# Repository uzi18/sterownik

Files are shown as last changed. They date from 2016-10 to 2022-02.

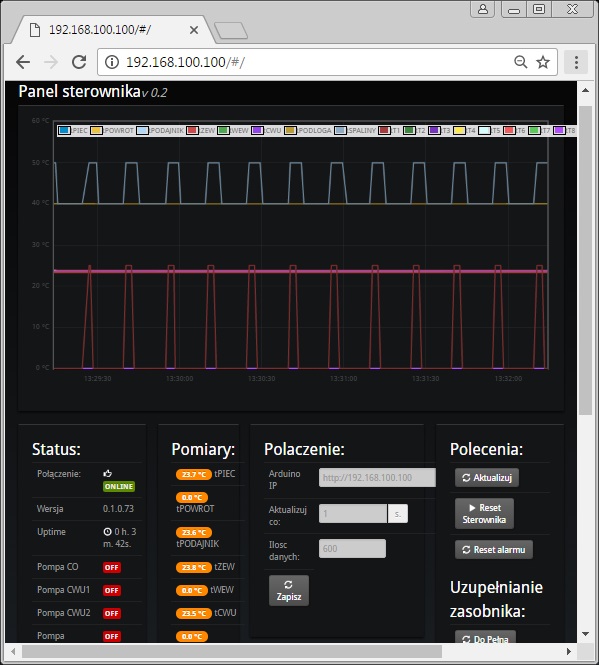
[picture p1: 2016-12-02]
arduino/img/pierwsze_uruchomienie/strona.jpg

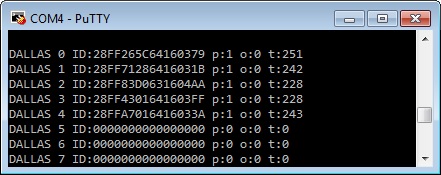
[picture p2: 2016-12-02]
arduino/img/pierwsze_uruchomienie/putty1.jpg

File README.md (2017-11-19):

## repozytorium zawiera: 

* Lucjan (katalog arduino) - sterownik pieca CO na bazie Arduino Mega w tym schematy, wsad i wiele innych
* skrypty w python dla eCoal.pl/bruli.pl dla nie wspierancyh juz sterowników

## Wszelkie błędy, propozycje zmian i dodatkowe funkcje zgłaszamy w [Issues](https://github.com/uzi18/sterownik/issues)
  * [Issues](https://github.com/uzi18/sterownik/issues) zgłaszane przez osoby wspierające Lucjana będą rozpatrywane z pierwszeństwem.  
  * Na [stronie wsparcia](https://www.paypal.me/wsparcieDlaLucjana) w uwagach prosze podawać nr. [issue](https://github.com/uzi18/sterownik/issues), którego sie tyczy.  
  
## Zapraszamy do dyskusji ONLINE - kliknij na link: 

## Podoba Ci się projekt, kliknij i wesprzyj Lucjana:

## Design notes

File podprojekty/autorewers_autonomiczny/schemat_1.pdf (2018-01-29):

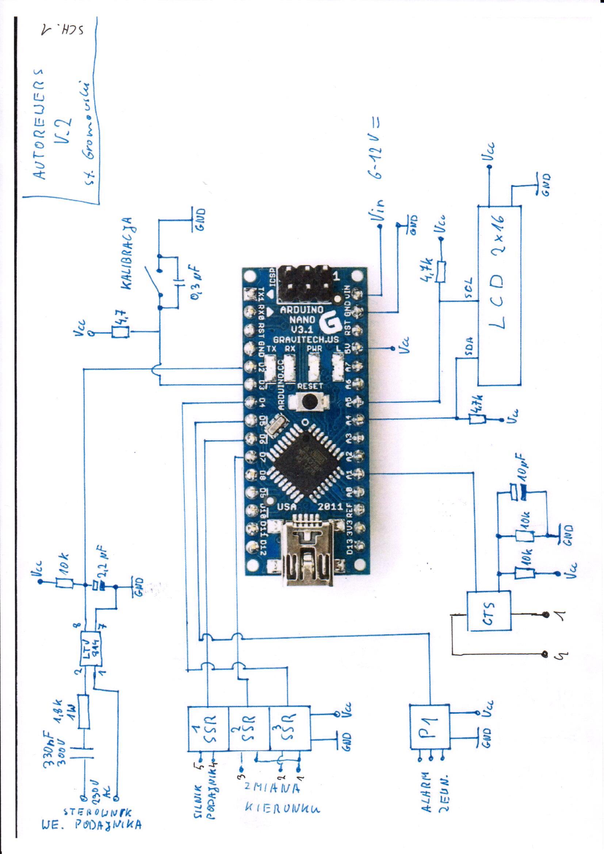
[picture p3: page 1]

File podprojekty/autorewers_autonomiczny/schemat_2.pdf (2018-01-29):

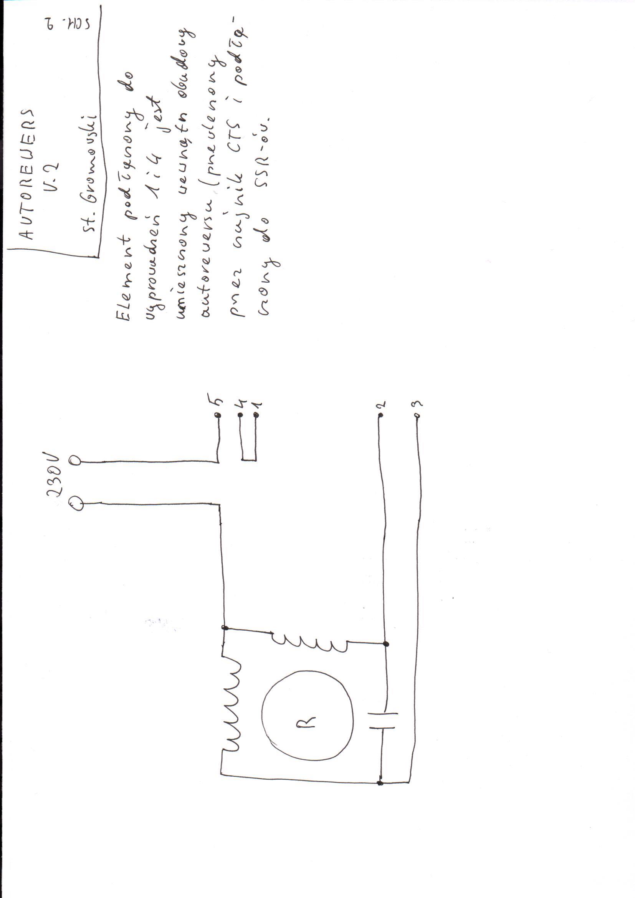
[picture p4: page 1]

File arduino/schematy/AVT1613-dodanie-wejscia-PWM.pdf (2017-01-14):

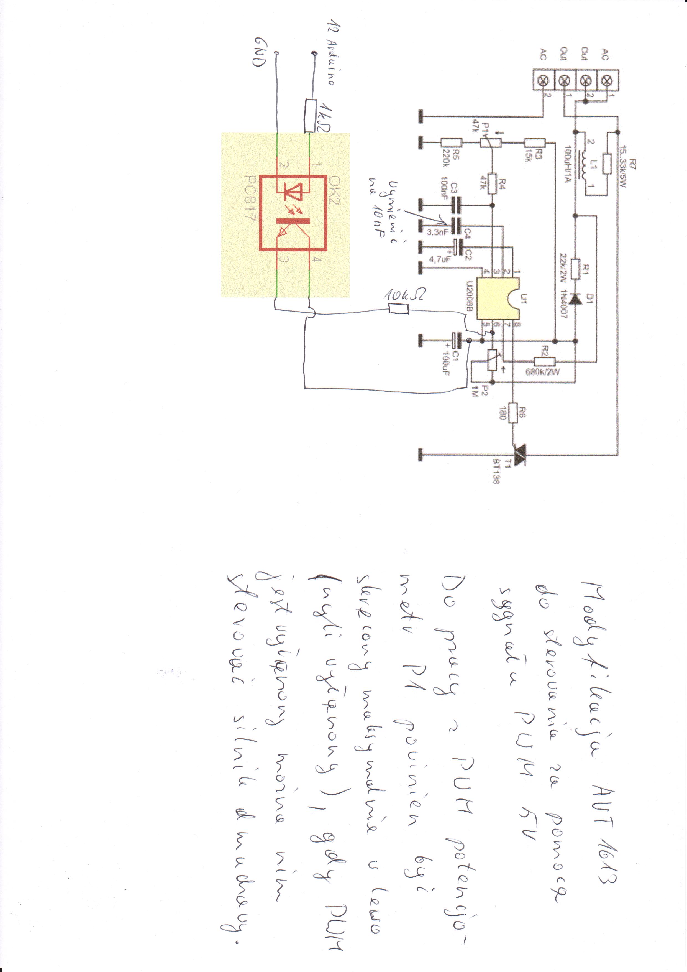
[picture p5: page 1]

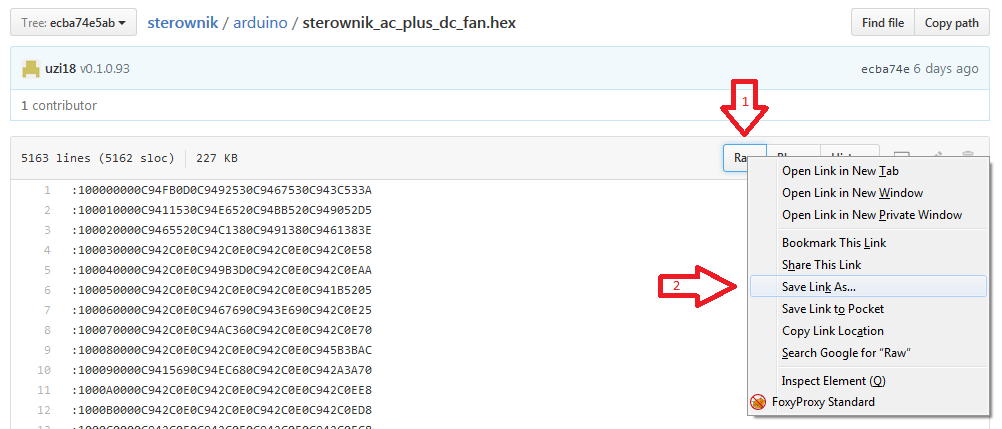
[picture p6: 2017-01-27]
arduino/img/pierwsze_uruchomienie/download_lucjan2.png

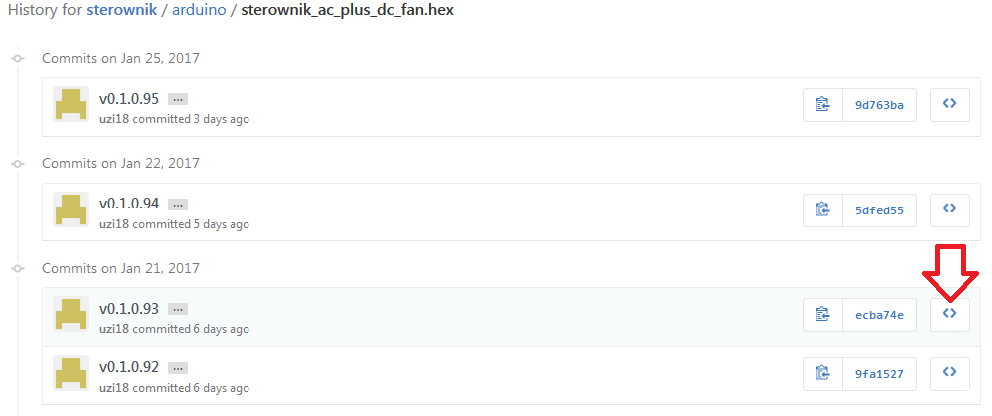
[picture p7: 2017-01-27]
arduino/img/pierwsze_uruchomienie/download_lucjan1.png

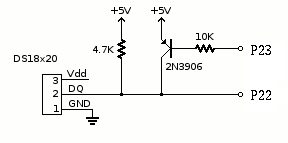
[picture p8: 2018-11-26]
arduino/dokumentacja/pics/1wire-aktywne_podciagniecie.png

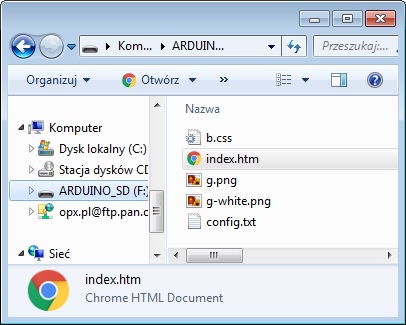
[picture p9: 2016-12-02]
arduino/img/pierwsze_uruchomienie/katalog.jpg

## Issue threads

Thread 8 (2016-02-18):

dmuchawa AC - moduły

uzi18, 2016-02-18:
dmuchawa AC sterowana moze byc poprzez optotriak i triak - wymagany jest tez detektor zera sieci
lub
zmodyfikowany modul avt-1613 (dostepny w sprzedazy) z wyjscia PWM
lub
modul avt-3113 (niedostepny w sprzedazy) z wyjscia PWM

bzykbzyk, 2016-02-20:
uzi18, jesteś pewny że avt-3113 nadaje się do sterowania silników asynchronicznych? Producent twierdzi, że przeznaczony jest do komutatorowych.

uzi18, 2016-02-25:
jestem pewny, w tym tygodniu przyjda płytki to zloze i sprawdze ale to jest praktycznie to samo co Stan zmontowal z 1613 i fragmentu z 3113 wiec nie ma innej mozliwosci

uzi18, 2016-09-12:
Podsumowując moje testy:
avt3113 - działa poprawnie : sygnał 0V-0% 5V-100%, mozliwosc regulacji minimalnych i maksymalnych obrotów oraz biegu jałowego, przy 100% obroty troszke pływają wiec warto zjechac troszke z obrotów maksymalnych potencjometrem na module

avt1613-zmodyfikowany wg Stan - działa poprawnie poza tym ze wymaga odwroconego sygnału (5V-0% 0V-100%) i u mnie na 0% dmuchawa sie nie potrafi zatrzymać.

triak-optotriak+detekcja zera - w trakcie testów

bzykbzyk, 2016-09-16:
avt3113 niestety niedostępny

uzi18, 2016-09-16:
Aktualizacja:

avt1613-zmodyfikowany wg Stan - działa poprawnie,
wg. mnie kiepskie mozliwosci regulacji wzgledem 3113, prawdopodobnie mozna to jeszcze dopracowac
wczesniej zle dzialala bo u2008b mialem w podstawce,  najlepiej przylutowac go bezposrednio do plytki

avt3113- jest niedostepna i producent nie ma zamiaru jej wznowic do sprzedazy

mark3k3, 2016-09-18:
Ogólnie, moduł AVT1613 działa dość poprawnie, jednak PWM nie może wysterować wentylatorem na MAX. MAX obroty nie są nam potrzebne, dlatego takie wykonanie modułu wykonawczego sterowania dmuchawą jest jak najbardziej akceptowalne i przydatne.

bzykbzyk, 2016-10-01:
Dla dmuchawy nie jest potrzebne 100%, ale już np dla pompy tak.
Chciałbym w przyszłości wykorzystać Lucjana również do sterowania panelami słonecznymi i obrotami pompy: w zależności od różnicy temperatur przed i za panelami. Muszę zbudować układ na wzór avt3113, skoro lepiej steruje.

uzi18, 2016-10-01:
Moze dla pompy zakres regulacji na avt1613 tez wystarcza.

W dniu 1 października 2016 19:43 użytkownik bzykbzyk <
notifications@github.com> napisał:

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

bzykbzyk, 2016-10-01:
Muszę zatem zbudować jakieś stanowisko do pomiaru obrotów pompy i sprawdzić jak się zachowuje. Nawet jak by nie było max 100%, można w ostateczności zewrzeć regulator stykiem przekaźnika.

uzi18, 2016-10-01:
Mozna ustawic/wyregulowac plytke 1613 aby byl zakres od 40%-100%.

uzi18, 2016-10-06:
Moge potwierdzic ze swojej strony ze dmuchawka AC sterowana
bezposrednio z Lucjana w  konfiguracji - detektor zera, optotriak, triak - smiga az milo ...

bzykbzyk, 2016-10-07:
Mój piec na razie w gotowości do palenia. Przestawiam trochę szpeje w kotłowni więc brak czasu. Czekam na moduł triaków.
Skoro 1679 działa zadowalająco (w całym zakresie obrotów?) to rezygnujemy z 1613?
Dlaczego sterujesz triakami z wyjść analogowych a nie cyfrowych (dmuchawa - wiadomo)?
Uaktualniłem schemat (bez przekaźników na razie, info w wątku o przekaźnikach).

uzi18, 2016-10-08:
Jezcze troche i zrobimy porzadki z wyjsciami.
Wyjscie na opto to jakiekolwiek zwykle wyjscie cyfrowe.

Czekam na wasze testy z moc3020, na razie nikt nie potwierdzil poprawnej
pracy, a 1613/3113 jest dobra alternatywa.

bzykbzyk, 2016-10-08:
Przy porządkowaniu wyjść, rozpatrz przeniesienie gdzieś sygnałów DO i CLK termopary, dla triaków "cyfrowych" można by przeznaczyć wyjścia 46 -55 - zrobić kabelek 10 żyłowy (wtyk - gniazdo) kanda -  pewnie i prosto podpiąć moduł triaków (nie przerabiany) do mega jedną taśmą. W tej chwili wykorzystujemy już 8 wyjść do sterowań, lada chwila trzeba dołożyć kolejny moduł triaków. Jakaś pompa np do solarów też ładnie by hulała ze zmienną prędkością zależną od temp.

ravikjab, 2016-10-11:
uruchomiłem dmuchawę na MOC3020 i po wstępnych testach praca dmuchawy WPA01 jest wielce obiecująca. Jest większa moc względem AV1613. Dmuchawa w trybie modulacji bez problemów zmienia predkość.
Więcej informacji przekaże po dłuższych testach.

uzi18, 2016-10-18:
ktoś jeszcze testował?

uzi18, 2016-11-05:
v0.1.0.66
        - sterowanie triakiem dmuchawy (A13) zdublowane na pin 32

Docelowo będziemy musieli przenieść się z pinów Ax (zwłaszcza dmuchawa)z prostej przyczyny - procesor ma jakiś bug powodujący zakłócenia na wyjściach przełączanych z "wysoką" częstotliwością.

Tym samym czekam na potwierdzenie ze dmuchawa sterowana optotriak/triak działa już
poprawnie po podłączeniu pod pin 32.
A13 z czasem ... będzie to testów czujników np. KTY81-210.

mark-markowski, 2016-11-06:
Potwierdzam prawidłowe działanie dmuchawy na pinie nr. 32. Modulacja działa płynnie i precyzyjnie.

uzi18, 2016-11-27:
Rozumiem,że działa więc zamykam.

Closed 2016-11-27.

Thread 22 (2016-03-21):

detekcja przeciążenia silnika podajnika

bzykbzyk, 2016-03-21:
Pomiar prądu silnika podajnika - przeciążenie - włączenie pracy nawrotnej

uzi18, 2016-03-21:
zrobimy testy na ACS712 w wersji 5A, moze uda sie wylapac tez zerwanie zawleczki

Stan17, 2016-04-15:
Testy zrobione, ACS712 i AC-MAX-30A, zerwanie zawleczki jest raczej nie do wykrycia ale przeciążenie na pewno tak.

bzykbzyk, 2016-04-17:
AC-MAX-30A ma jakąś elektronikę? Czy to tylko transformator i na wyjściu prąd zmienny do wykorzystania? Jakieś schematy do wrzucenia?

uzi18, 2016-04-17:
Ma rezystor i diody zabezpieczajace na wyjsciu trafa, wykonania sa rozne.

bzykbzyk, 2016-04-17:
uzi18
Ha, czujny jesteś. Napisałeś odpowiedź na moje pytanie o konstrukcji AC-MAX-30A, które po kilku minutach usunąłem bo znalazłem ją w sieci. Skoro twierdzisz że są różne wykonania, to nie jest dobrze. To utrudnia unifikację. Może sam coś zbuduję. Te 30A wydaje mi się za dużo do  naszego zastosowania, skoro mamy mierzyć prądy w okolicach 1A. 30 amperowe mają przekładnię 1800:1 muszę zrobić przekładnik o mniejszym przełożeniu. Widzę też w sieci 5, 10, 15A
Stan17,
dlaczego twierdzisz, że zerwanie zawleczki nie do wykrycia? Przecież to musi być większy prąd niż przeciążenie.
W jakim układzie to testujesz? Daj go, zbuduję to samo i sprawdzę

uzi18, 2016-04-17:
Efekt na kazdym czujniku jest ten sam, one sie glownie rezystorem roznia, w zaleznosci od pradu, kalibracje najpewniej i tak kazdy bedzie musial zrobic

Stan17, 2016-04-18:
Dlaczego tak myślę ? Ponieważ kiedyś to zmierzyłem i różnica między prądem normalnej pracy a prądem pracy z odłączonym ślimakiem wynosiła około 0,1 A.

Tu masz przykład którym się posłużyłem.
http://akademia.nettigo.pl/power_meter/

micro-jr, 2016-04-18:
nie prościej w okolicach zawleczki zamontować jakiś czujnik obrotu ślimaka?
silnik chodzi, czujnik kręci - OK
silnik chodzi - czujnik nie kręci - zerwana zawleczka
silnik nie chodzi, czujnik nie kręci - OK
silnik nie chodzi, czujnik kręci - ??

Stan17, 2016-04-18:
Ale głównym celem nie jest wykrycie zerwania zawleczki, to tylko dodatek.
Podstawową sprawą tutaj jest wykrycie przeciążenia zanim zostanie zerwana zawleczka, wykonanie ćwierć/pół obrotu ślimaka wstecz i powrót do normalnych obrotów.

micro-jr, 2016-04-18:
no to pytanie jaki jest pobór podczas przeciążenia, a nie pracy bez zawleczki.
bo jeśli do ścięcia zawleczki potrzeba 0,1A więcej, to słabo to widzę... chociaż z drugiej strony, pewnie, przed zerwaniem zawleczki, obroty silnika mocno spadają - a zatem po ilości obrotów (silnika, a nie ślimaka) można by reagować  - jeśli podajemy prąd, a ilość obrotów gwałtownie spadła to mamy awarię.

uzi18, 2016-04-18:
Nie o to chodzi, ten czujnik daje nam wiecej informacji, ktore odpowiednio
analizujac mozemy dobrze wykorzystac

Stan17, 2016-04-18:
Ale ja nie to napisałem.
To oczywiste że do ścięcia potrzeba o wiele większego prądu.
Chcemy wykryć przeciążenie i zareagować zanim nastąpi ścięcie zawleczki.

Chodzi mi o to że tak mała różnica między prądami pracy z zawleczką i bez, nie pozwoli nam w sposób absolutnie pewny stwierdzić czy po wzroście prądu w przeciążeniu i jego nagłym spadku podajnik pracuje z zawleczką czy bez.

bzykbzyk, 2016-04-20:
Mierzenie obrotów silnika (w celu detekcji ścięcia zawleczki) jest moim zdaniem bezcelowe, bo z uwagi na duże przełożenie przekładni spadek obrotów będzie (raczej) minimalny. Wszystkie występujące na rynku podobne układy bazują na pomiarze prądu silnika. Widziałem układ z pomiarem różnicy obrotów pomiędzy ślimakiem a reduktorem (czujnik Halla plus magnesy). Jeśli różna od 1 = ścięta zawleczka.  Był to układ tylko do detekcji ścięcia. Tylko po co taka wiedza (za parę stów - bo tyle tamten kosztował)? Skoro sterownik podaje sterowanie na silnik a temperatura nie rośnie to znaczy, że brak paliwa lub zerwana zawleczka. Jedno i drugie wiąże się z wizytą w kotłowni.
Cała zabawa w tym wątku ma zakończyć się budową układu detekcji przeciążenia (zablokowania) podajnika grożącego uszkodzeniem szpejów wartości co najmniej tysiaka a nie zawleczki wartej ćwierć złocisza.
Jeśli uda się zbudować skuteczny układ, to z czystym sumieniem wymienimy zawleczki na utwardzone śruby ponieważ rola zawleczki zostanie przejęta przez ten układ. Takie rozwiązanie jest stosowanie przez kilku producentów "elektronicznych zawleczek".

**uzi18,**
Dopiszże w wolnej chwili kawałek kodu do pomiaru prądu układem ACS712 5A z wizualizacją na wykresie (łatwiej będzie analizować pracę podajnika).

uzi18, 2016-04-20:
Stan tez o to prosil, aby dopisac jakis kod do tego czujnika, zobacze co da sie zrobic.

micro-jr, 2016-04-21:
Jeżeli silnik jest w trybie pracuj, ale się nie obraca - znaczy ze doszło do zacięcia.
czy silnik ma pracować wiemy - bo to My decydujemy.
pozostaje wykryć, czy silnik/Przekładania się obraca.

zakładając, ze silnik obraca się szybciej niż podajnijk i jesteśmy w stanie określić z jakimiś interwałem o ile się obraca, jeśli w zadanym czasie obrót nie nastąpił, a silnik pracował - mamy zacięcie silnika.

nie wiem jaka jest czułość czujników obrotu "za 30 pln" i czy da się taki założyć przed przekładnią, bo tam są większe obroty - szybciej powinna nastąpić zmiana - mamy mniejsze opóźnienie.

Stan17, 2016-04-21:
Na połaczeniu  silnika z motoreduktorem nie ma gdzie go zamontować, jedyne miejsce to wykrycie obrotu wentylatora silnika.
Jeśli chcesz to próbuj takiego rozwiązania, ja jednak pozostanę przy wykryciu przeciążenia :-)

uzi18, 2016-04-21:
Panowie przetestujmy wpierw jedno rozwiazanie z czujnikiem pradu, pozniej sie zastanowimy czy jest wystarczajace.

Moim zdaniem czujnik śruby na ślimaku daje za rzadko informacje o obrocie, zakładając ze kilka sekund na cykl podawania to tez mało na 1/2 lub cały obrót ślimaka.

My chcięlibyśmy mieć informacje z wyprzedzeniem zanim zetniemy zawleczkę, a pozniej zareagować kilkusekundowa zmiana obrotów silnika.

bzykbzyk, 2016-04-28:
Mój ślimak wykonuje 10 obrotów w czasie 8min. Silnik (wg tabliczki zn) - 1430 obr/min. Daje to przełożenie ok 1150:1.
Moim zdaniem nawet po zablokowaniu ślimaka spadek obrotów silnika będzie minimalny, raczej nie mierzalny domowymi sposobami.

Ostatnio chciałem zmierzyć przyrost prądu silnika po obciążeniu (zablokowaniu) ślimaka.
Mam sprawny układ testowy: silnik z przekładnią zdemontowany z pieca przeznaczonego na złom. Ślimak ucięty szlifierką, ponieważ została ścięta zawleczka i przekładnia "zblokowała się" ze ślimakiem. Przygotowałem szlifierką "kikut" ślimaka, by pasował do klucza płaskiego 22. Założyłem klucz tak, aby po kilku sekundach obrotu zablokował się opierając o korpus, podłączyłem arduino z ACS712 5A. Z uwagi na brak zawleczki sądziłem, że klucz na kikucie ślimaka będzie wystarczający do przezwyciężenia blokady z przekładnią.
Wyniki:
Prąd max > ok 10% od znamionowego.
Na szczęście stałem poza trajektorią przelotu części klucza.
Szkoda tylko zniszczonego klucza vanad (miałem jeszcze zwykły, stalowy, mogłem użyć jego...).

Wnioski:
Układ przeciążenia trzeba testować podczas normalnej pracy napędu, z zawleczką fabryczną.
Rejestrować przeciążenia, czekać na zerwanie zawleczki. Odczytać wartości zarejestrowane w czasie zerwania, ustawić kilka % niższą, jako wyzwalającą układ do pracy nawrotnej.

ACS712 5A nie jest zbyt precyzyjny. Z uwagi na charakter pomiaru (cz Halla) nie jest odporny na zakłócające pole magnetyczne.
Program w arduino z którego korzystam podczas obciążenia wskazuje podobny prąd do zmierzonego przyrządem, a bez obciążenia to 0,25-0,3A. Bez sensu.
Proszę o kod z którego Wy korzystacie, może tu jest przyczyna?

uzi18, 2016-09-08:
Jestem na etapie składania modułu pomiarowego, niebawem dam znac jakie efekty :)

uzi18, 2016-09-18:
Mysle ze bedzie wybor miedzy termometrem silnika a modulem pomiaru obciazenia.
bzyk: jak mozesz to wrysuj detektor zera sieci za bezpiecznikiem od peryferiow ...
bedzie dzieki temu zarazem detektorem przepalenia bezpiecznika :)

bzykbzyk, 2016-09-19:
Za bezpiecznikiem AVT1679? Mogę wrysować, ale czy da się to fizycznie wykonać?

uzi18, 2016-09-19:
U siebie przylutowalem przewod za bepiecznikiem

bzykbzyk, 2016-09-19:
Ok, wrysuję mostki zamiast bezpieczników i jeden wspólny do wszystkiego prócz zasilacza.

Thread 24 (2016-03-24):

Wyjścia sterujące przekażnikami

bzykbzyk, 2016-03-24:
Przydała by się wersja programu sterująca modułem przekaźników zamiast triaków ew
mogą to być dodatkowe wyjścia z odwróconą polaryzacją bo popularne moduły wymagają sterowania wysokim poziomem.
Albo zmienna w programie zmieniająca poziom na poszczególnych wyjściach.

uzi18, 2016-03-24:
pokaz co to za moduly - link?

bzykbzyk, 2016-03-25:
Etam będę Ci linkował, obrazki pokażę. Występują pod nazwą "moduł przekaźnikowy arduino" od jednego do ośmiu, z optoizolacją.
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

Stan17, 2016-03-25:
Nie wiem czy przekaźniki to dobry pomysł, to jest dość zawodny element.

uzi18, 2016-03-25:
Ale te przekazniki maja styk NO i NC wystarczy ze obciazenie podlaczysz do drugiego i bedziesz mial odwrocony sygnal na wyjsciu

micro-jr, 2016-03-25:
Nie odwrócony. Tylko normalnie zwarty lub normalnie otwarty. Jeśli potrzebujesz żeby coś chodziło przez 90% czasu to lepiej sterować wtedy czasem wyłączenia. W piaszczysta wtedy t a ka rzecz w normalnie zwarty. A w sterowniku ustawiasz jako aktywny port 0 wówczas jest to zwarte kiedy przekaźnik nie pracuje.podanie jedynki na sterowniku zmieni stan przekaźnika na prace i rozewrze obwód. Oszczędza to przekaźnik.

Pokazane na zdjęciu układy to opto przekaźniki.  Ich zaletą jest izolacja galwaniczna obwodów. Jeśli nie ma błędu ma płytce zwiększa odporność systemu na przecięcia.

bzykbzyk, 2016-03-25:
Przekaźniki może i zawodne, ale kilka razy zdarzyło mi się, że po zwarciu nawet styki się nie zgrzały a triak to kosz.
Nie można korzystać z NC styku, bo po wyłączeniu sterownika z jakiegokolwiek powodu (choćby reset) wszystkie obwody zostaną zasilone, co np dla zaworu 4d może być zabójcze.

uzi18, 2016-03-25:
Dlatego przed triakami daje sie bezpiecznik :)

bzykbzyk, 2016-03-27:
Bezpiecznik nawet szybki nie zabezpiecza w 100% triaka. Nieraz zadziałał bezp i triak kosz.

uzi18, 2016-03-27:
Przed wszystkim sie nie zabezpieczysz niestety.

Stan17, 2016-03-27:
Nie wiem jak wy, ale ja wolę w razie awarii wymienić triaka niż przekaźnik wlutowany.
Ale co kto woli :-)

uzi18, 2016-03-27:
Bzyk pozwol ze na razie zajme sie rozwinieciem tego co juz mamy, temat dopisze do ulepszen, na ten czas mozna zastosowac sprzetowa inwersje, moze znajdziesz gotowy modul?

Dodanie inwersji w tym momencie komplikuje troszke sprawe, bo mamy kilka innych problemow do rozwiazania.

Dodaje temat do ulepszen, zgloszenie zostawiam otwarte

uzi18, 2016-03-27:
Mozna tez sprobowac w prosty sposob przerobic modul przekaznikow aby sygnal nie musial byc odwracany ...

uzi18, 2016-03-27:
#232d8548631ae3c2d7efac8581f78b6af6d77a82

uzi18, 2016-03-27:
dodane w 0.1.0.39 - prosze o testy

bzykbzyk, 2016-03-29:
Dziękuję za wersję dla przekaźników. Pewnie, że można by te moduły przerobić, ale kłóciło by się to z zasadą, aby korzystać jak najbardziej z gotowych rozwiązań.
 Z uwagi na połączenia, dobrzy by było zaprogramować parzyste wyjścia sterujące 24, 26, itd.

uzi18, 2016-03-29:
parzyste naprawde cos dadza, bo nie wiem jak to rozumiec?

Mozesz dorysowac na schemacie modul rtc "ds1307+24c32", podlaczone vcc,gnd,scl,sda

bzykbzyk, 2016-03-29:
Chodzi o podłączenie do pinów arduino elementów wykonawczych i czujników. Można użyć "Złącze ARK do płytki stykowej", ma wyprowadzenia gold pinów w jednym rzędzie. A to właśnie parzyste piny 22 - do DS oraz 24, 26 itd do przekaźników. Docelowo (jeśli to nie byłby problem) lepiej by było wykorzystać jednak już te od triaków, (coby nie dublować wyjść) zmieniając im tylko polaryzację (może jakieś zmienne do ustawienia w config).
Jeśli chodzi o moduły przekaźnikowe, to gapa ze mnie, występują też sterowane wysokim potencjałem.
Schemat uaktualnię.

uzi18, 2016-03-29:
To fajny pomysl z tymi zlaczami jednak jest to dosc ograniczone jesli chodzi o mozliwosci podlaczenia, za to wydaje mi sie ze widzialem gdzies gotowce na cala plytke ...

bzykbzyk, 2016-03-29:
Są na całą Mega, ale nie miałem tego w łapkach, więc trudno określić czy się nada.
Niestety Lucjan w tej chwili na biurku, jestem na etapie szycia mu nowego garnituru, czyli obudowy.
Czekam na gniazda C13, moduł pomiaru prądu nie może dotrzeć (przesilenie na poczcie), regulator ac dmuchawy czeka na złożenie, i ... trochę mało czasu, więc wszystko opornie idzie. Każdy nowy wsad testuję na biurku, symulacja pieca to lampa biurkowa i zapalniczka. Od kilkunastu dni w ruchu, pracuje stabilnie. Nie grzeję cwu węglem (na razie - w planie zasobnik samoróbka, szukam zbiornika hydroforowego z demobilu) więc z uwagi na temperatury zewnętrzne piec wygaszony.

uzi18, 2016-03-29:
dopisalem troche rzeczy do wiki ...

bzykbzyk, 2016-03-30:
Ta płytka to do testów jedynie. Niestety nie ma wyprowadzonych zacisków śrubowych na D22 do D53

uzi18, 2016-03-30:
Ma za to pola gdzie mozna takie lub inne zlacze przylutowac

bzykbzyk, 2016-03-30:
No niestety, nie jest to takie proste, bo złącze śrubowe typu ARK ma raster 5mm a w Arduino jest 2,5mm, stad moja propozycja  "Złącze ARK do płytki stykowej"

uzi18, 2016-03-31:
Ok, uwolnie teraz zlacza analogowych wejsc i zrobimy na parzystych od 24 stan niski aktywny a na nieparzystych wysoki aktywny, chociaz to marnotrastwo ale na razie musi tak byc.
Miałem plan aby 24-55 uzyc do innych celów.

bzykbzyk, 2016-04-01:
Nie można by nie dublować, ale z użyciem parametrów w config załatwić sprawę? Wiadomo, że kawałek kodu musiałbyś skrobnąć i nie musi być to od razu.
Na schemacie jeszcze nie wszystko ok, wejścia sterujące przekaźników trzeba spolaryzować do plusa.
Jakiś duży mi ten plik teraz wyszedł...
Znalazłem schield do Mega z rozszyciem D24-50 na śrubowe,
[https://www.tindie.com/products/duanebenson/universal-screw-block-proto-shield-system-for-arduino/](url)
lub
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

ale cena zabójcza. Muszę coś innego wymyślić np w oparciu o płytkę uniwersalną.

ravikjab, 2016-09-22:
Zauważyłem chyba błąd w sterowaniu gdyż przy ustawieniu TPIECA na 50 st i histereza na 2 st. to przy spadaniu temp podajnik właczył się przy 47,9 st (czyli prawidłowo), natomiast gdy temp rosła to już po przekroczeniu 48 st podajnik przestał się właczać a powinien pracować do uzyskania nastawionej temperatury 50 st.
W tym momencie korzystam z przekaźników.

uzi18, 2016-09-22:
Dodalem to jako błąd, do weryfikacji.

uzi18, 2016-09-25:
Dodalem nastepne wyjscia dla przekaznikow w wersji v.0.1.0.47

bzykbzyk, 2016-10-07:
Uwolnij wyjścia cyfrowe 24 - 30. Nie ma sensu sterować przekaźnikami stanem niskim, skoro są dostępne moduły sterowane wysokim a nawet mające możliwość konfiguracji stanu przełączania (załączenie przekaźnika wysokim lub niskim).
Jak ktoś będzie chciał jednak przekaźniki, może je włączyć zamiast triaków.
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.

uzi18, 2016-10-08:
Ok przemyslimy sprawe, kto uzywa jeszcze zwyklego modulu przekaznikow?

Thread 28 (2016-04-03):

Uwagi do www

bzykbzyk, 2016-04-03:
Błędnie opisany poziom zasobnika. Jest "Poziom podajnika".
Po dodaniu paliwa, ilość w "Poziom podajnika" się nie zwiększa, tzn wygląda jakbyśmy zasypywali pusty zasobnik.
Ile to jest "Do pełna"?. Są różne zasobniki.

Można ustawić "Aktualizuj co:" jako liczbę ujemną.

Stan17, 2016-04-03:
U mnie poziom się zwiększa lub zmniejsza zależy ile "wsypię", zasyp działa inaczej niż w sterach ES, tzn gdy wpisujesz ile kilogramów to nie oznacza ile wsypałeś tylko ile masz w zasobniku czyli łączna ilość to co wsypałeś plus to co tam ewentualnie zostało.

Do pełna określasz w configu
> #czas w sekundach potrzebny do oproznienia pełnego zasobnika
> PODAJNIK_CZAS_DO_OPROZNIENIA = 69000

Ale w konfigu jest niekonsekwencja, w opisie mamy to usunąć
> #aktualny czas pozostaly do oproznienia zasobnika w sekundach
> #po uruchomieniu zliczamy od tej wartosci (domyslnie 50% zasobnika)
> PODAJNIK_CZAS_PODAJNIKA = 34500
A w aktualnym konfigu ciągle to jest.

uzi18, 2016-04-03:
Podajnik_czas_podajnika sluzy teraz tylko do ustawienia wartosci poczatkowej, generalnie nie ma potrzeby tego uzywac i niebawem chyba to wyrzuce.
Pozostawienie tej linijki spowoduje ze po resecie czas znow bedzie wpisany taki jak w parametrze a raczej tego noe chcemy ;)
Dosypywanie zrobie, moze nawet dzis.

bzykbzyk, 2016-04-03:
A o co tu chodzi:
> Jeśli ustawię czas podawania na 10, to po "Zasypano" 100kg
mam "Poziom podajnika" 869,6%,
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
a po ustawieniu czasu na 200 - to samo 100kg daje "Poziom podajnika" 54,3%
(teraz 43%!)
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

>Można ustawić "Aktualizuj co:" jako liczbę ujemną.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

uzi18, 2016-04-03:
Pokaz zawartosc pliku config.txt

bzykbzyk, 2016-04-03:
#czas w sekundach potrzebny do oproznienia pe�nego zasobnika
PODAJNIK_CZAS_DO_OPROZNIENIA = 69000
#aktualny czas pozostaly do oproznienia zasobnika w sekundach
#sta�a zalezna od opa�u w g./min.
PODAJNIK_PREDKOSC_PODAWANIA =200
zabezpieczenie przed zbyt wysoka temperatura pieca
KOCIOL_T_MAX = 90

temperatura zalaczenia pomp
PIEC_T_MIN = 0

tryb pracy pieca (palnika) - zgodny z ECOAL,RR,RRM,...
PIEC_ALGORYTM = RR
PIEC_ZADANA = 70
PIEC_HISTEREZA = 2

parametry algorytmu RR, czas podtrzymania w minutach, reszta w sekundach:
RR_PODTRZYMANIE_CZAS = 10
RR_PODTRZYMANIE_PODANIE = 10
RR_PODTRZYMANIE_POSTOJ = 30
RR_PODTRZYMANIE_MOC = 40

RR_PRACA_PODANIE = 2
RR_PRACA_POSTOJ = 5
RR_PRACA_MOC = 23

tryb pracy pompy co (ECOAL,BRULI,ZIMA,LATO)
CO_TRYB = ZIMA
algorytm pracy pomy CO (CIAGLY,CYKLICZNY)
CO_ALGORYTM = CIAGLY

tryb pracy pompy cwu (ECOAL,BRULI,WLACZ,WYLACZ)
CWU_TRYB = WYLACZ
algorytm pracy pomy cwu (CIAGLY,CYKLICZNY)
CWU_ALGORYTM = CIAGLY
CWU_ZADANA = 40
CWU_HISTEREZA = 0

bzykbzyk, 2016-04-04:
Już zaskoczyłem, gdzie popełniam błąd.
W obydwu przypadkach zmiany parametru PODAJNIK_PREDKOSC_PODAWANIA miałem tą samą wartość PODAJNIK_CZAS_DO_OPROZNIENIA. Nie zrozumiałem co to za parametr PODAJNIK_CZAS_DO_OPROZNIENIA, a to przecież pojemność zasobnika przeliczona na sekundy pracy podajnika.
Moim zdaniem, ten parametr powinien być wyliczany przez program a nie wprowadzany ręcznie.
Powinno się podać pojemność zasobnika w kg z instrukcji pieca (albo z doświadczenia - wsypując węgiel do zasobnika) i zmierzoną wartość parametru PODAJNIK_PREDKOSC_PODAWANIA.
Chociaż może niepotrzebnie kombinuję, niech Programista zdecyduje.

Brakuje mi za to na stronie czasu pracy do końca paliwa w zasobniku.

Stan17, 2016-04-04:
Ja podorabiamy różne statystyki to pewnie tak, na razie nie mamy praktycznie żadnych.
Wczoraj właśnie rozmawialiśmy na temat zrobienia pierwszej prostej statystyki zużycia dobowego węgla w okresie 7 dni.
Z tą sprawą nie ma to żadnego związku ale stanowiłoby pierwszy krok do utworzenia statystyk.

uzi18, 2016-04-06:
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

bzykbzyk, 2016-04-07:
Tak, teraz to już ładnie i czytelnie. Jakoś nie mogę uwierzyć w te 8,7kg na dobę Stan'a....

Stan17, 2016-04-07:
To jest wartość chwilowa, zaraz po uruchomieniu,  najpierw jest bardzo wysoka a po chwili spada mocno i dopiero po kilku godzinach pracy się stabilizuje, teraz mam około 11-12 kg

ravikjab, 2016-09-21:
Do interface www:
- przydałoby się żeby wyświetlane były ustawione wartości parametrów np. TPIEC, TCWU, TPODAJNIKDo
- możliwość określenia na wykresie czasu prezentacji wyników (ostatnie 10 min daje słaby obraz tego co działo się np z CWU a dzięki temu można poszukać oszczędności np przez określenie czasu pracy pompy cyrkulacyjnej włączając ją wtedy gdy faktycznie jest potrzebna)

uzi18, 2016-09-21:
Probowales zmienic czestotliwosc odswiezania "aktualizuj co" na 60?

ravikjab, 2016-09-21:
Ok jest lepiej ale i tak fajnie było by gdyby można określić zakres który nas interesuje bez utraty dokładności

Stan17, 2018-02-08:
Myślę że na www kontrolki wentylator i wentylator_mod bardziej pasują do bloku status niż pomiary ?

uzi18, 2018-02-08:
racja, mozna je przeniesc :)

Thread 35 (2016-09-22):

RR: problem z histereza przy paleniu

uzi18, 2016-09-22:
Zauważyłem chyba błąd w sterowaniu gdyż przy ustawieniu TPIECA na 50 st i histereza na 2 st. to przy spadaniu temp podajnik właczył się przy 47,9 st (czyli prawidłowo), natomiast gdy temp rosła to już po przekroczeniu 48 st podajnik przestał się właczać a powinien pracować do uzyskania nastawionej temperatury 50 st.

uzi18, 2016-09-23:
faktycznie to jest do poprawki

uzi18, 2016-09-23:
poprawione w #d73161670b15a94e1a202113f096e97f53496d42

ravikjab, 2016-09-24:
nie wyłącza się podajnik i dmuchawa pomimo przekroczenia ustawionej tPIEC.

uzi18, 2016-09-25:
wklej tutaj swoj config.txt

uzi18, 2016-09-25:
naprawione w v.0.1.0.47

Closed 2016-09-25.

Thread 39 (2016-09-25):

Buzer awarii

ravikjab, 2016-09-25:
Należy dodać zewnętrzny buzer do alarmów przekroczonej tPODAJNK, pustego zbiornika, uszkodzonego któregoś czujnika oraz awarii napędu podajnika. Różne częstotliwości dla różnych awarii by bez logowania szybko móc zlokalizować awarie

ravikjab, 2016-11-02:
Dodać wyjście na buzer podczas awarii.

uzi18, 2016-11-03:
dodane w wersji v0.1.0.65
podpinamy pod pin 31 - Low Level Trigger Buzzer Module

Closed 2016-11-03.

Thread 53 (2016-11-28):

Monit o nowej wersji

uzi18, 2016-11-28:
Kto chce informacje o aktualizacji prosze dodawac sie to tego issue
@Stan17 @mark3k3 @bzykbzyk @ravikjab

uzi18, 2016-11-28:
v0.1.0.80
        - LCD: zmiana opisu strony PODAJNIK->ZASOBNIK
        - LCD: wsparcie dla innego typu konwertera I2C->LCD

uzi18, 2016-11-29:
Test

wwpiotr, 2016-11-29:
@wwpiotr

Stan17, 2016-11-29:
dopisuję się.

wwpiotr, 2016-11-29:
dopisane ?

uzi18, 2016-11-29:
Test

uzi18, 2016-11-29:
Test 3

uzi18, 2016-11-29:
Test 123

uzi18, 2016-11-29:
Test 5

uzi18, 2016-11-29:
v0.1.0.81
    - LCD: menu alarmow - klikniecie kasuje alarm
    - dodanie do zapytania /dallas informacji czy zmapowany (m:1 - TAK)
    - zmiana sposobu obslugi alarmow

uzi18, 2016-11-29:
v0.1.0.82
    - dodanie komendy ! w terminalu - resetowanie alarmow
    - przeniesienie sterowania pompa CWU2 w jedno miejsce
    - przeniesienie sterowania pompa CWU w jedno miejsce
    - dodanie komendy a w terminalu - drukuje liste alarmow
    - dodanie komendy d do terminala - drukuje liste dallasow

uzi18, 2016-11-29:
v0.1.0.83
    - poprawki dla buzzera

uzi18, 2016-11-30:
v0.1.0.84
        - dodanie trybu recznego
        - LCD: dodanie obslugi trybu recznego
        - podajnik przeniesienie sterowania w jedno miejsce

    v0.1.0.85
        - ENKODER: dlugie wcisniecie powoduje przejscie do ekranu trybu recznego
        - LCD: zmiana opisu akcji trybu recznego
        - LCD: dodanie informacji o trybie pracy A(uto)/R(eczny) na glownym ekranie
        - poprawki dla trybu recznego podajnika

    v0.1.0.86
        - przed wyjsciem do trybu auto wylaczamy pompy poza CO
        - dodanie mozliwosci ustawiania parametrow poprzez serial: sDM_ROZRUCH_CZAS=15

uzi18, 2016-12-01:
v0.1.0.87
        - dodanie mozliwosci symulacji czujnikow zmapowanych jako SOFT[]
        - poprawienie informacji o statusie sterowania triakiem
        - dodanie informacji o braku alarmu dla komendy a

uzi18, 2016-12-13:
v0.1.0.88
        - DALLAS: dodanie informacji o ilosci bledow komunikacji
        - dodanie typu czujnika BRAK[]
        - poprawki przy monitorowaniu detektora - 4 w konsoli
        - dodanie zapytania t.json
        - Z4D: poprawka pracy przy braku czujnika t_zew dla trybu zadanej
        - pin 35 zwarty do masy zmienia rodzaj encoder-a

uzi18, 2017-01-16:
v0.1.0.89
        - RS232: wysylamy komunikat START po przygotowaniu systemu do pracy
        - RTC: zmiana sposobu wydruku informacji o czasie
        - TRIAK: zmiana sposobu pomiaru ilosci polokresow
        - dodanie wstepnej analizy pradu podajnika
        - dodanie odczytu wejsc analogowych
        - DMUCHAWA: ustawienia poczatkowe w jednym miejscu
        - DALLAS: zwiekszenie ilosci czujnikow do 16
        - DALLAS: dodano komunikat o nieudanym dodaniu czujnika

uzi18, 2017-01-20:
v0.1.0.90
      przeniesienie termostatu z pinu A6->36

    v0.1.0.91:
        - dodanie mozliwosci mapowania MAX6675K przyklad:
        TSPALIN = MAX6675[0]
        - dodanie obslugi MAX6675K pin CS - 49
        - zmiana podlaczenia pin CS z MAX31855 A7->48
        - uzywamy wlasnej biblioteki do termopar oparych na kostkach MAX

    - aktualizacja pliku polaczen

uzi18, 2017-01-21:
v0.1.0.92
    - LCD: poprawki w wyswietlaniu wartosci ujemnych dla TZEW oraz pelniejsze nazwy czujnikow
    - LCD: dodanie strony z temperatura podajnika
    - komenda t w terminalu drukuje aktualne temperatury czujnikow

uzi18, 2017-01-24:
v0.1.0.94
    - LCD: poprawka dla strony z TZEW - nie wyczyszczony znak
    - dodanie filtrowania pomiaru dla MAX6675 - mapowac z opcja [1] tj. TSPALIN=MAX6675[1]    v0.1.0.95
        - LCD: poprawne usuniecie problemow z TZEWN na wyswietlaczu
        - dodanie opcji DETEKTOR_TESTUJE_BEZPIECZNIK=1
          dla osob ktorym nie dziala detektor lub nie testuja nim bezpiecznika
          0 - wylacza bledy bezpiecznika

uzi18, 2017-01-29:
v0.1.0.96
        - dodanie mozliwosci przypisania offsetu do czujnika przykład offset -10.0 deg.:
          OFFSET_T1=-100

    v0.1.0.97
        - pompa CO - dodanie trybu cyklicznego
        - NTP odpytujemy co 24h
        - wstepna wersja testowa pracy RRM z tlem - domyslnie wylaczona

uzi18, 2017-01-30:
v0.1.0.98
    - czesciowe dodanie nowej wersji dopalania
    - podajnik: dodanie informacji w terminalu o czasie wystapienia
      wysokiej temperatury wraz z danymi o jej wartosci
    - podajnik: dodanie wczesnego zabezpieczenia przez wysoka temperatura podajnika
    - w pierwszej fazie tła używamy poprawnej mocy nadmuchu

uzi18, 2017-01-31:
v0.1.0.103
        - dallas: tablice drukujemy przy uruchomieniu tylko jesli znaleziono czujniki
        - dallas: nie drukujemy czasu pobierania danych z czujnikow
        - NTP: komenda N w terminalu pobiera czas z NTP

    v0.1.0.102
        - poprawki poczatkowego odczytu z dallas

    v0.1.0.101
        - opóźnienie uśredniania odczytu

    v0.1.0.100
        - mapowanie: poprawienie wstępnego odczytu

    v0.1.0.99
        - dallas: odrzucamy zbyt duze zmiany pomiaru z czujnika
        - dodanie przeladowania pliku config.txt z www jak i terminala

uzi18, 2017-02-01:
v0.1.0.104
        - dodanie testu wygaszenia kotla - stosowne informacje pojawiaja sie w terminalu
        - MAX31855/6675: usuniecie z wykresu "piły" po restarcie sterownika
        - detektor: poprawienie monitorowania polokresow
        - drobne poprawki bledow kompilatora

uzi18, 2017-02-06:
v0.1.0.105
        - dodanie algorytmu wielomocowego (6szt.) do testów

    v0.1.0.106
        - przechodzimy z tła w podtrzymanie po przebiciu ponad zadana+przebicie

uzi18, 2017-02-06:
v0.1.0.107
    - dokończenie nowego dopalania - gotowe do testów
    - w trakcie pracy tła przekroczenie zadana+max_przebicie wyłącza tło całkowicie
    - tło i dopalanie nie mogą być włączone jednocześnie

uzi18, 2017-02-06:
v0.1.0.108
    - poprawka wczytywania parametrów nadmuchu wielomocowego i kontrola jego wartości

uzi18, 2017-02-07:
v0.1.0.109
        - dodanie statystyk do algorytmu wielu mocy

    v0.1.0.110
        - dodanie debugu do max31855k
        - poprawki w statystykach

    - dodanie opisu do nowosci - tlo/dopalanie/wielemocy

uzi18, 2017-02-07:
v0.1.0.111
    - poprawka: wyłączamy tło po zbyt dużym przebiciu
    - poprawka: przełączenie dmuchawy na moc tła jeśli przebiliśmy mocami
    - optymalizacja wyboru mocy w trybie wielomocowym

uzi18, 2017-06-27:
v0.1.0.112
        - dodanie do HTTP API /set do zmian parametrow online

    - esp-link firmware
    - dodanie skryptow uzywajacych esp-link

    v0.1.0.113
        - zmiana zachowania pieca po uruchomieniu - startuje w trybie recznym aby pracowal w auto dodac linijke PIEC_TRYB = AUTO
        - w trybie recznym: dodanie mozliwosci sterowania wyjsciami z www/terminala

    - Domoticz: dodanie polaczenia poprzez esp-link
    - Domoticz: drobna poprawka pobierania informacji z esp-link
    - Nettemp beta support
    - Nettemp,Domoticz: prosty test poprawnosci danych przed wyslaniem

    v0.1.0.114
        - dodanie mozliwosci wlaczenia pomiaru wejsc analogowych przez ANALOG=1
          domyslnie wylaczone, dodanie debugu do analogow.

    - esp-link aktualizacja firmware
    - schemat detektora 0 by Marek Gajos

    v0.1.0.115 - poprawienie zasypu zbiornika, dodano mozliwosc dosypywania.
        - aktualizacja strony www w zakresie zasypu

    v0.1.0.116 - dodanie priorytetu dla CWU - CWU_PRIORYTET = WLACZ

    v0.1.0.117 - uaktywnienie mozliwosci sterowania zaworem 4D z panela LCD
    update www

    v0.1.0.118 - zwiekszenie ilosci mocy RRW do 10szt.
        - dodanie mozliwosci wyboru czujnika oraz histerezy dla CWU2

    v0.1.0.119 - dodanie algorytmu zasypowego: ZASYP_MOC=30 ustawia moc nadmuchu dla trybu zasypowego
    - dodanie do listy algorytmow: ZASYPOWY i WYLACZONY

    v0.1.0.120 - poprawka dla histerezy CWU2 w trybie mieszania

    v0.1.0.121 - RTC_ZIMA=1 wymusza czas zimowy dla NTP

    - dodanie projektu czujnika pokojowego sterowanego z Domoticz, przy okazji regulujacego obnizona temperature w Lucjanie

    Domoticz i Nettemp - mozna wysylac do obu na raz z roznym interwalem

    v0.1.0.122 - dodanie trybu AUTOLATO z kilkoma parametrami i trybami pracy
        - pompy poprawka pracy w momencie gdy t_pieca spadnie ponizej minimalnej
        - drukujemy info o nieudanym pobraniu czasu z NTP
        - drukujemy info o znalezionym EEPROM na terminal

    # temperatura zewnetrzna auto przejscia CO w tryb lato
    AUTOLATO_TEMP = 0
    # histereza powrotu CO do trybu zima
    AUTOLATO_HISTEREZA = 0
    # temperatura dla twew auto przejsca CO w tryb lato
    AUTOLATO_TWEW = 0
    # dodatkowe tryb pracy autolato
    AUTOLATO_TRYB = 0
    # poza przejsciem w tryb lato wylaczamy calkowicie piec
    #AUTOLATO_TRYB = WYL_ALGO

    v0.1.0.123
        - w trybie lato dodanie mozliwosci ustawienia odrebnego czasu miedzy podtrzymaniami: RR_PODTRZYMANIE_CZAS_LATO
        - dodanie ograniczenia krotnosci podnoszenia zaru domyslnie wylaczone - PODAJNIK_T_WYSOKA_POWTORKI
        - domyslna histereza dla autolato to 1,5deg

uzi18, 2022-02-25:
```
- v0.1.0.130.35
- dodanie nowych harmonogramow:
  PROG_CO - harmonogram pompy CO
  PROG_CYRK - harmonogram pompy cyrkulacji
  PROG_OB - harmonogram obnizonej temperatury
- poprawki dla Uniwersalnych Termostatów - blad w odczycie parametrow
- Zawór 4D - ZAWOR4D-PRESET=50 - (50%) - pozycja od ktorej po uruchomieniu zaczynamy krecic
- Zawór 4D - ZAWOR4D-CZAS_ZMIANY_KIERUNKU=x - przy zmianie kierunku dodaje czas x
- Zawór 4D - ZAWOR4D-TRYB=POZYCJA - otwiera zawor na pozycje PRESET i nim nie porusza
- Ethernet - poprawki
- detektor - poprawki plus zwiekszenie tolerancji synchronizacji
- analogi - poprawki
- TWS - dodanie maszyny stanow
- LCD_WYGAS=x opcja do wlaczenia wygaszacza po okreslonym czasie
```

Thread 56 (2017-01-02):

zabezpieczenie ślimaka podajnika palnika retortowego przed niskim poziomem paliwa w palniku

bzykbzyk, 2017-01-02:
Pomiar temperatury "fajki" palnika (termopara). Przekroczenie nastawionej temp - zatrzymanie wentylatora i uruchomienie ciągłego podawania paliwa przez nastawiony czas w celu podniesienia żaru do rusztu.
W pracy automatycznej sterownik powinien docelowo obniżyć obroty wentylatora.
Zabezpieczenie ślimaka przed uszkodzeniem spowodowanym długotrwałym, zbyt niskim poziomem żaru w palniku retortowym - szybkie zużycie, utlenianie, ukręcenie końcówki lub zniszczenie zwojów.

uzi18, 2017-01-04:
Jak mamy zamocowac ten czujnik do fajki?
U mnie w palniku fajka jest zeliwna.

Stan17, 2017-01-04:
No właśnie, problem jest ten sam , jak zamontować ten czujnik.
A sam pomiar mógłby być bardzo przydatny.

uzi18, 2017-01-04:
U mnie moglbym sie zastanowic nad montazem gniazda na czujnik w stalej
retorcie. Aby wiedziec czy jest wystarczajaca ilosc zaru na retorcie.
Dalej pozostaje kwestia jak wyprowadzic przewod na zewnatrz... i pozostawic
palnik nadal szczelnym.

04.01.2017 10:05 PM "Stan17" <notifications@github.com> napisał(a):

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

bzykbzyk, 2017-01-05:
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

Ja przed samymi Świętami miałem awarię ślimaka właśnie przez długotrwałe (kilka dni) palenie bardzo nisko w fajce. Całkowicie wyparowały dwa zwoje, na samym końcu ślimaka. Paliłem przez kilka dni na ruszcie awaryjnym, tragedia, tony wody z komina. Żar nie cofnął się tak daleko, aby zadziałał czujnik temperatury podajnika (ustawiony na 50st). Czujnik zbyt niskiego żaru można zamocować opaską do fajki na zewnątrz. U mnie jest wyczystka, nie powinno być z tym problemu. Zrobiłbym zdjęcie jak zatrzymam piec, ale przez kilka dni mają być teraz wyjątkowe mrozy więc chyba nie bardzo będzie kiedy, smarnąłem coś takiego (zielone-opaska stalowa, czerwone-termopara):

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
Ten czujnik pełniłby funkcję jedynie tą co w temacie, oprócz tego powinien być czujnik żaru w koronie palnika, np tak:
http://www.ekspertbudowlany.pl/artykul/id3426,spalanie-pod-czujna-kontrolakotly-sas-z-czujnikiem-zaru

uzi18, 2017-01-06:
Ok a jak wyprowadzic przewod czujnika na zewnatrz aby wpiac go w sterownik?

05.01.2017 3:51 AM "bzykbzyk" <notifications@github.com> napisał(a):

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

bzykbzyk, 2017-01-06:
Przejście przez palnik w okolicach jak na rysunku (analogicznie przez drugą ściankę - blachę mocującą palnik do kotła)
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
wywiercić otwory i przeprowadzić kabel za pomocą przepustów/dławików/dławic kablowych metalowych
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
Usunąć z dławików wszystkie gumowe elementy, uszczelnić przez wypełnienie żaroodpornym silikonem/uszczelniaczem. Kabel do termopary oczywiście ognioodporny silikonowy albo mikowy . Podobnie można przeprowadzić przewody od czujnika żaru.

Stan17, 2017-01-23:
W sumie poważna przeróbka.
W lato tego roku chyba wyjmę cały palnik do przeglądu to się przyjrzę pod kontem takiej przeróbki.

uzi18, 2017-01-24:
Aktualnie jest dodana obsluga konwertera MAX6675K, za jakis czas dodam mozliwosc podlaczenia kilku takich czujnikow.
Więc możesz juz u siebie zamocować i przepuscic termoparę oraz organizować konwertery.

uzi18, 2017-08-31:
@bzykbzyk no i co gotowy na testy?

bzykbzyk, 2017-08-31:
@uzi18, na razie kocioł wygaszony. Powiercone dziury, szpeje prawie kompletne (uwaliłem 6675 - czekam na dostawę) jak będzie komplet zabieram się za uruchomienie.

uzi18, 2017-08-31:
No to fajnie,  sporo sie w sofcie pojawilo i masz co testowac.
Daj cynk to dopisze wsparcie dla kilku czujnikow.
Wtedy jak bedzie Ci dzialac to dodamy obsluge czujnika w zakresie fajki.

31.08.2017 11:06 PM "bzykbzyk" <notifications@github.com> napisał(a):

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

uzi18, 2017-09-01:
0.1.0.129.3 - dodanie mozliwosci podlaczenia wielu MAX6675K
    np. T3=MAX6675[48.1] zmapowanie z pinem CS nr 48 i filtrowaniem
    - poprawienie informacji o socketach

bzykbzyk, 2017-11-16:
Zamiast termopary na fajce zamontowałem czujnik żaru w palniku. Co prawda nie do końca w takim miejscu jak chciałem, ale może to wystarczy. Od góry w koronie (jak tu http://www.ekspertbudowlany.pl/artykul/id3426,spalanie-pod-czujna-kontrolakotly-sas-z-czujnikiem-zaru)- niewykonalne bo mam ruszt obrotowy.
Do konstrukcji wykorzystałem odcinek złomowej rurki stalowej fi10, fi5,5 wewnątrz. Jeden koniec zaspawałem, drugi nagwintowałem wewnątrz M6 i wkręciłem na silikonie 230st deczko zmodyfikowaną sondę termopary. Modyfikacja polegała na lekkim potraktowaniu rurki sondy kombinerkami tak, aby luźno przesuwała się wewnątrz śruby montażowej (rura fi10 ma około 8cm, sonda powinna być wepchnięta głęboko, aż do miejsca spawu). Wprowadziłem to od dołu palnika do kanału nawiewu w palniku, górny otwór, przez komorę wyczystki. Wywierciłem otwór w bocznej ścianie palnika i przykręciłem sondę wkrętem samowiercącym. Chciałem wprowadzić do bocznego  otworu nawiewu, ale czujnik musiałby być wygięty. W tej chwili nie palę, nie mam jak przetestować.
Załączam zdjęcia czujnika i jego montaż. Nie mam zdjęcia przejścia przewodu poprzez dławik poza palnik, jak bedzie trzeba to machnę.
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

uzi18, 2017-11-16:
Najwazniejsze aby oplot i termopara wytrzymywala wysoka temperature

Zerknij na czat:
https://gitter.im/sterownik/Lobby

16.11.2017 9:06 PM "bzykbzyk" <notifications@github.com> napisał(a):

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

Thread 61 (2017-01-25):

dodać wsparcie dla modulu wifi ESP8266

uzi18, 2017-01-25:
Na poczatek na bazie projektu esp-link https://github.com/jeelabs/esp-link/releases

Uwaga mała że do podłączenia do esp z płytka Mega nalezy uzyc konwertera
lub przynajmniej dzielnikow napiecia na rezystorach.
Jednak jeszcze nikt z nas nie testował tego rozwiązania.

czekamy na osoby, ktore przetestuja to rozwiazanie

uzi18, 2017-02-02:
esp-link-v3.0.14-g963ffbb uruchomiony na ESP-12E
polaczenia:
Mega - ESP
GND-G
3V3-3V
TX(pin1)-RX
RX(pin0)-TX
RESET-D6

Konfiguracja domyslna

Konsola i resetowanie dziala
Programowanie dziala po dodaniu resetu przed uruchomieniem avrdude

curl --data '' http://192.168.2.6/console/reset && avrdude -patmega2560 -cstk500v2 -Pnet:192.168.2.6:23 -b115200 -D -Uflash:w:Lucian.ino.mega.hex:i

oczywiscie 192.168.2.6 nalezy zmienic na IP wlasnego esp

uzi18, 2017-02-19:
zapraszam na wiki https://github.com/uzi18/sterownik/wiki/ESP8266

Closed 2017-02-19.

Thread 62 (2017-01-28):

Zegarek temperatura powrotu + Termostat ON

ebyna, 2017-01-28:
można dodać:
1. 4D ochrona Temperatura powrotu?
http://www.jpeg.cz/images/2017/01/28/1HUFm.png
pin 36 a GND zmiany statusu WWW - Termostat 1  -  ON ?
http://www.jpeg.cz/images/2017/01/28/PBf4.png

uzi18, 2017-10-30:
@ebyna nadal tych funkcji potrzebujesz?
udało Ci się uruchomić Lucjana?

ebyna, 2017-10-30:
Dziękuję za zainteresowanie.
Nadal się martwię o połączenie ESP z Lucjanem.
LCD - OK
DS18B20 - OK
ESP - OK konsola, NE IP Lucjan
---------- Původní e-mail ----------
Od: Bartłomiej Zimoń <notifications@github.com>
Komu: uzi18/sterownik <sterownik@noreply.github.com>
Datum: 30. 10. 2017 16:28:34
Předmět: Re: [uzi18/sterownik] Zegarek temperatura powrotu + Termostat ON (#
62)
"
@ebyna(https://github.com/ebyna) nadal tych funkcji potrzebujesz?
udało Ci się uruchomić Lucjana?

—
You are receiving this because you were mentioned.
Reply to this email directly, view it on GitHub
(https://github.com/uzi18/sterownik/issues/62#issuecomment-340480543), or
mute the thread
(https://github.com/notifications/unsubscribe-auth/AYOhRhp7wa9i67lsNf_x8FE4VJSyzTRIks5sxesYgaJpZM4Lwhw3)
.

"

ebyna, 2017-10-30:
Znowu:
Lan --- tak --- WWW lucjan
ESP8266 (Wifi) --- nie --- WWW lucjan?
---------- Původní e-mail ----------
Od: Bartłomiej Zimoń <notifications@github.com>
Komu: uzi18/sterownik <sterownik@noreply.github.com>
Datum: 30. 10. 2017 16:28:34
Předmět: Re: [uzi18/sterownik] Zegarek temperatura powrotu + Termostat ON (#
62)
"
@ebyna(https://github.com/ebyna) nadal tych funkcji potrzebujesz?
udało Ci się uruchomić Lucjana?

—
You are receiving this because you were mentioned.
Reply to this email directly, view it on GitHub
(https://github.com/uzi18/sterownik/issues/62#issuecomment-340480543), or
mute the thread
(https://github.com/notifications/unsubscribe-auth/AYOhRhp7wa9i67lsNf_x8FE4VJSyzTRIks5sxesYgaJpZM4Lwhw3)
.

"

uzi18, 2017-10-30:
Na esp nie działa strona www lucjan.
Esp jest do połączenia z portem szeregowym (komendy i debug) i zdalnej
aktualizacji lucjana.

30.10.2017 11:13 PM "ebyna" <notifications@github.com> napisał(a):

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

ebyna, 2017-10-30:
Dziękuję bardzo, zrozumiałem to źle i martwiłem się tym przez miesiąc i trzy
części ESPa.
Dziękuję za odpowiedź.
Czy kiedykolwiek myślisz o Wifi ESP - WWW Lucjan?
---------- Původní e-mail ----------
Od: Bartłomiej Zimoń <notifications@github.com>
Komu: uzi18/sterownik <sterownik@noreply.github.com>
Datum: 30. 10. 2017 23:16:24
Předmět: Re: [uzi18/sterownik] Zegarek temperatura powrotu + Termostat ON (#
62)
"Na esp nie działa strona www lucjan.
Esp jest do połączenia z portem szeregowym (komendy i debug) i zdalnej
aktualizacji lucjana.

30.10.2017 11:13 PM "ebyna" <notifications@github.com> napisał(a):

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
mute
> the thread
> <https://github.com/notifications/unsubscribe-auth/AAHOU654Ww2bNq8KIRlaI7
CongQpUqXAks5sxkntgaJpZM4Lwhw3>
> .
>

—
You are receiving this because you were mentioned.
Reply to this email directly, view it on GitHub
(https://github.com/uzi18/sterownik/issues/62#issuecomment-340601410), or
mute the thread
(https://github.com/notifications/unsubscribe-auth/AYOhRuXKy-Elpw6yxvRYO326BGwk-63wks5sxkq0gaJpZM4Lwhw3)
.

"

ebyna, 2017-10-30:
I nie rozumiem, jak mogę aktualizować przez ESP

aktualizacja esp-link: wiflash -v 192.168.2.6 user1.bin user2.bin gdzie
192.168.2.6 to adres ip esp-link

aktualizacja Lucjana do najnowszej wersji: aktualizujpiec_esp wczesniej w
pliku nalezy ustawic ip esp-link

jeśli będzie kiedykolwiek miał trochę czasu, tak może być za pośrednictwem
TeamViewer?

882 832 816

279htz

---------- Původní e-mail ----------
Od: Bartłomiej Zimoń <notifications@github.com>
Komu: uzi18/sterownik <sterownik@noreply.github.com>
Datum: 30. 10. 2017 23:16:24
Předmět: Re: [uzi18/sterownik] Zegarek temperatura powrotu + Termostat ON (#
62)
"Na esp nie działa strona www lucjan.
Esp jest do połączenia z portem szeregowym (komendy i debug) i zdalnej
aktualizacji lucjana.

30.10.2017 11:13 PM "ebyna" <notifications@github.com> napisał(a):

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
mute
> the thread
> <https://github.com/notifications/unsubscribe-auth/AAHOU654Ww2bNq8KIRlaI7
CongQpUqXAks5sxkntgaJpZM4Lwhw3>
> .
>

—
You are receiving this because you were mentioned.
Reply to this email directly, view it on GitHub
(https://github.com/uzi18/sterownik/issues/62#issuecomment-340601410), or
mute the thread
(https://github.com/notifications/unsubscribe-auth/AYOhRuXKy-Elpw6yxvRYO326BGwk-63wks5sxkq0gaJpZM4Lwhw3)
.

"

uzi18, 2017-10-30:
To da się zrobić,  w każdej chwili.
Ale nie mam na to czasu, nie znam znam dobrze www.

A co potrzebujesz na www?

30.10.2017 11:28 PM "ebyna" <notifications@github.com> napisał(a):

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

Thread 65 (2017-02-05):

dodać algorytm wielomocowy

uzi18, 2017-02-05:
dodano na testy w wersji v0.1.0.105

uzi18, 2017-02-06:
v0.1.0.108
    - poprawka wczytywania parametrów nadmuchu wielomocowego i kontrola jego wartości

mecenas8, 2017-02-18:
Przetestowałem trochę algorytm wielomocowy, mam jedną uwagę.

Wg mnie przydałoby się coś w formie PID, ponieważ teraz, podam parametry jakie są ustawione w tej chwili (zadana temperatura 63 stopnie):

# moc 0 domyslna
RRW_PODANIE0=6
RRW_POSTOJ0= 120
RRW_NADMUCH0=30
# moc 1
RRW_PODANIE1=6
RRW_POSTOJ1= 80
RRW_NADMUCH1=38
RRW_HISTEREZA1=12
# moc 2
RRW_PODANIE2=6
RRW_POSTOJ2= 60
RRW_NADMUCH2=46
RRW_HISTEREZA2=24
# moc 3
RRW_PODANIE3=6
RRW_POSTOJ3= 45
RRW_NADMUCH3=55
RRW_HISTEREZA3=36
# moc 4
RRW_PODANIE4=6
RRW_POSTOJ4= 33
RRW_NADMUCH4=63
RRW_HISTEREZA4=48

Załóżmy teraz, że mamy stosunkowo duży odbiór mocy i algorytm pracuje na mocy nr 3, która mniej więcej wystarcza do podtrzymania temperatury na poziomie 63 stopnie minus histereza ponad 3,6 czyli ok 59 stopni.
Nigdy więc nie osiągniemy w tym stanie temperatury zadanej 63 stopnie, ponieważ algorytm będzie pracował na mocy nr 3, a stosując PID po pewnym czasie uchyb scałkowałby się (część "I") i przeskoczyłoby na moc nr 4 w celu podbicia temperatury w pobliże zadanej.

Podobnie mając mały odbiór ciepła algorytm pracuje powiedzmy na mocy nr 3, temperatura zaczyna narastać bardzo szybko, ale algorytm przeskakuje kolejno w moc nr 2, nr 1, nr 0 (po przekroczeniu kolejnych pułapów histerezy), co powoduje przebicie temperatury i wejście w podtrzymanie. Gdyby zastosować PID to część "D" "zauważy" że temperatura szybko narasta i przeskoczy z mocy nr 3 od razu w moc nr 1 bądź nr 0 powodując zmniejszenie narastania temperatury.

uzi18, 2017-02-18:
Takie sa zalozenia algorytmu z histereza i tu sie juz pewnie niewiele
zmieni.
To jest baza.
Nastepny etap to rozne algorytmy wyboru mocy z tych zdefiniowanych, moze
nawet jakis PID albo predzej PD.

18.02.2017 5:15 PM "mecenas8" <notifications@github.com> napisał(a):

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

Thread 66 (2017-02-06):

Termopara MAX31855K - błędne działanie

mecenas8, 2017-02-06:
Problem z działaniem termopary na MAX31855K.

Termopara podaje zaniżone odczyty, zmierzone temperatury wahają się od ok. 5-10 stopni C w stanie nadzoru (czasami spada poniżej zero - wtedy pojawiają się skokowe odczyty od bardzo dużych wartości dodatnich do bardzo dużych ujemnych). Maksymalna zmierzona temperatura podczas pracy kotła to ok 80-90 stopni, gdzie mierząc w tym czasie inną termoparą podłączoną do multimetru rzeczywiste temperatury wynoszą powyżej 150 stopni.

Załączam plik z odczytami z terminala, może w czymś pomoże.

[Sterownik- terminal.txt](https://github.com/uzi18/sterownik/files/756132/Sterownik-.terminal.txt)

Dodatkowo zauważyłem w odczytach z terminala komunikaty: TRIAC: zaklucenia z detektora...
Dmuchawa nie jest "czysto" sterowana, przy mniejszych mocach słychać nierównomierną pracę.
Sprawdziłem przebieg na pinie 2 Arduino, wygląda jak poniżej, wydaje się być w porządku. Jedyne co zauważyłem to to, że lekko pływa szerokość impulsu, ale to w granicach 1-3%.

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

uzi18, 2017-02-07:
zauwaz ze masz sporo takich komunikatow: TRIAC: zaklucenia z detektora
poniewaz sygnal z detektora pływa (ok.1ms) to i sterowanie triakiem tez pływa

Przelacz sie z triakiem pod pin 32, na A2 bywały zakłucenia - potrafily przechodzic pelne polokresy.
Sprawdz czemu plywa sygnal z detektora.

Co do termopary - dodaj linijke:
T3 = MAX31855[1]
pod T3 pojdzie bezposredni odczyt z chip-a i wrzuc tutaj wykres

mecenas8, 2017-02-07:
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

T3 - odczyt bezpośredni z termopary
tSpaliny - odczyt uśredniony (z dołożonym offsetem +25 st.C

MAX31855K mam z sampli od maxim-ic, powinien być raczej pewny. W razie czego mam zapasowe, mogę przelutować.

Konwerter sam robiłem, są to dzielniki rezystorowe na szynach SCK i CS, SDO póki co idzie bezpośrednio na Arduino, które powinno poprawnie widzieć poziom 3v3 jako High.

Z detektorem to sprawdzę później to przełączenie na 32.

uzi18, 2017-02-07:
Zasilasz maxa z 3v3 jak rozumiem.
Czyli zostaje jeszcze sprawdzic go na jakiejs bibliotece pod arduino ide,
 dasz rade?

07.02.2017 9:46 AM "mecenas8" <notifications@github.com> napisał(a):

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

mecenas8, 2017-02-07:
Dałbym radę, zajmuję się programowaniem uC prawie na co dzień, z tym że głównie Microchipa. Kwestia znalezienia trochę na to trochę czasu.

Mogę też wpiąć się analizatorem na SPI, wtedy byłoby widać co leci z MAX-a do Arduino.

uzi18, 2017-02-07:
dobra inaczej zaktualizuj do wersji 110:

    v0.1.0.110
        - dodanie debugu do max31855k
        - poprawki w statystykach

    - dodanie opisu do nowosci - tlo/dopalanie/wielemocy

jak wcisniesz V, w terminalu co 2s. pojawia sie linijki
MAX .... z danymi odczytanymi z SPI, danymi przesunietymi w prawo o 18bit (tu ujemnych nie zobaczysz poprawnie) oraz temperatura po konwersji
Mozesz sprobowac sprawdzic analizatorem czy dane zgadzaja sie z wyslanymi na magistrale.
Wklej mi tez log z terminala.

mecenas8, 2017-02-07:
[Sterownik- terminal2.txt](https://github.com/uzi18/sterownik/files/759165/Sterownik-.terminal2.txt)

Na razie nic więcej nie robiłem tylko zaktualizowałem soft i odczytałem z terminala.

mecenas8, 2017-02-07:
Nie rozumiem tego zapisu z terminala.

Przykładowo:
MAX data: 0x1a20, t:184, t:11

Dane z SPI: 0x1A20 - to jest 16 bitów, natomiast MAX wysyła 32 bity.

uzi18, 2017-02-07:
Mniejsza o to ze drukuje tylko 16bit - to poprawie - ale pokazuje ... blad SCV - zwarcie termopary do VCC
mozesz to sprawdzic?

mecenas8, 2017-02-15:
Nie było zwarcia termopary do VCC ani GND.

Ze względu na brak czasu na dalsze dochodzenia z MAX31855 zakończyłem akcję z termoparą w ten sposób, że przelutowałem scalak na MAX6675 i teraz termopara działa bez zarzutu, podaje poprawne temperatury.

uzi18, 2017-02-19:
Z naszych doswiadczen wynika ze 6675 lepiej toleruje rozne termopary i generalnie lepiej sobie radzi z pomiarem, mimo ze producent sugeruje uzycie 31855

uzi18, 2017-03-20:
Generalnie chcialem podsumowac, jest to raczej problem z samym MAX31855 lub termopara - bo uklad nie wspolpracuje ze wszystkimi rodzajami termopar K.

uzi18, 2017-08-31:
Czyli lepiej jednak bawic sie z MAX6675K, zamykam

Closed 2017-08-31.

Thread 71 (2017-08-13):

Sterowanie dmuchawą AC - sygnał odwrócony

mipurel, 2017-08-13:
Wprowadzenie sterowania dmuchawą AC dla modułów z triakami wyzwalanymi niskim poziomem (SSR low level trigger). Sygnały na 32 i A13 są identyczne, można np. jeden z nich odwrócić lub wykorzystać dodatkowy pin albo zrobić to programowo w pliku config.

uzi18, 2017-08-13:
Prawie wszystkie dostepne ssr-y maja detekcje przejscia przez zero co
 powoduje,  ze nie da sie fazowo sterowac moca dmuchawy.
Nie spotkalem sie jak dotad z modulem,  ktory nadawałby się do tej funkcji.

Sam sie przekonaj,  dodaj inwerter sygnalu i wpusc na modul ssr, nastepnie
zmieniaj nadmuch w trybie recznym.

Sprawdz dokumentacje samego przekaznika,  jaki masz na nim nadruk?

mipurel, 2017-08-14:
Ok, ale ja mam przelutowanego omrona G3MB-202PL w jednym kanale z przelaczaniem w dowolnej fazie. Dodatkowy inwerter nieco komplikuje układ a miało być jak najprościej, a najlatwiej jest zmodyfikowac program. Może moje uwagi  w temacie są błache, ale spodobał mi się twój projekt i chciałbym włączyć aktywnie w rozwój. Troszkę (może trochę więcej) znam się na elektronice chociaż miałem dłuższą przerwę w tej dziedzinie i ogólnie interesuję się zagadnieniami automatyki inteligentnych domów. Jak chcesz mogę ci podesłać do testów.

uzi18, 2017-08-14:
To zmienia postac rzeczy i w sumie od tego mogles zaczac :)
Pamietaj ze staramy się  używać  modułów  ogolnie dostepnych, stad taka a
nie inna odpowiedz.

Musisz miec na uwadze aby wyjscie pinu podciagnac do +5v, a dmuchawe
dodatkowo odcinac przekaznikiem.
Musi byc pewnosc ze dmuchawa nie uruchamia się gdy procesor jest w trybie
reset/bootloadera i programowania.
Tak samo w razie przegrzania kotla/podajnika termik powinien rozlaczyc
przekaznik.

Czemu nie zalatwiles sobie modulu high trigger?

14.08.2017 7:36 AM "mipurel" <notifications@github.com> napisał(a):

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

uzi18, 2017-08-14:
v0.1.0.128 - dodanie sygnalu odwroconego dla dmuchawy AC na pin 33

prosze o info z testow, w pdf od przekaznika jest info ze max czas zalaczania to
1ms ... ciekawe ile jest typowo, moze sie okazac ze rozwiazanie sie nie nadaje.

mipurel, 2017-08-14:
Z modułem wyszlo w trakcie, trochę też nie zauważyłem, że przerzuciłeś z A13 na 32 bez odwrócenia sygnału tak jak pozostałe. Poza tym te low level 4ch były na Ali cost effective. Sprawdzę ale w środku tego SSR jest tylko optotriak i triak ze snubberem, robiłem symulacje dla takiego modułu sterowanego cyfrowo w proteusie. Przetestujemy zobaczymy. [https://www.google.pl/imgres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](url)

uzi18, 2017-08-14:
aktualne podlaczenia zawsze sa w pliku polaczenia.txt

Skopiowalem wyjscie na 32 z tego powodu ze wyjscie na porcie z analogowymi
wejsciami przepuszcza czasem caly polokres.
Na pinie 32 tego efektu nie bylo.

14.08.2017 12:39 PM "mipurel" <notifications@github.com> napisał(a):

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

mipurel, 2017-08-14:
Wejścia modułu SSR low level trigger są podciągnięte do plusa  co powoduje, że bez wymuszonego stanu niskiego są wyłączone. Na chwile obecną tylko sprawdziłem oscyloskopem i widzę, że zmieniłeś wyzwalanie na impulsowe dzięki czemu wyzwolenie triaka powinno być pewniejsze. Wcześniej po jasności diody można było ocenić moc dmuchawy ale to szczegół :). Mam ten sterownik w stanie stołowo-testowym więc trochę muszę pokombinować z obciążeniem. Jak tylko będę po testach dam znać.

uzi18, 2017-08-14:
Masz 2 typy sterowania DM_TYP=0 lub 1
Domyslnie typ jest stary czyli 0.
Na nowym typie sterowanie bramka jest impulsem.
Na starym wylaczalem w zerze.

Wyglada ze oba testowales na oscyloskopie?

14.08.2017 6:04 PM "mipurel" <notifications@github.com> napisał(a):

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

mipurel, 2017-08-15:
Testowałem v.0.1.0.126 i 128. Wychodzi na to, że w 126 zmiana parametru DM_TYP=1 nic nie daje przebieg jest jak dla starego sterowania na wyjściu 32. W 128 nie wiem czy efekt był zamierzony jest impuls ok. 300us, i seria podwójnych szpilek do końca półokresu zaczynają się z rożnym opóźnieniem w stosunku do głównego impulsu odstęp między nimi ok 500us. Zasadniczo stosuje się dodatkowe impulsy i pierwotnie sądziłem, że taki był zamiar ale po twojej odpowiedzi nie jestem już pewien. Jeżeli triak jest włączony i tak nie będą generowały dodatkowych zakłóceń.

uzi18, 2017-08-15:
Wiem ze dodatkowe impulsy sie stosuje ale to co piszesz to nie jest
działanie zamierzone.
Mozesz wrzucic tu oscylogramy?

15.08.2017 12:40 PM "mipurel" <notifications@github.com> napisał(a):

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

uzi18, 2017-08-15:
Wklej mi co Ci sie pojawia w terminalu po wyslaniu cyfry 3

mipurel, 2017-08-15:
TRIAC: T-9948 Z-0 T-Z-604 F-0 50% DET-221/200
TRIAC: 0-93 1-6 S-99 ok-200
TRIAC: T-9948 Z-0 T-Z-604 F-0 50% DET-221/200
TRIAC: 0-93 1-6 S-99 ok-200
TRIAC: T-10048 Z-0 T-Z-504 F-0 50% DET-221/200
TRIAC: 0-93 1-7 S-98 ok-200
TRIAC: T-9948 Z-0 T-Z-604 F-0 50% DET-221/200
TRIAC: 0-92 1-7 S-98 ok-200
TRIAC: T-9868 Z-0 T-Z-604 F-0 50% DET-221/200
TRIAC: 0-92 1-7 S-98 ok-200
TRIAC: T-9852 Z-0 T-Z-704 F-0 50% DET-222/200
TRIAC: 0-92 1-7 S-98 ok-200
TRIAC: T-9952 Z-0 T-Z-600 F-0 50% DET-221/200
TRIAC: 0-93 1-6 S-99 ok-200
TRIAC: T-9948 Z-0 T-Z-604 F-0 50% DET-221/200
TRIAC: 0-93 1-6 S-99 ok-200
TRIAC: T-9952 Z-0 T-Z-600 F-0 50% DET-221/200
TRIAC: 0-93 1-6 S-99 ok-200
TRIAC: T-9848 Z-0 T-Z-704 F-0 50% DET-221/200
TRIAC: 0-92 1-7 S-98 ok-200
TRIAC: T-9948 Z-0 T-Z-604 F-0 50% DET-221/200
TRIAC: 0-93 1-6 S-99 ok-200
TRIAC: T-9948 Z-0 T-Z-704 F-0 50% DET-221/200
TRIAC: 0-92 1-7 S-99 ok-200
TRIAC: T-9948 Z-0 T-Z-604 F-0 50% DET-221/200
TRIAC: 0-93 1-6 S-99 ok-200
TRIAC: T-9948 Z-0 T-Z-604 F-0 50% DET-221/200
TRIAC: 0-93 1-6 S-99 ok-200
TRIAC: T-9952 Z-0 T-Z-704 F-0 50% DET-221/200
TRIAC: 0-92 1-7 S-99 ok-200
TRIAC: T-9952 Z-0 T-Z-700 F-0 50% DET-221/200
TRIAC: 0-92 1-7 S-99 ok-200
TRIAC: T-10052 Z-0 T-Z-500 F-0 50% DET-221/200
TRIAC: 0-93 1-7 S-98 ok-200
TRIAC: T-9952 Z-0 T-Z-600 F-0 50% DET-221/200
TRIAC: 0-94 1-5 S-100 ok-200
TRIAC: T-9948 Z-0 T-Z-604 F-0 50% DET-221/200
TRIAC: 0-93 1-6 S-99 ok-200
TRIAC: T-9948 Z-0 T-Z-604 F-0 50% DET-221/200
TRIAC: 0-93 1-7 S-99 ok-200
TRIAC: T-9948 Z-0 T-Z-604 F-0 50% DET-221/200
TRIAC: 0-93 1-7 S-99 ok-200
TRIAC: T-9948 Z-0 T-Z-604 F-0 50% DET-221/200
TRIAC: 0-93 1-6 S-99 ok-200
TRIAC: T-9948 Z-0 T-Z-604 F-0 50% DET-221/200
TRIAC: 0-93 1-6 S-99 ok-200
TRIAC: T-9948 Z-0 T-Z-704 F-0 50% DET-222/200
TRIAC: 0-92 1-7 S-99 ok-200
TRIAC: T-9948 Z-0 T-Z-604 F-0 50% DET-221/200
TRIAC: 0-93 1-6 S-99 ok-200

uzi18, 2017-08-15:
Pieknie detektor dziala :) napisalem Ci email na google

15.08.2017 7:14 PM "mipurel" <notifications@github.com> napisał(a):

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

uzi18, 2017-08-15:
Jaki detektor zmontowales, masz bardzo stabiliny sygnal :)

mipurel, 2017-08-25:
Detektor jest podobny do tego przesłanego przez Marka Gajosa, 22k/2W x3 + PC817 + LED + Mostek + zener do zabezpieczenia.

Closed 2017-08-25.

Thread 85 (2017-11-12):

pomiar paliwa w zasobniku.

sargus123, 2017-11-12:
zauważyłem na jednej stronie odczyt ilości paliwa za pomocą sensora odległości.

może coś takiego zrobić. wtedy będzie zawsze pewne jaki jest faktyczny poziom paliwa w zasobniku.

http://projektpimalina.blogspot.com/2016/05/czujnik-poziomu-wegla-na-nadajniku.html

w pliku config można wstawić  pozycję gdzie się podaje wysokość zasobnika od czujnika aby poprawnie odczytywał poziom w każdym zasobniku.

uzi18, 2017-11-13:
Byl juz taki pomysl na poczatku. Nikt nie sprawdzil jednak dotad czy zapylenie/zadymienie i ogolne warunki w zasobniku nie powoduja niszczenia tego czujnika.

sargus123, 2017-11-13:
sprawdzę czujnik ultradźwiękowy w obudowie szczelnej. samochodowy one są po 8 zł.  sprawdzę ich zakresy działania. one się nie kurzą itp.

uzi18, 2017-11-13:
Nie wiem jak z podlaczeniem tego samochodowego do mikrokontrolera

13.11.2017 2:01 PM "sargus123" <notifications@github.com> napisał(a):

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

sargus123, 2017-11-15:
To co miałem w planie nie wyszło . za niski sygnał daje nadajnik i głupoty wychodzą w odczycie.
ale znalazłem hermetyczny już gotowy moduł.  ok. 55zł. - JSN-SR04T
Czujnik jest na kablu. pomiar od 20 cm. w dal. ale patrząc na głębokość zasobnika to jest do przyjęcia.

uzi18, 2017-11-15:
To mi sie podoba,  konkretny modul i sonda ktora na pierwszy rzut oka moze wytrzymac warunki.
Jest jeszcze tylko jedna rzecz w zasobniku panuje nadcisnienie,  ciekawe czy to nie uszkodzi czujnika albo nie bedzie wplywac na pomiary.
Tak czy inaczej wymagane sa testy =)

uzi18, 2017-11-15:
@bzykbzyk, @ravikjab,  @Stan17,  @mark3k3 przyda się?

sargus123, 2017-11-15:
czujnik ten nie jest wrażliwy na ciśnienie tym bardziej kiedy będzie zamontowany wewnątrz.  te czujniki są montowane w uniwersalnych czujnikach samochodowych.

Stan17, 2017-11-16:
To ja kiedyś poruszałem ten temat i dokładnie na podstawie tego samego znaleziska na projektpimalinie.
Ale mieliśmy wtedy inne problemy na głowie, i projekt został odłożony na przyszłość.
Myślę że warto do niego wrócić, bo nie wiem jak Wy ale ja nie raz zapomniałem zresetować licznika :)

uzi18, 2017-11-16:
W sumie moze ten pomiar pozwolilby na automatyczne "uzupelnienie" paliwa

16.11.2017 1:02 PM "Stan17" <notifications@github.com> napisał(a):

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

sargus123, 2017-11-16:
Jeszcze jedno co może układ spełniać.
Po założeniu w klapie to można w ustawieniach dołożyć kod że jeśli odległość jest powyżej głębokości zbiornika to ma wyłączyć wentylator i podajnik a włączyć po  np. 30 sekundach kiedy odczyt będzie prawidłowy. (ponieważ w czasie ładowania do zbiornika będzie "widział nas" jako odległość bliższa niż głębokość zbiornika.) takie rozwiązanie zautomatyzowało proces ładowania  / czyszczenia pieca.

uzi18, 2017-11-16:
@Stan17  czyli co zamawiamy u Ali-ego?

uzi18, 2017-11-16:
@bzykbzyk zglaszal jeszcze cos takiego kiedys:
#45

uzi18, 2017-11-16:
klawisz wywołujący zwloke w dalszej pracy na czas wyczyszczenia pieca #80

uzi18, 2017-11-16:
Duplicate of #45

bzykbzyk, 2017-11-16:
JSN-SR04T na Ali za 8 baksów. Zamawiam. Jak nie zadziała w sterowniku zabuduję w samochodzie...

uzi18, 2017-11-16:
Tez zamowilem na ali.

Tak swoja droga tutaj mamy nasz online chat: https://gitter.im/sterownik/Lobby
@Stan17 @mark3k3 @ravikjab @bzykbzyk @micro-jr @ebyna @Kosiarz78

Stan17, 2017-11-17:
No to zamawiamy , ten JSN-SR04T ?

uzi18, 2017-11-17:
Tak one są zgodne z tymi użytymi w linku z 1 postu

uzi18, 2017-12-29:
Doszly czujniki do mnie, najpierw dodam pomiar kazdy sobie przetestuje czy dziala mapujac czujnik na wykres

uzi18, 2018-01-03:
OK Panowie ciekawostka modul JSN-SR04T-2.0 sam potrafi mierzyc odleglos i wysylac ja po RS232/TTL

uzi18, 2018-01-03:
@sargus123 @Stan17 @bzykbzyk teraz pytanie czy zaprogramowac stary tryb z pomiarem echa czy nowy - odczyt pomiaru z czujnika (wymaga przylutowania rezystora) czy oba ?

uzi18, 2018-01-03:
@sargus123 @Stan17 @bzykbzyk teraz pytanie czy zaprogramowac stary tryb z pomiarem echa czy nowy - odczyt pomiaru z czujnika (wymaga przylutowania rezystora) czy oba ?

sargus123, 2018-01-04:
tak myślę że dobrze by było aby układ sam podawał dane a z configu będzie łatwiej podać poziomy:
- pełny,
- pusty ,
-klapa otwarta.
po co miałby nasz lucjan jeszcze obliczać. (może to zmniejszy objętość kodu.) :)
ale to nie ja będę pisał kod :) ważne by przyszły nowy użytkownik nie miał problemu ze złożeniem.
problemy gdzieniegdzie widziałem z wersją 2.0
Przykładowy kod działa tutaj zarówno dla wersji V1.0, jak i wersji 2.0
https://www.dfrobot.com/wiki/index.php/Weather-proof_Ultrasonic_Sensor_SKU_:_SEN0207

uzi18, 2018-01-04:
@bzykbzyk Ty tez masz ten w wersji 2.0 ?

Stan17, 2018-01-04:
Ja mam wersję 2.0
Ale to nam zablokuje RSa, ja mam tam podłączonego ecoala i chciałbym tak zostawić puki co.
Tak więc ja głosuję implementacją obu metod.

uzi18, 2018-01-04:
mamy jeszcze 1 wolny RS

uzi18, 2018-01-04:
uzywasz esp-link?

bzykbzyk, 2018-01-04:
@uzi18 jeszcze nie mam czujnika, zamówiłem https://www.aliexpress.com/item/K02-JSN-SR04T-integrated-ultrasonic-ranging-module-reversing-radar-40KHZ-waterproof-ultrasonic-sensor-module/32732427963.html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, na foci płytki jest 2.0. Kitajce coś się ociągają z moimi dostawami, na razie mam komunikat, że przygotowane do wysyłki... Chyba tam pojadę i im nawrzucam....

sargus123, 2018-01-04:
ja nie używam. esp link na lucjanie.

Stan17, 2018-01-05:
Ja też jeszcze nie.

uzi18, 2018-01-06:
@Stan17 czyli mozemy uzyc TXD2/RXD2 ??

uzi18, 2018-01-06:
```
SR04T: 127 FF 2 16 17,STX,CRC,216 534mm.
SR04T: 123 FF 2 16 17,STX,CRC,216 534mm.
SR04T: 119 FF 2 16 17,STX,CRC,216 534mm.
SR04T: 115 FF 2 16 17,STX,CRC,216 534mm.
SR04T: 111 FF 2 27 28,STX,CRC,227 551mm.
SR04T: 107 FF 2 16 17,STX,CRC,216 534mm.
SR04T: 103 FF 2 16 17,STX,CRC,216 534mm.
SR04T: 99 FF 2 16 17,STX,CRC,216 534mm.
SR04T: 95 FF 2 16 17,STX,CRC,216 534mm.
SR04T: 95 FF 2 16 17,STX,CRC,216 534mm.
SR04T: 91 FF 2 16 17,STX,CRC,216 534mm.
SR04T: 87 FF 2 16 17,STX,CRC,216 534mm.
SR04T: 83 FF 2 16 17,STX,CRC,216 534mm.
SR04T: 79 FF 2 16 17,STX,CRC,216 534mm.
SR04T: 75 FF 2 16 17,STX,CRC,216 534mm.
SR04T: 71 FF 2 16 17,STX,CRC,216 534mm.
SR04T: 67 FF 2 16 17,STX,CRC,216 534mm.
SR04T: 63 FF 2 16 17,STX,CRC,216 534mm.
SR04T: 63 FF 2 16 17,STX,CRC,216 534mm.
SR04T: 59 FF 2 16 17,STX,CRC,216 534mm.
SR04T: 55 FF 2 16 17,STX,CRC,216 534mm.
SR04T: 51 FF 2 16 17,STX,CRC,216 534mm.
SR04T: 47 FF 2 16 17,STX,CRC,216 534mm.
SR04T: 43 FF 2 16 17,STX,CRC,216 534mm.
SR04T: 39 FF 2 16 17,STX,CRC,216 534mm.
SR04T: 35 FF 2 16 17,STX,CRC,216 534mm.
SR04T: 31 FF 2 16 17,STX,CRC,216 534mm.
SR04T: 27 FF 2 16 17,STX,CRC,216 534mm.
SR04T: 23 FF 2 16 17,STX,CRC,216 534mm.
SR04T: 19 FF 2 16 17,STX,CRC,216 534mm.
SR04T: 15 FF 2 16 17,STX,CRC,216 534mm.
SR04T: 11 FF 2 16 FF,STX,CRC zly
SR04T: 8  S, S, S,FF 2 16 17,STX,CRC,216 534mm.
SR04T: 8 FF 2 16 17,STX,CRC,216 534mm.
SR04T: 8 FF 2 16 17,STX,CRC,216 534mm.
SR04T: 8 FF 2 16 17,STX,CRC,216 534mm.

SR04T: 127 FF 2 16 17,STX,CRC,216 534mm.
SR04T: 123 FF 2 16 17,STX,CRC,216 534mm.
SR04T: 119 FF 2 16 17,STX,CRC,216 534mm.
SR04T: 115 FF 2 16 17,STX,CRC,216 534mm.
SR04T: 111 FF 2 16 17,STX,CRC,216 534mm.
SR04T: 111 FF 2 16 17,STX,CRC,216 534mm.
SR04T: 107 FF 2 27 28,STX,CRC,227 551mm.
SR04T: 103 FF 2 27 28,STX,CRC,227 551mm.
SR04T: 99 FF 2 16 17,STX,CRC,216 534mm.
SR04T: 95 FF 2 16 17,STX,CRC,216 534mm.
SR04T: 91 FF 2 16 17,STX,CRC,216 534mm.
SR04T: 87 FF 2 16 17,STX,CRC,216 534mm.
SR04T: 83 FF 2 16 17,STX,CRC,216 534mm.
SR04T: 79 FF 2 16 17,STX,CRC,216 534mm.
SR04T: 75 FF 2 16 17,STX,CRC,216 534mm.
SR04T: 75 FF 2 16 17,STX,CRC,216 534mm.
SR04T: 71 FF 2 16 17,STX,CRC,216 534mm.
SR04T: 67 FF 2 16 17,STX,CRC,216 534mm.
SR04T: 63 FF 2 16 17,STX,CRC,216 534mm.
SR04T: 59 FF 2 16 17,STX,CRC,216 534mm.
SR04T: 55 FF 2 16 17,STX,CRC,216 534mm.
SR04T: 51 FF 2 16 17,STX,CRC,216 534mm.
SR04T: 47 FF 2 16 17,STX,CRC,216 534mm.
SR04T: 43 FF 2 16 17,STX,CRC,216 534mm.
SR04T: 43 FF 2 16 17,STX,CRC,216 534mm.
SR04T: 39 FF 2 16 17,STX,CRC,216 534mm.
SR04T: 35 FF 2 16 17,STX,CRC,216 534mm.
SR04T: 31 FF 2 16 17,STX,CRC,216 534mm.

Cos juz dziala :)
```

uzi18, 2018-01-06:
v0.1.0.130.11
        - dodanie obslugi pomiaru z czujnika SR04T-2.0
          podlaczamy TX czujnika pod RX2 na plytce Mega
          w pole R27 modulu wstawiamy rezystor 47k
        - dodanie mozliwosci zmapowania poziomu zasobnika na wykresie
          np. T4=SR04T[]
        - LCD: dodanie pomiaru odleglosci na ekranie poziomu zasobnika

uzi18, 2018-01-06:
testujcie sobie i opiszcie wnioski tutaj :)

sargus123, 2018-01-08:
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
u mnie bez zarzutu działa.

sargus123, 2018-01-08:
z tego co zauważyłem tonie pokaże poziomu poniżej 18.5 centymetra.gdy jest więcej załadowane. ale tak naprawdę to w niczym nie przeszkadza.  2/3 zbiornika mi opróżniło i wyświetliło poprawnie.

sargus123, 2018-01-09:
u mnie 60 to pusty a 65 ślimak goły.

uzi18, 2018-01-09:
Super czekamy teraz na informacje od  reszty testerów :)

09.01.2018 8:24 AM "sargus123" <notifications@github.com> napisał(a):

u mnie 60 to pusty a 65 ślimak goły.

—
You are receiving this because you were mentioned.

Reply to this email directly, view it on GitHub
<https://github.com/uzi18/sterownik/issues/85#issuecomment-356201125>, or mute
the thread
<https://github.com/notifications/unsubscribe-auth/AAHOU2h3mmBSh8fndRdXa3iug3N0U1l-ks5tIxQegaJpZM4QbDaa>
.

sargus123, 2018-01-10:
montaż czujnika
puszka uniwersalna.
W pokrywie wywiercone 3 otwory 2 na śrubki 3mm i 1 ma kabel 8mm . nie uszczelniałem ponieważ od spodu puszka równo przylega do blachy i czujnik w obudowie.
jeśli będzie trzeba to się uszczelni od góry pod pokrywką.

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

Warto zwrócić uwagę na to  że czujnik nie patrzy w pełni na wprost. Sonda jest lekko pod skosem.
Trzeba tak umieścić aby poprawnie patrzył w dno zbiornika .

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
 zostało jeszcze poprowadzenie kabla w osłonie.

uzi18, 2018-01-10:
Zabezpiecz przewod aby sie nie łamał prxy otwieraniu klapy

10.01.2018 10:48 AM "sargus123" <notifications@github.com> napisał(a):

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

Stan17, 2018-01-10:
Czym z wierzchu przykryłeś ten kabel ?

sargus123, 2018-01-10:
Uniwersalna puszka ze sklepu elektronicznego ma pokrywkę. Nią przykryłem
usuwając tylko w miejscu kabla krawędź aby kabla nie przygniotlo.

10.01.2018 12:53 PM "Stan17" <notifications@github.com> napisał(a):

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

sargus123, 2018-01-10:
Potem kabel jeszcze zabezpieczenie w sporo aby luzem nie latał tam gdzie
nie powinien.

10.01.2018 1:00 PM "Artur Kuchnowski" <sargusix@gmail.com> napisał(a):

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

sargus123, 2018-01-17:
Drobna uwaga warto pod szpilki układu dołożyć kondensator układ jest wrażliwy na zasilanie.
Miałem z tym układem problem że układ nie chciał wskazywać większej  odległości niż 33 centymetry.
Po podłączeniu pod zasilanie problemy ustąpiły.

Stan17, 2018-01-19:
Masz na myśli jakiś elektrolit na +- zasilania ?

uzi18, 2018-01-19:
Tak

19.01.2018 1:11 PM "Stan17" <notifications@github.com> napisał(a):

Masz na myśli jakiś elektrolit na +- zasilania ?

—
You are receiving this because you were mentioned.

Reply to this email directly, view it on GitHub
<https://github.com/uzi18/sterownik/issues/85#issuecomment-358948870>, or mute
the thread
<https://github.com/notifications/unsubscribe-auth/AAHOUyiN51O0Pjoamq508Qt10l749FN0ks5tMIZtgaJpZM4QbDaa>
.

uzi18, 2018-01-19:
Tak bezposrednio na module,  miedzy gnd i vcc.
@sargus123 a jaki kondzior dales 1000uF?

sargus123, 2018-01-19:
ja wrzuciłem 829 uf pod + i -

sargus123, 2018-01-19:
820

uzi18, 2018-02-02:
W aktualnej podwersji... 21  dodalem kontrole stanu minimalnego

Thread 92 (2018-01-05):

Powiadomienie dźwiękowe o wystąpieniu Alarmu na stronie www

Mirek3012, 2018-01-05:
nie trzeba by było z kotłowni przeciągać przewodu do buzzera

sargus123, 2018-01-05:
a ja jeszcze bym dopisał aby wysyłał powiadomienie.
tak naprawdę byłoby dobrze gdyby lucjan wysyłał dane stan wysoki i niski jak przełączniki ( np. esp-easy)to w Domoticzu można coś takiego zrobić. i powiadomienia by szły na komórkę.

Na dzień dzisiejszy to można zrobić powiadomienie przy zbyt wysokiej temperaturze lub za niskiej w Domoticzu. tam te żsą wszystkie wykresy.

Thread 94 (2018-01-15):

problemy z dzialaniem tlok-a - ALARM

Gosir1, 2018-01-15:
```
#Konfiguracja sieci:
#Adres IP (dla automatycznej konfiguracji sieci piszemy: #NET_IP=auto):
NET_IP=192.168.2.4
#Adres MAC (w hex):
NET_MAC=000475B3323F
#Adresy pozostale
NET_BRAMA=192.168.2.1
NET_MASKA=255.255.255.0
NET_DNS=192.168.2.1

Parametry dmuchawy:
DM_OFFSET = 23
DM_INWERSJA_PWM = 1
DM_MODULACJA = 1
#jesli 0 - brak detektora lub detektor przed bezpiecznikiem od peryferiow
DETEKTOR_TESTUJE_BEZPIECZNIK=1

#algorytm regulacji mocy dmuchawy
# 0 stary, 1 nowy
DM_TYP=1

# zmiana czasu na zimowy
#RTC_ZIMA=1

#ustawianie daty/czasu w RTC - uruchamiac jednorazowo
#RTC=2017-04-07 12:13:14
#RTC_DATA=2017-04-07
#RTC_CZAS=12:13:14

# temperatura zewnetrzna auto przejscia CO w tryb lato
AUTOLATO_TEMP = 0
# histereza powrotu CO do trybu zima 1,5deg
AUTOLATO_HISTEREZA = 15
# temperatura dla twew auto przejsca CO w tryb lato
AUTOLATO_TWEW = 0
# dodatkowe tryb pracy autolato
AUTOLATO_TRYB = 0
# poza przejsciem w tryb lato wylaczamy calkowicie piec
#AUTOLATO_TRYB = WYL_ALGO

Parametry modulacji (gdy DM_MODULACJA = 1):
DM_ROZRUCH_CZAS =90
DM_ROZRUCH_MOC =40
DM_PLUS_CZAS =10
DM_PLUS_MOC =10
DM_DOPALANIE_CZAS =40
DM_DOPALANIE_MOC =30
DM_TLO_MOC =25

Parametry trybu zasypowego:
ZASYPOWY_MOC=30

Przypisanie wszystkich czujnikow z ecoal do sterownika
#T_MAPUJ_Z_ECOAL=1
lub
#T_MAPUJ_Z_BRULI=1

#przyklad mapowania czujnika dallas
# identyfikatory czujnikow dostepne pod adresem
# http://adres_ip_lucjana/dallas
# mapowanie czujnika poziomu zasobnika np.:
TPIEC=DALLAS[28FF3D79B5160336]
T2=DALLAS[28FF80D5B516032E]
TCWU=DALLAS[28FF280AC21604AE]
TPODLOGA=DALLAS[28FFEB51C216048E]
TZEW=DALLAS[28FF7A25C0160543]
TWEW=DALLAS[28FF3784B4160511]
TPODAJNIK=DALLAS[28FF6B05C2160493]
TPOWROT=DALLAS[28FFFCEAC1160442]
# mapowanie modulu termopary
TSPALINY = MAX31855[1]
#TSPALINY = MAX6675[0]
# zmapowanie na pinie CS=48 i z wlaczonym filtrowaniem
#TSPALINY = MAX6675[48.1]

#T4=SR04T[]

#przyklad dodania offsetu -10.0 deg do T1
#OFFSET_T1=-100

zabezpieczenie przed cofaniem sie zaru
jesli TPODAJNIK wzrosnie powyzej T_MAX, uruchamia sie podajnik
na czas wyrzutu paliwa z podajnika 5min. i uruchamia sie alarm
PODAJNIK_CZAS_WYRZUTU = 5
PODAJNIK_T_MAX = 75
jesli TPODAJNIK wzrosnie powyzej T_WYSOKA,
uruchamia sie cykle 30s (* max ilosc powtorek jesli ustawiono) podnoszenia zaru
PODAJNIK_CZAS_PODNOSZENIA = 30
PODAJNIK_T_WYSOKA_POWTORKI = 0
PODAJNIK_T_WYSOKA = 70

#parametry podajnika tlokowego
#czasy podawania w ilosci cykli
PODAJNIK_TLOKOWY=10
#czas pelnego ruchu tloka w sekundach
TLOK_CZAS_CYKLU=60

#czas w sekundach potrzebny do oproznienia peĹ‚nego zasobnika
PODAJNIK_CZAS_DO_OPROZNIENIA = 69000
#aktualny czas pozostaly do oproznienia zasobnika w sekundach
#UWAGA! po uruchomieniu zliczamy od tej wartosci
# (domyslnie 50% zasobnika) i tracimy poziom zasobnika!!
# poziom zasobnika ustawiac najlepiej przez WWW
#PODAJNIK_CZAS_PODAJNIKA = 34500
#procent ponizej ktorego ma wystapic alarm pustego zasobnika
#PODAJNIK_ALARM_MIN=15
#staĹ‚a zalezna od opaĹ‚u w g./min.
PODAJNIK_PREDKOSC_PODAWANIA = 200

zabezpieczenie przed zbyt wysoka temperatura pieca
PIEC_T_MAX = 90

temperatura zalaczenia pomp
PIEC_T_MIN = 40
po spadku temperatury ponizej 45 generowany jest alarm
#PIEC_ALARM_T_MIN = 45

tryb pracy pieca RECZNY,AUTO
PIEC_TRYB = AUTO
jesli piec ma automatycznie startowac po uruchomieniu - ustawiamy AUTO
w trybie recznym mozna wlaczac (1) lub wylaczac urzadzenia (0)
#OUT_PODAJNIK=1
#OUT_POMPACO=0
#OUT_POMPACWU=0
#OUT_POMPACWU2=0
#OUT_POMPACYRK=0
#moc wentylatora 50%:
#OUT_WENTYLATOR=50

algorytm pracy palnika - ECOAL,RR,RRM,RRM2,ZASYPOWY,WYLACZONY,...
PIEC_ALGORYTM = RRM
PIEC_ZADANA = 56
uwaga histereza pieca * 0.1deg
PIEC_HISTEREZA = 10

#zadana dla regulatora pokojowego
TWEW_ZADANA=25
#o ile ma zostac obnizona zadana na piecu
#gdy osiagniemy TWEW_ZADANA - ponizej o 5.0 deg.
#TWEW_CO_OBNIZONA=50

parametry algorytmu RR, czas podtrzymania w minutach, reszta w sekundach:
RR_PODTRZYMANIE_CZAS = 10
RR_PODTRZYMANIE_PODANIE = 10
RR_PODTRZYMANIE_POSTOJ = 30
RR_PODTRZYMANIE_MOC = 40
# gdy > 0 i sterownik jest w trybie lato korzystamy z czasu lato:
RR_PODTRZYMANIE_CZAS_LATO = 0

RR_PRACA_PODANIE = 10
RR_PRACA_POSTOJ = 30
RR_PRACA_MOC = 40

# 1 - wlaczone tlo, 2 - dopalanie
RRM_TLO_WLACZONE=2
RRM_TLO_MOC=20
RRM_TLO_CZAS_PODANIE=10
# w min.
RRM_TLO_CZAS=15
#jesli tlo podbije TPIEC 5deg ponad zadana przechodzimy w podtrzymanie
RRM_MAX_PRZEBICIE_TLO=5
# dopalanie 150s 30%
RRM_DOPALANIE_MOC=30
RRM_DOPALANIE_CZAS=150

# opcje naweglania - po 5 cyklach podtrzymania wejscie w grzanie
# powoduje podanie paliwa przez 60s. (max 240s)
#RRM_NAWEGLANIE_CYKL = 5
#RRM_NAWEGLANIE = 60
# opcja opoznienia podania paliwa po przejsciu w grzanie
# podajemy 30s pozniej
RRM_OPOZNIENIE_PODANIA = 30

# 1 - tryb wielomocowy dla RRM2
RRM_WIELE_MOCY=0
# moce od 0 (najmniejsza) do 5 (najwieksza)
# moc 0 domyslna
RRW_PODANIE0=10
RRW_POSTOJ0=100
RRW_NADMUCH0=30
# moc 1
RRW_PODANIE1=10
RRW_POSTOJ1= 50
RRW_NADMUCH1=40
RRW_HISTEREZA1=20

tryb pracy pompy co (ECOAL,BRULI,ZIMA,LATO)
CO_TRYB = ZIMA
algorytm pracy pomy CO (CIAGLY,CYKLICZNY)
CO_ALGORYTM = CIAGLY
# dla trybu cyklicznego
CO_CZAS_WLACZ=30
CO_CZAS_WYLACZ=30

#przyklad termostatu dla czujnika TWEW
# zadana 20.0 histereza 1.0, dla pompy CO
TERMOSTAT1_ZADANA = 20
TERMOSTAT1_HISTEREZA = 10
TERMOSTAT1_CZUJNIK = TWEW
TERMOSTAT1_WYJSCIE = CO

tryb pracy pompy cwu (ECOAL,BRULI,WLACZ,WYLACZ,MIESZANIE)
CWU_TRYB = WYLACZ
algorytm pracy pomy cwu (CIAGLY,CYKLICZNY)
CWU_ALGORYTM = CIAGLY
# uzyj priorytetu CWU wzgledem CO - WLACZ,WYLACZ
CWU_PRIORYTET = WYLACZ
CWU_ZADANA = 40
CWU_HISTEREZA = 0
zabezpieczenie przed zbyt wysoka t.cwu gdy CWU_T_MAX > 0
CWU_T_MAX = 0

CWU2_TRYB = WYLACZ
CWU2_ALGORYTM = CIAGLY
CWU2_ZADANA = 0
CWU2_HISTEREZA = 0
CWU2_CZUJNIK = TCWU

# praca pompki cyrkulacyjnej cwu: algorytm CIAGLY,CYKLICZNY,WYLACZONY
CYRKULACJA_ALGORYTM = WYLACZONY
# minimalna temperatura CWU przy ktorej bedzie dzialac cyrkulacja
CYRKULACJA_TMIN = 40
# parametry dla trybu cyklicznego w minutach:
CYRKULACJA_CZAS_WLACZ = 1
CYRKULACJA_CZAS_WYLACZ = 10

#harmonogram cyrkulacji
#*,PO,WT,SR,CZ,PT,SO,ND
#w poniedzialek 6-8 i 10-12
PROG_CYRK_PO=6:0-8:0
PROG_CYRK_PO=10:00-12:00
#we wszystkie dni tygodnia od 18:00-24:00
PROG_CYRK_*=18:00-

#krzywa grzania dla 4D (uwaga min.30 max 60):
KRZYWA_GRZANIA-30=55
KRZYWA_GRZANIA-20=55
KRZYWA_GRZANIA-10=48
KRZYWA_GRZANIA-0 =45
KRZYWA_GRZANIA+5 =45
KRZYWA_GRZANIA+15=30

# tryb pracy: WYLACZONY,ZADANA,KRZYWA (nastawa z krzywej grzania)
ZAWOR4D-TRYB=KRZYWA
#jesli TRYB ZADANA - to ponizej ustawiamy wartosc
ZAWOR4D-ZADANA=0
#ZAWOR4D parametry 120s pelne otwarcie, krok 2s,pomiar co 50s:
ZAWOR4D-CZAS_OTWARCIA = 120
ZAWOR4D-CZAS_KROK = 2
ZAWOR4D-CZAS_POMIARU = 50
# ktory czujnik polozony jest za zaworem i nalezy uzyc go do pomiaru
ZAWOR4D-CZUJNIK=T2
# histereza na + i na - od zadanej przy ktorej ma dzialac korekcja zaworu (w 0,1deg)
ZAWOR4D-HISTEREZA=15
# o ile deg. ma byc obnizona tzadana za zaworem jesli A6 zwarte do GND
ZAWOR4D-OBNIZONA=3
#pozycja startowa dla zaworu w % po uruchomieniu
#ZAWOR4D-PRESET=0

#autoryzacja www
#0 - brak, 1 - autoryzacja strony, 2 - autoryzacja api, 3 - autoryzacja api i strony
#WWW_AUTH=0
#login i haslo zakodowane w base64 np.: user:admin
#WWW_HASLO=dXNlcjphZG1pbg==

koniec pliku
```

Gosir1, 2018-01-15:
[putty.log.txt](https://github.com/uzi18/sterownik/files/1632527/putty.log.txt)
[config_.txt](https://github.com/uzi18/sterownik/files/1632528/config_.txt)

Gosir1, 2018-01-15:
1-59-20=39
0-59-20+59-20+3=39+39+3=81

Gosir1, 2018-01-17:
#Konfiguracja sieci:
#Adres IP (dla automatycznej konfiguracji sieci piszemy: #NET_IP=auto):
NET_IP=192.168.2.4
#Adres MAC (w hex):
NET_MAC=000475B3323F
#Adresy pozostale
NET_BRAMA=192.168.2.1
NET_MASKA=255.255.255.0
NET_DNS=192.168.2.1

Parametry dmuchawy:
DM_OFFSET = 23
DM_INWERSJA_PWM = 1
DM_MODULACJA = 1):
#jesli 0 - brak detektora lub detektor przed bezpiecznikiem od peryferiow
DETEKTOR_TESTUJE_BEZPIECZNIK=1

#algorytm regulacji mocy dmuchawy
# 0 stary, 1 nowy
DM_TYP=1

# zmiana czasu na zimowy
#RTC_ZIMA=1

#ustawianie daty/czasu w RTC - uruchamiac jednorazowo
#RTC=2017-04-07 12:13:14
#RTC_DATA=2017-04-07
#RTC_CZAS=12:13:14

# temperatura zewnetrzna auto przejscia CO w tryb lato
AUTOLATO_TEMP = 0
# histereza powrotu CO do trybu zima 1,5deg
AUTOLATO_HISTEREZA = 15
# temperatura dla twew auto przejsca CO w tryb lato
AUTOLATO_TWEW = 26
# dodatkowe tryb pracy autolato
AUTOLATO_TRYB = 0
# poza przejsciem w tryb lato wylaczamy calkowicie piec
#AUTOLATO_TRYB = WYL_ALGO

Parametry modulacji (gdy DM_MODULACJA = 1):
DM_ROZRUCH_CZAS =90
DM_ROZRUCH_MOC =40
DM_PLUS_CZAS =10
DM_PLUS_MOC =10
DM_DOPALANIE_CZAS =40
DM_DOPALANIE_MOC =30
DM_TLO_MOC =25

Parametry trybu zasypowego:
ZASYPOWY_MOC=30

Przypisanie wszystkich czujnikow z ecoal do sterownika
#T_MAPUJ_Z_ECOAL=1
lub
#T_MAPUJ_Z_BRULI=1

#przyklad mapowania czujnika dallas
# identyfikatory czujnikow dostepne pod adresem
# http://adres_ip_lucjana/dallas
# mapowanie czujnika poziomu zasobnika np.:
TPIEC=DALLAS[28FF3D79B5160336]
T2=DALLAS[28FF80D5B516032E]
TCWU=DALLAS[28FF280AC21604AE]
TPODLOGA=DALLAS[28FFEB51C216048E]
TZEW=DALLAS[28FF7A25C0160543]
TWEW=DALLAS[28FF3784B4160511]
TPODAJNIK=DALLAS[28FF6B05C2160493]
TPOWROT=DALLAS[28FFFCEAC1160442]
# mapowanie modulu termopary
TSPALINY = MAX31855[1]
#TSPALINY = MAX6675[0]
# zmapowanie na pinie CS=48 i z wlaczonym filtrowaniem
#TSPALINY = MAX6675[48.1]

#T4=SR04T[]

#przyklad dodania offsetu -10.0 deg do T1
#OFFSET_T1=-100

zabezpieczenie przed cofaniem sie zaru
jesli TPODAJNIK wzrosnie powyzej T_MAX, uruchamia sie podajnik
na czas wyrzutu paliwa z podajnika 5min. i uruchamia sie alarm
PODAJNIK_CZAS_WYRZUTU = 5
PODAJNIK_T_MAX = 75
jesli TPODAJNIK wzrosnie powyzej T_WYSOKA,
uruchamia sie cykle 30s (* max ilosc powtorek jesli ustawiono) podnoszenia zaru
PODAJNIK_CZAS_PODNOSZENIA = 30
PODAJNIK_T_WYSOKA_POWTORKI = 0
PODAJNIK_T_WYSOKA = 70

#parametry podajnika tlokowego
#czasy podawania w ilosci cykli<byĹ‚o
#PODAJNIK_TLOKOWY=1
#czas pelnego ruchu tloka w sekundach
#TLOK_CZAS_CYKLU=150

#czas w sekundach potrzebny do oproznienia peĹ‚nego zasobnika
PODAJNIK_CZAS_DO_OPROZNIENIA = 69000
#aktualny czas pozostaly do oproznienia zasobnika w sekundach
#UWAGA! po uruchomieniu zliczamy od tej wartosci
# (domyslnie 50% zasobnika) i tracimy poziom zasobnika!!
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
uzi18, 2018-01-17:
Duplicate of #84

uzi18, 2018-01-19:
Sprobuj z DM_TYP=0

uzi18, 2018-01-19:
v0.1.0.130.16
        - DALLAS: mozna zmniejszyc ilosc informacji w terminalu
        - tlok: poprawka dzialania na koncu cyklu i wydluzenie czasu dla czujnika
        - tlok: drobne poprawki
    - Domoticz: dodanie mozliwosci logowania informacji z terminala do pliku

uzi18, 2018-01-23:
uruchom tlok podczas logowania terminala przez putty, powiedzmy ze 2x niech sie pojawi blad abym mial porownanie i wrzuc tu plik logu, to zerkne co jeszcze moze byc nie tak.

uzi18, 2018-10-17:
tlok dziala??

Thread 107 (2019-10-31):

Pellet na Lucjanie ?

kmarcin84, 2019-10-31:
Czesc.
Gratuluje projektu.
Mam nadzieje ze koledzy beda mi w stanie pomodz w rozwiazaniu "problemu".
Jestem w trakcie skladania "Lucjana", ale od poczatku.
Postanowilem przerobic swojego smieciucha na pellet , ew groszek.
W tym celu powstal juz odpowiedni podajnik z palnikiem, teraz kwestia sterownika.

Pytanie:

1. Czy jest mozliwosc konfiguracji w ktoryms z algorytmow spalania trybu : "rozpalanie" , gdzie zalaczy mi odpowiednie wyjscie przekaznikowe na okreslony czas? Chodzi tutaj o zalaczenie grzalki ceramicznej przy automatycznym rozpalaniu pelletu.

Np:
- Podajnik powiedzmy 3 sekundy
- zalacz grzalke ceramiczna na xx
- zalacz dmuchawe na powiedzmy 40%
- odczyt temperatury z termopary (zamontowana pod palnikiem na pellet)
- wylacz jezeli temp > xx st C

2. Czy mozna odpowiednie wyjscie przekaznikowe/tyrystorowe konfigurowac z pliku TXT z karty SD, lub czy istnieje jakis spis akceptowanych przez sterownik komend ?

3. Czy algorytmy dmuchawy AC wymagaja ukladu na 2008 czy wystarczy tyrystorowy regulator (taki posiadam i dziala swietnie od min - max na posiadanej dmuchawie) - postaralbym sie ewentualnie dolaczyc sterowanie PWM z arduino do tego.

Bede wdzieczny za pomoc w temacie.

Pozdrawiam.

uzi18, 2019-10-31:
musze to przemyslec ale rozpalanie moge sprobowac Ci dodac jak znajde chwile z czym ostatnio krucho, na kiedy to potrzebujesz?

kmarcin84, 2019-10-31:
Jestem na etapie zabudowy elektroniki w obudowe rozdzielnicy i od odpalenia palnika dzieli mnie juz tylko podlaczenie sterownika wlasciwie.
Nie ukrywam że zależałoby mi na tej opcji jeżeli miałbyś chwilę.. Było by super.

Dmuchawa to AC, jakis standard z kondensatorem w srodku.

Tymczasowo mogę "rozpalarkę" wyrzucic na panel jakimś switchem choć kiedyś chciałbym zrobić to w automacie, miec mozliwosc sterownia np przez www.
Jezeli uda mi sie to odpalic to wrzucę na elektrodę kilka fotek i sprawozdanie.

Działam na ATMega+Wifi (Z esp8266 na jednej plycie) + eth shield, RTC shield jakis mam, ale musze eeprom dolozyc (po co on wogole?), do tego kilka dallasow : piec+cwu+tpodajnik prawdopodobnie + twew - tutaj jakis termostat jeszcze doloze do pokoju kiedys) no i 2 termopary - jedna w palniku druga na czopuch.  Zadnych zaworow 4d, jeden obieg.

uzi18, 2019-10-31:
na razie daj przycisk, ogolnie ze strony www da sie uruchomic piec, wystarczy ja troszke zmodyfikować - dodac przyciski

WojtekGD, 2019-11-04:
Cyt: "Zamontowalem jeszcze fotorezystor w drzwiczkach opodal palnika, ma wykrywac obecnosc plomienia."
To może się nie sprawdzić w piecu na pellet czujnik może dosyć szybko się brudzić - lepiej zrobić algorytm oparty o temperaturę paleniska - termopara + temp. spalin druga termopara.

uzi18, 2019-11-04:
zgadzam sie palenisko to nie jest miejsce na czujniki foto

kmarcin84, 2019-11-04:
Spokojnie koledzy.
Czujnik zamontowany jest nie w palenisku tylko w drzwiczkach.
Od drzwiczek odchodzi 5 cm rurki.
W rurce silikon temp》300°C > fotorezystor.
Dodatkowo odmuchiwany jest powietrzem a w drzwiczkach szklane oczko :)
Nie spali się..

Mozna tutaj foto dodac? Czy moze na jakims forum? [#esterownik.pl/elektroda.pl].
Jutro wezmę się za zabudowanie w rozdzielnicy elektroniki / może triaki na uniw. pcb polultuję - jak czas pozwoli...

uzi18, 2019-11-04:
wrzuc tu i tam :)

WojtekGD, 2019-11-04:
Dyskutujemy raczej tutaj: https://gitter.im/sterownik/Lobby?utm_source=badge&utm_medium=badge&utm_campaign=pr-badge&utm_content=badge co do czujnika nie tyle chodzi o jego zniszczenie co o zabrudzenie. Czujniki optyczne są stosowane w palnikach olejowych i gazowych ale tam przy prawidłowym wyregulowaniu palnika zanieczyści się po bardzo długim używaniu i spaliny trudno nazwać dymem. Dodatkowo umieszczony z reguły jest za deflektorem a tam trudno go zabrudzić jeśli palnik pracuje prawidłowo.

uzi18, 2020-02-23:
ok racja poprawilem ;)

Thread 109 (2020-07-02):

Nie problem ale pomysl na ewolucje

suenio, 2020-07-02:
W zwiazku z rozwojem ESP32 pomyslalem sobie ze fajnie byloby wykorzystac np R1 32 zamiast Arduino Mega jako baze. Jest to plytka ala UNO na bazie ESP32 ktory daje polaczenie wifi/BT + wystarczajaca ilosc GPIO (Digital and Analog). Chetnie bym sie w to zaangazowal gdyz wlasnie planuje budowe sterownika w oparciu o arduino i "Lucjana" dodajac do tego integracje z BLYNKiem.

uzi18, 2021-01-03:
@suenio  Przeciez bramke do BLYNK mozesz na bazie esp32 stworzyc w kazdej chwili, komunikowac sie z Mega przez rs232 i przesylac do i z blynk

daj link do plytki

suenio, 2021-01-04:
Tak oczywiscie mozna dodawac plytek coraz wiecej tylko pomysl byl ze skoro jest juz esp32 zamiast esp8266 to ma na tyle wyjsc/wejsc ze mozna zrobic to wszystko na jednej plytce czyli same I/O + bezprzewodowe polaczenie z internetem chodzi np o plytke
https://pl.aliexpress.com/item/1005001621901111.html
Sa tez wersje mini czy inne wersje esp32 ale to jest gabarytowo standardowe "UNO" wiec ogolnie latwiej :)

uzi18, 2021-01-04:
Juz o tym kiedys byla dyskusja, musielibysmy zrobic przynajmniej jeden moduł do sterowania dmuchawa w formie minimodulu. Wyjscia cyfrowe musialyby isc przez jakies ekspandery bo ich jest tu zdecydowanie za malo i wtedy to zaczyna miec sens.
Musialbym popatrzec bo moze cos sie zmieniło... poza tym jesli brac cos pod uwage to tylko ta bagatsza wersja esp32 a ciekawe jaka jest tutaj.

uzi18, 2021-01-04:
Chodzi o to ze musialby byc esp32 w wersji 2 rdzeniowej, bo jest kupa zabawy z tym aby wifi nie robilo balaganu i sie nic nie wieszali, przerabialismy to wszystko w projekcie ESPEasy.

suenio, 2021-01-04:
Ta plytka do ktorej podalem link jest w wersji 2 rdzeniowej. Posiadam na stanie i uzywam w kosiarce autonomicznej bo racja ze wifi samo z siebie a Blynk szczegolnie trzebaby osadzic na osobnym rdzeniu w stosunku do funkcji sterujacej piecem. Co do sterowania dmuchawa to nie do konca rozumiem bo PWM powinien wystarczyc ale moze sie myle. A co do wyjsc cyfrowych to zakladajac 5 pomp obiegowych i 10 czujnikow temperaturowych to jest 15 a wlasnie ten modul ma ich ponad 20scia w odroznieniu do starych ESP8266 ktore mialy krucho z wyjsciam IO. Ame moze cos pomijam co lucjan potrzbuje jesli chodzi o I/O

uzi18, 2022-02-24:
@suenio fakt te esp32 sa dosc ciekawe i troche juz stabilniej dzialaja

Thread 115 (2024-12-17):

Wysyłanie temperatur po mqtt

swiezaks, 2024-12-17:
Cześć- @uzi18 jest szansa dodać do sterownika wysyłanie danych po mqtt do dowolnego brokera?

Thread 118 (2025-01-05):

zmiana pinu sterowania pompą CWU

swiezaks, 2025-01-05:
Cześć.
Czy jest możliwość zmiany piny do obsługi pompki CWU?
Nie wiem co się wydarzyło ale na pinach a14 i a15 mam 10V (sprawdzane 2 miernikami) i nie mogę wysterować działania pompki cwu. Nie wiem jakim cudem bo teoretycznie arduino już powinno być ugotowane a wszystko inne działa. na ten moment steruję ręcznie.
Jest to wogóle możliwe żeby na porcie arduino było 10V ?
Do tej pory wszystko działało od 4lat bez najmniejszego problemu.

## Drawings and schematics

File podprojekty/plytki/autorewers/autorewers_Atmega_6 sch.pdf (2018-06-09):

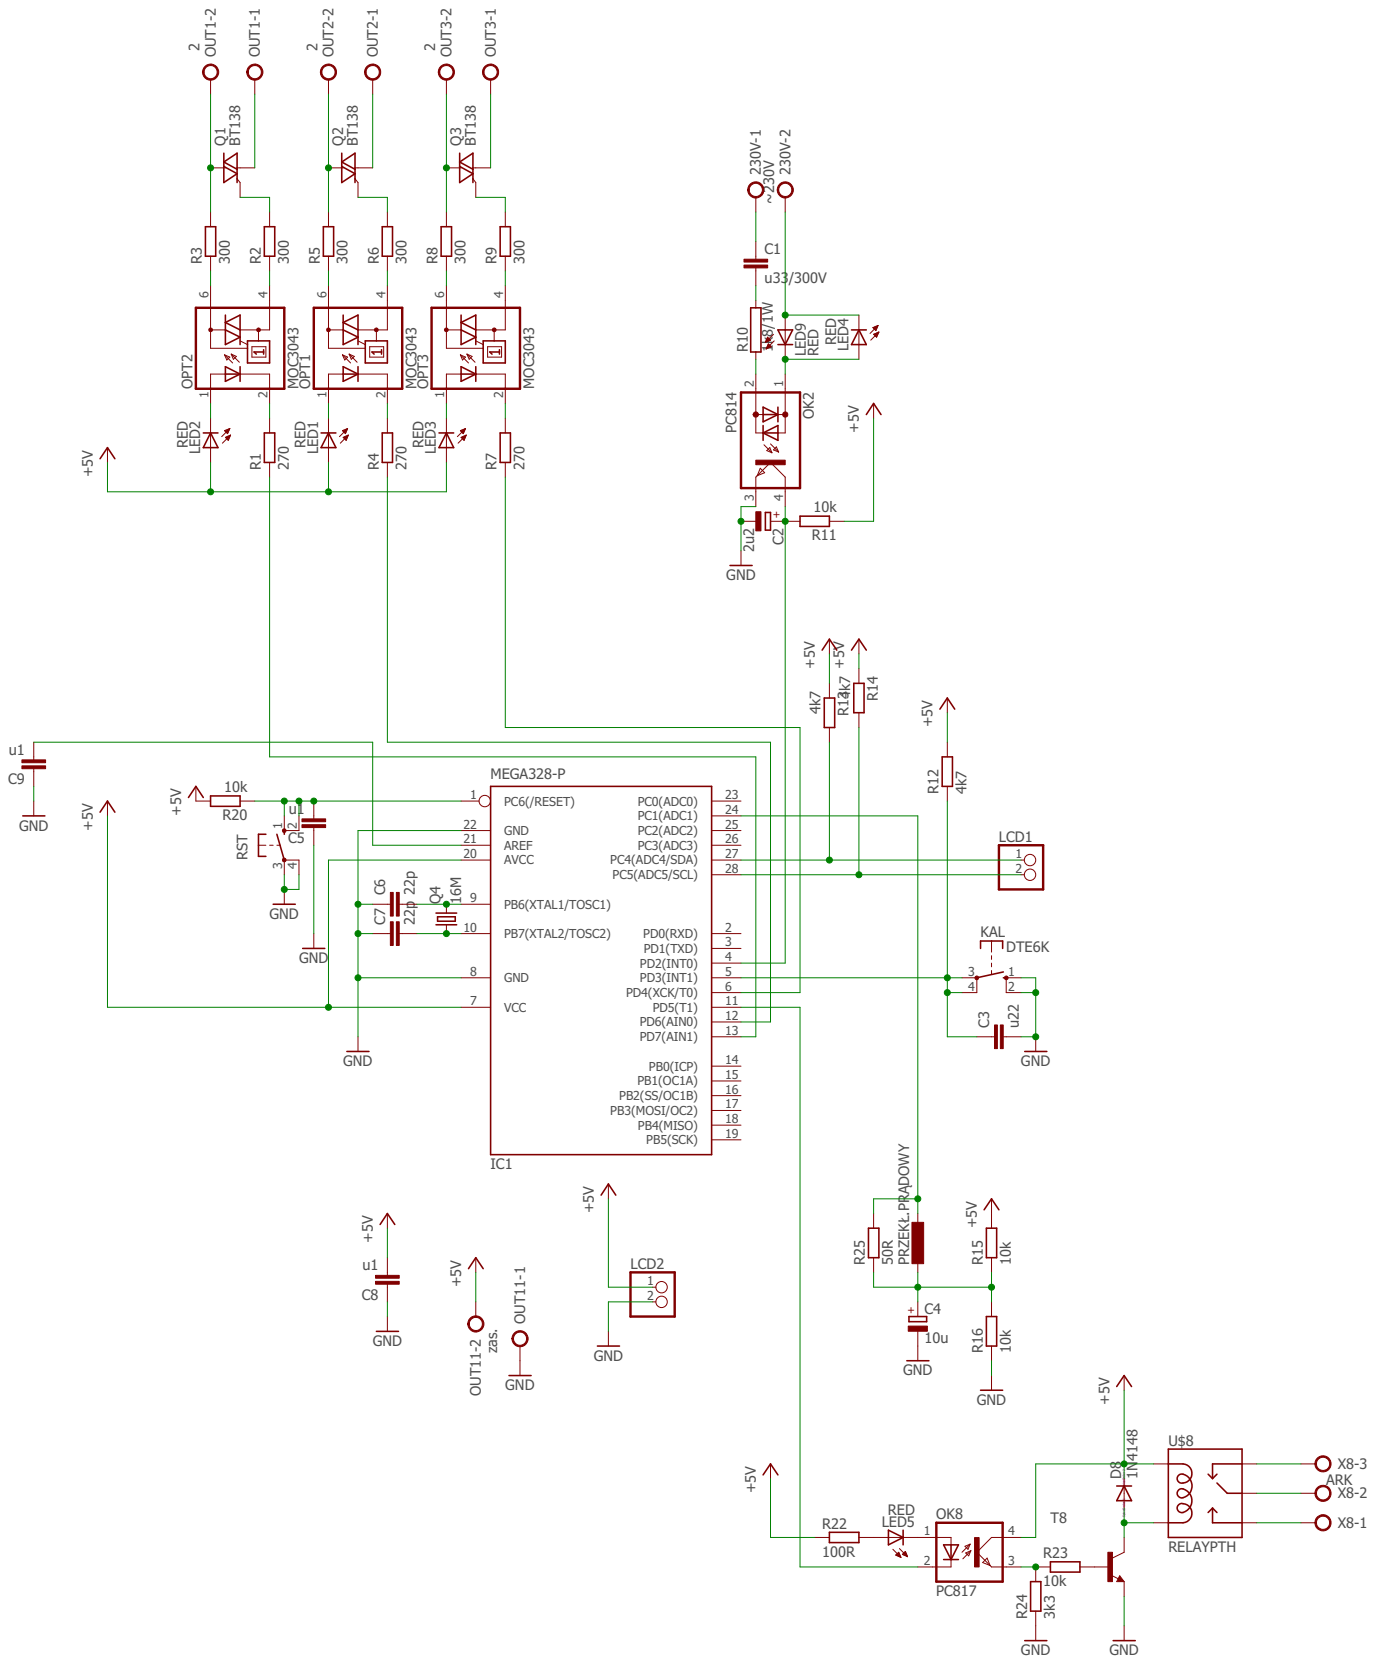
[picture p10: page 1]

SpiceOrder 1 SpiceOrder 2 GND MOC3043 270 300 300 BT138 2 RED GND ~230V 1k8/1W RED 10k +5V GND GND zas. +5V PC814 +5V MOC3043 270 300 300 BT138 2 RED MOC3043 270 300 300 BT138 2 RED u33/300V RED 2u2 4k7 +5V u22 DTE6K 4k74k7 +5V +5V GND 10k 10k +5V GND 10u GND MEGA328-P +5V10k GND ARK PC817 100R RELAYPTH 1N4148 3k3 GND GND 10k +5V +5V +5V u1GND 16M22p 22p u1+5V GND 50R RED +5V u1GND OPT2 12 64 R1 R3R2 Q1 OUT1-1 OUT1-2 LED2 230V-1 230V-2 R10 LED9 R11 OUT11-1 OUT11-2 OK2 21 34 OPT1 12 64 R4 R5R6 Q2 OUT2-1 OUT2-2 LED1 OPT3 12 64 R7 R8R9 Q3 OUT3-1 OUT3-2 LED3 C1 LED4 C2 R12 C3 KAL 3 1 4 2 R13R14 LCD112 LCD212 PRZEKŁ.PRĄDOWY R15 R16 C4 IC1 PB5(SCK) 19 PB7(XTAL2/TOSC2) 10 PB6(XTAL1/TOSC1) 9 GND 8 VCC 7 GND 22 AREF 21 AVCC 20 PB4(MISO) 18 PB3(MOSI/OC2) 17 PB2(SS/OC1B) 16 PB1(OC1A) 15 PB0(ICP) 14 PD7(AIN1) 13 PD6(AIN0) 12 PD5(T1) 11 PD4(XCK/T0) 6 PD3(INT1) 5 PD2(INT0) 4 PD1(TXD) 3 PD0(RXD) 2 PC5(ADC5/SCL) 28 PC4(ADC4/SDA) 27 PC3(ADC3) 26 PC2(ADC2) 25 PC1(ADC1) 24 PC0(ADC0) 23 PC6(/RESET) 1 R20RST 3 12 4 X8-1 X8-2 X8-3 OK8 12 34 U$8 T8 R22 D8 R24 R23 C5 QC46 C7 C8 R25 LED5 C9 + +

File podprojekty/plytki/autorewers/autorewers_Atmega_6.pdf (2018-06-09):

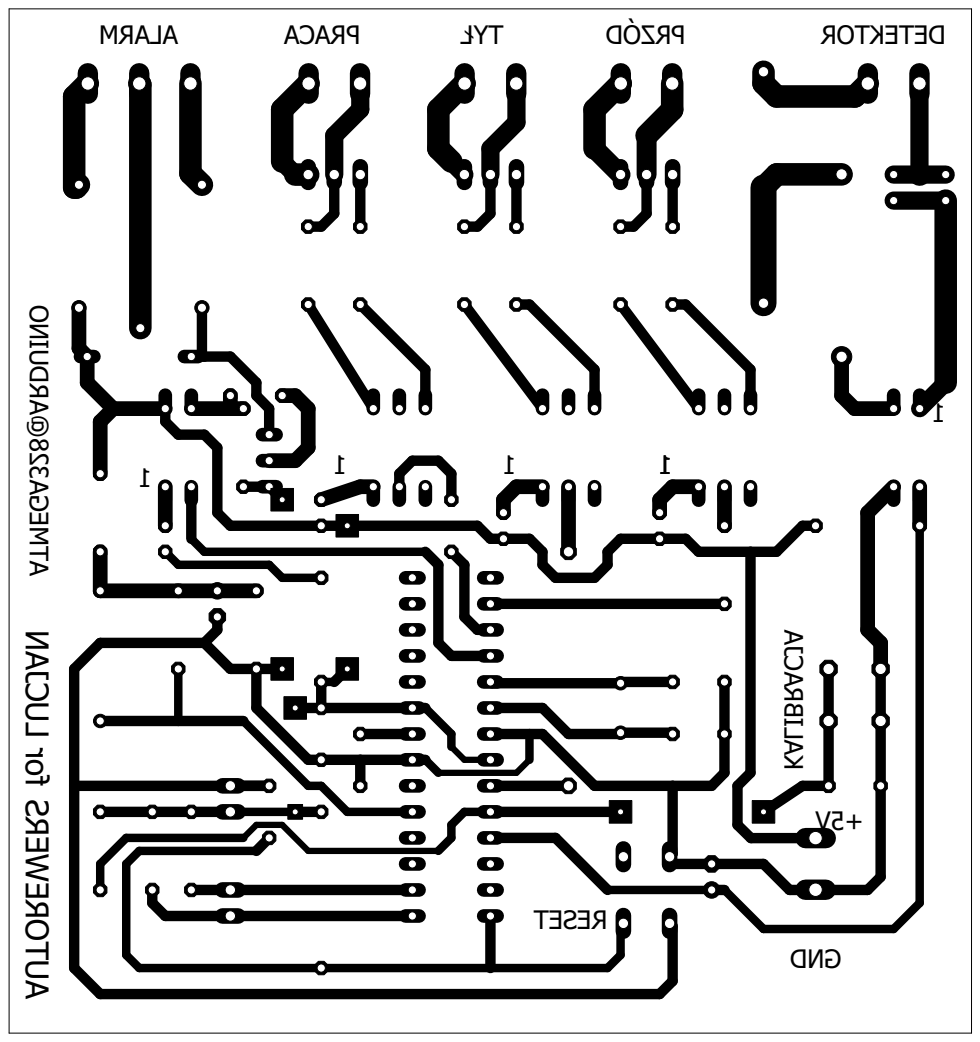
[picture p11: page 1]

AUTOREWERS MRALA ACARP ŁYT DÓZRP V5 + DNGROTKETED KALIBRACJA 1 1 1 TESER for LUCJAN ATMEGA328@ARDUINO 1 1

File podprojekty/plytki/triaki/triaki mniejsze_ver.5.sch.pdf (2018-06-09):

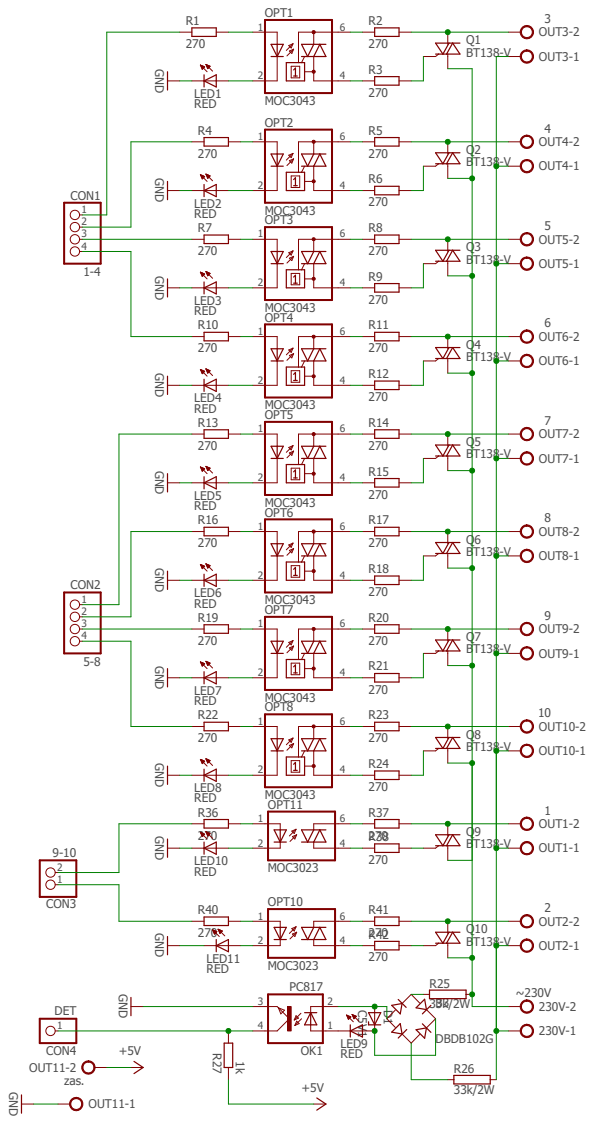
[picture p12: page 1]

GND GND GND GND GND

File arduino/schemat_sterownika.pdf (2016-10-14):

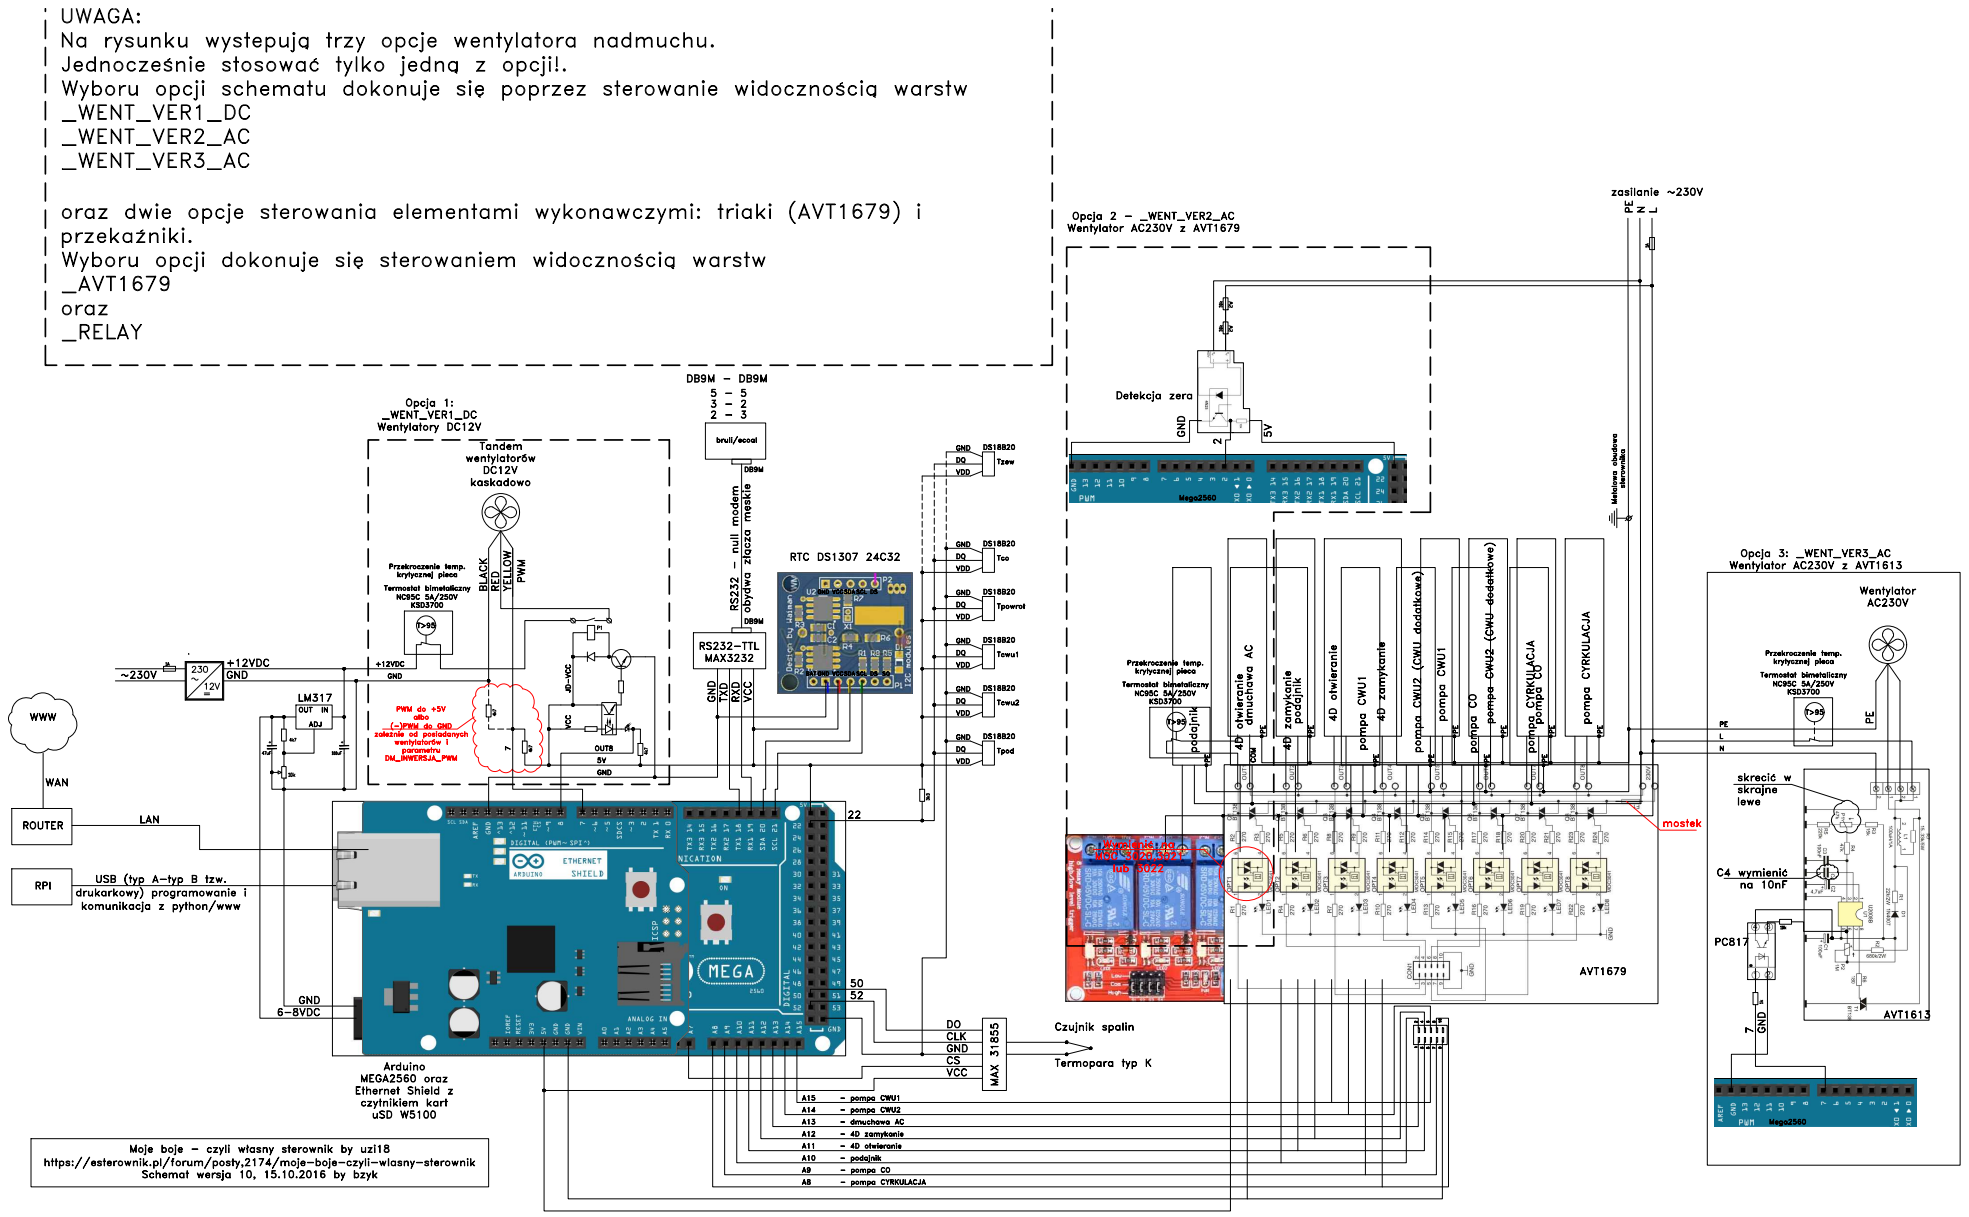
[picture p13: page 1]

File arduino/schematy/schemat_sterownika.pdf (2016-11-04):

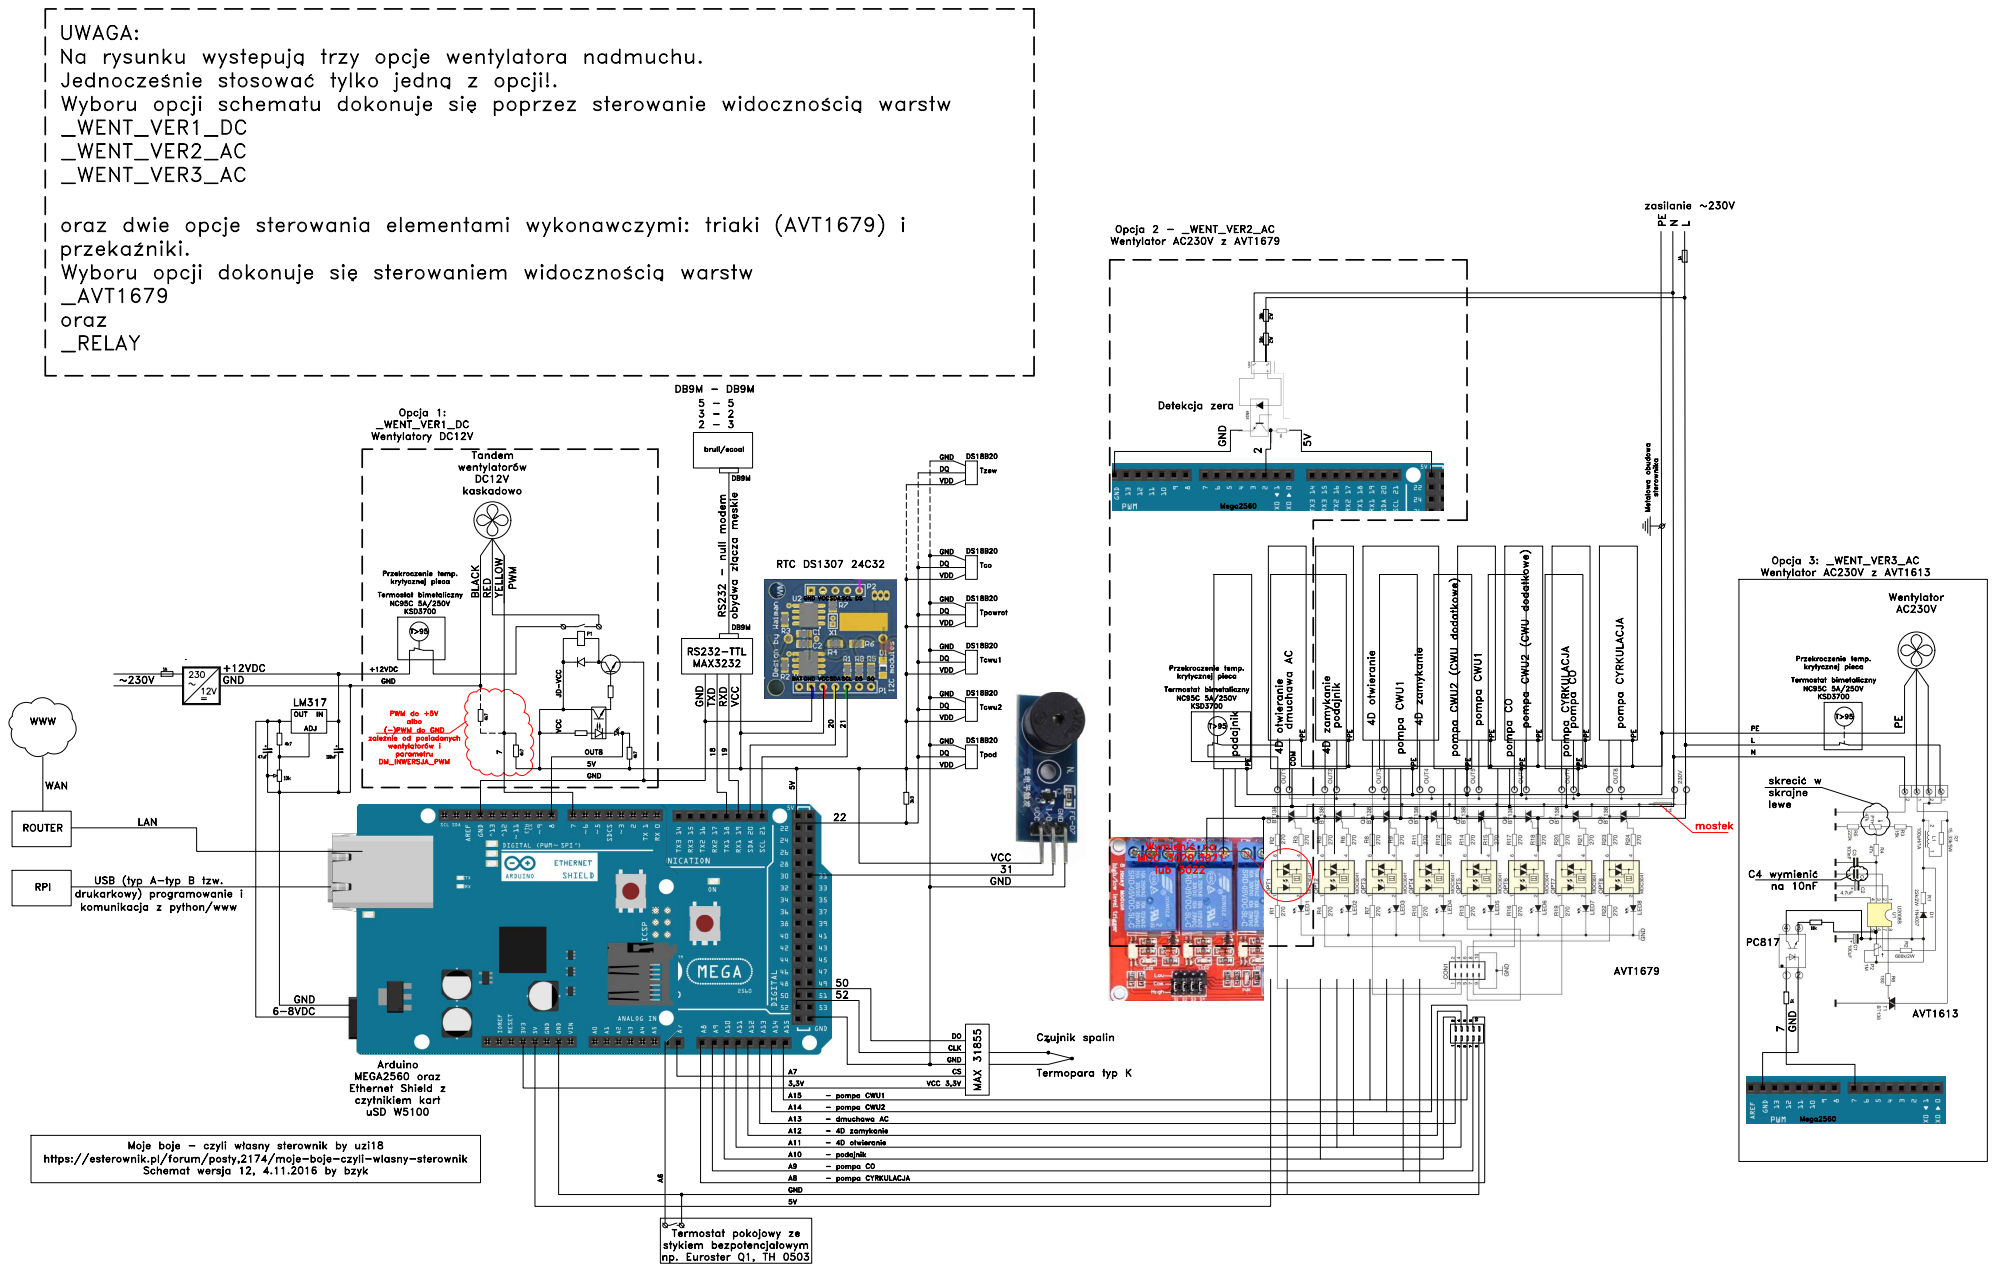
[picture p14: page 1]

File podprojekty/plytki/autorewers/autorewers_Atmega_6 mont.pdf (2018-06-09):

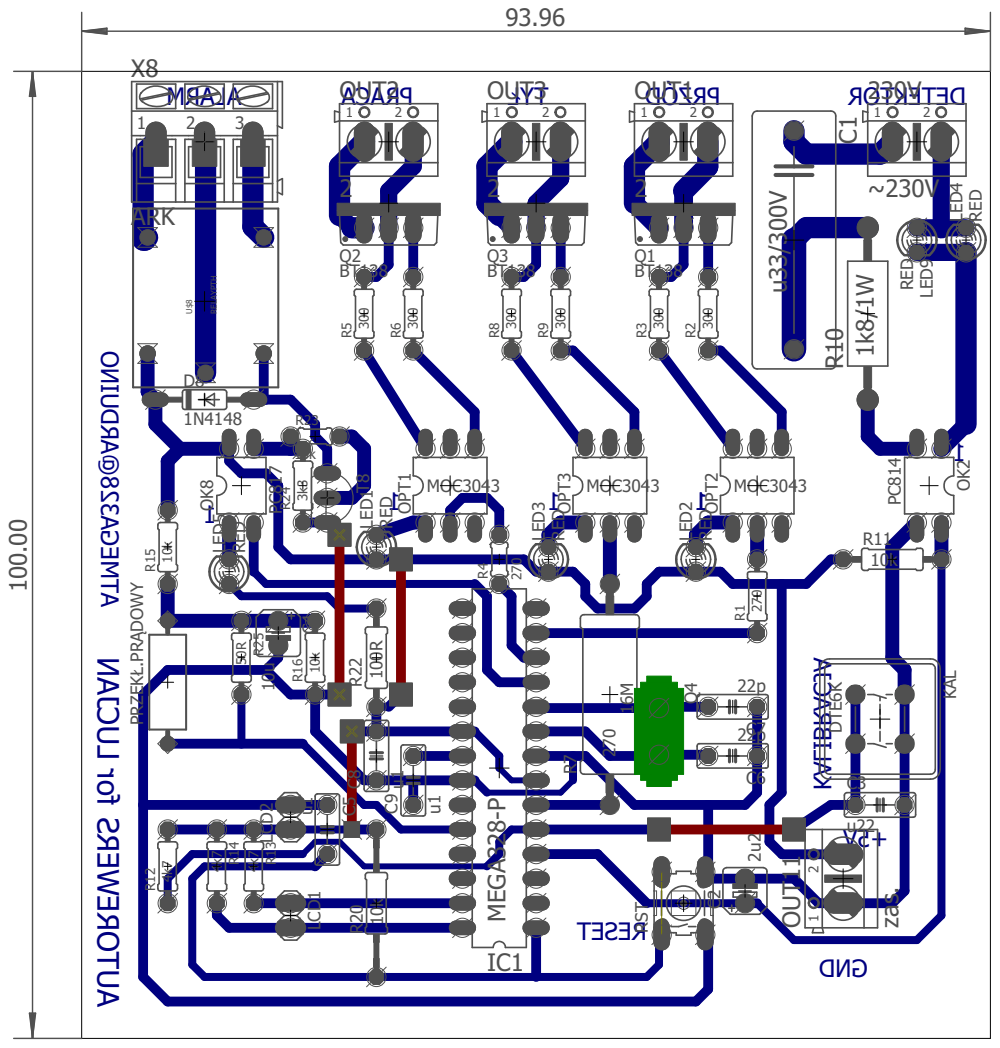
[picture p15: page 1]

REWERS MRALA ACARP ŁYT DÓZRP

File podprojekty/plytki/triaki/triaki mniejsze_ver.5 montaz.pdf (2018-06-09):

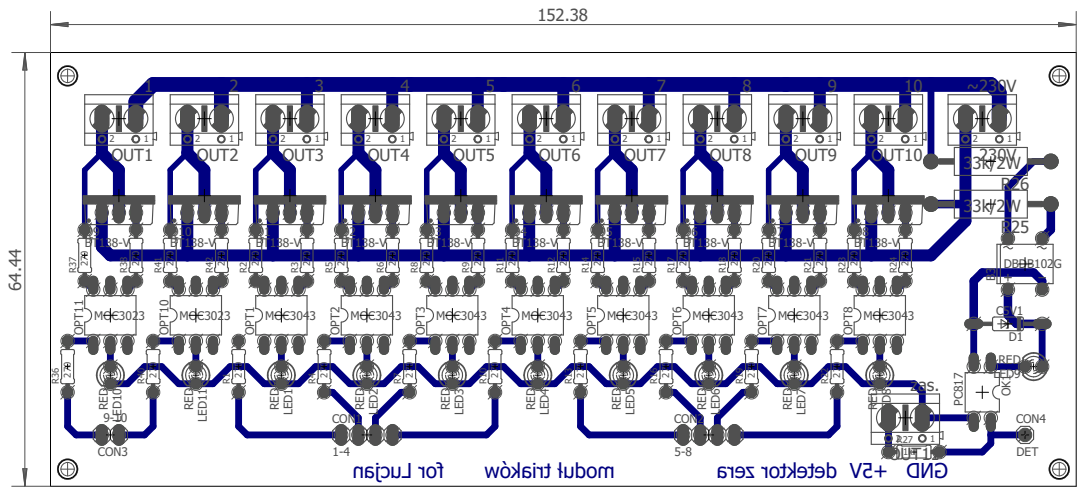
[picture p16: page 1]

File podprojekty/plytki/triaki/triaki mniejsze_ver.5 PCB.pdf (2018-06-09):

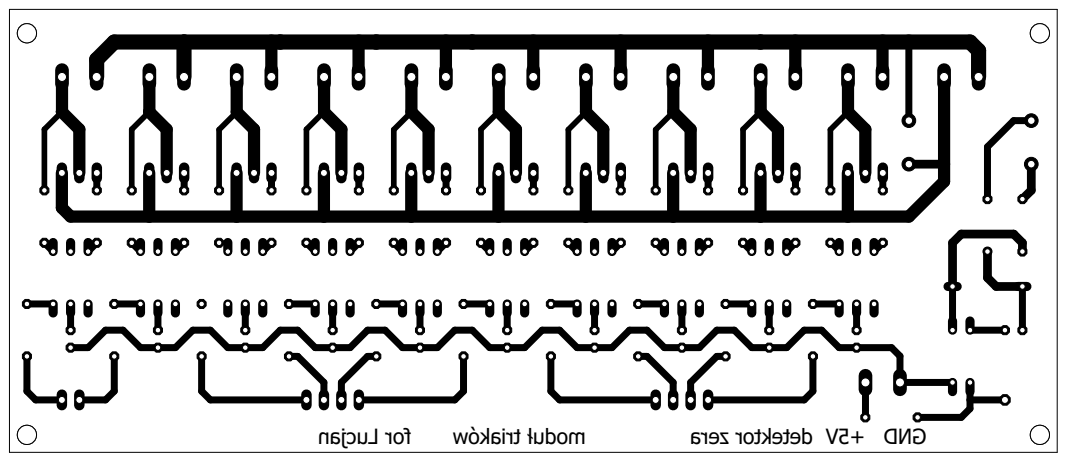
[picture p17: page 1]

naj cuL r of wókairt ł udo m ar ez r ot ket ed V5 + DNG

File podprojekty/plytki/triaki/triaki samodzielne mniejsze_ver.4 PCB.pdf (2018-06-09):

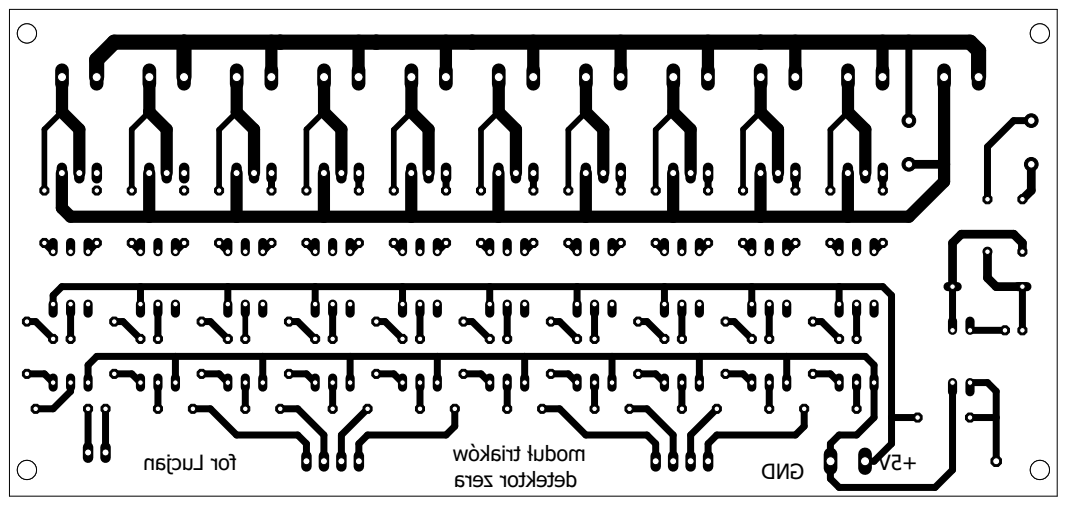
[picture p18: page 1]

naj cuL r of wókairt ł udo m ar ez r ot ket ed DNG V5 +

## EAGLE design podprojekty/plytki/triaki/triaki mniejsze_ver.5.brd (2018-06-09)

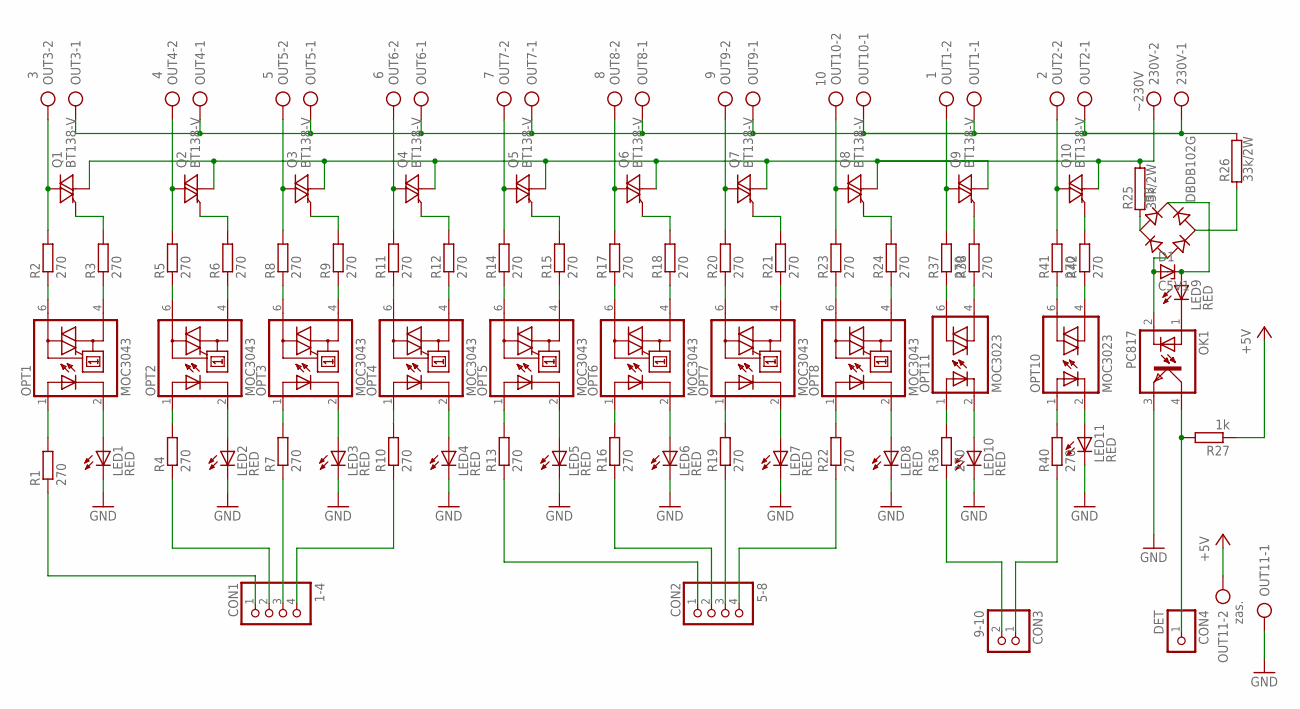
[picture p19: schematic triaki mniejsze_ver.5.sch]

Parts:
230V: ~230V; AK500/2
B3: DBDB102G; DB
CON1: 1-4; 1X04
CON2: 5-8; 1X04
CON3: 9-10; 1X02
CON4: DET; 1X01
D1: C5V1; DO35Z10
LED1, LED2, LED3, LED4, LED5, LED6, LED7, LED8, LED9, LED10, LED11: RED; LED3MM
OK1: PC817; DIL04
OPT1, OPT2, OPT3, OPT4, OPT5, OPT6, OPT7, OPT8: MOC3043; DIL06; MPN MOC3041
OPT10, OPT11: MOC3023; DIL06; MPN MOC3021
OUT1: 1; AK500/2
OUT2: 2; AK500/2
OUT3: 3; AK500/2
OUT4: 4; AK500/2
OUT5: 5; AK500/2
OUT6: 6; AK500/2
OUT7: 7; AK500/2
OUT8: 8; AK500/2
OUT9: 9; AK500/2
OUT10: 10; AK500/2
OUT11: zas.; AK500/2
Q1, Q2, Q3, Q4, Q5, Q6, Q7, Q8, Q9, Q10: BT138-V; TO220BV
R1, R2, R3, R4, R5, R6, R7, R8, R9, R10, R11, R12, R13, R14, R15, R16, R17, R18, R19, R20, R21, R22, R23, R24, R36, R37, R38, R40, R41, R42: 270; 0204/7
R25, R26: 33k/2W; AC01
R27: 1k; 0204/7

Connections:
+5V: OUT11.2, R27.1
GND: LED1.K (C), LED2.K (C), LED3.K (C), LED4.K (C), LED5.K (C), LED6.K (C), LED7.K (C), LED8.K (C), LED10.K (C), LED11.K (C), OK1.3 (EMIT), OUT11.1
unnamed: OPT1.4 (A1), R3.1
unnamed: OPT11.1 (A), R36.2
unnamed: LED1.A, OPT1.2 (C)
unnamed: Q1.G, R3.2
unnamed: OUT3.2, Q1.T2 (A2), R2.2
unnamed: OPT10.1 (A), R40.2
unnamed: OPT2.6 (A2), R5.1
unnamed: OPT8.1 (A), R22.2
unnamed: Q2.G, R6.2
unnamed: OPT2.4 (A1), R6.1
unnamed: 230V.1, OUT1.1, OUT2.1, OUT3.1, OUT4.1, OUT5.1, OUT6.1, OUT7.1, OUT8.1, OUT9.1, OUT10.1, R26.2
unnamed: LED2.A, OPT2.2 (C)
unnamed: OPT7.1 (A), R19.2
unnamed: OPT6.1 (A), R16.2
unnamed: OPT3.6 (A2), R8.1
unnamed: OUT5.2, Q3.T2 (A2), R8.2
unnamed: Q3.G, R9.2
unnamed: OPT3.4 (A1), R9.1
unnamed: LED9.K (C), OK1.1 (A)
unnamed: OPT5.1 (A), R13.2
unnamed: LED3.A, OPT3.2 (C)
unnamed: OPT4.1 (A), R10.2
unnamed: OPT3.1 (A), R7.2
unnamed: OPT4.6 (A2), R11.1
unnamed: OUT6.2, Q4.T2 (A2), R11.2
unnamed: Q4.G, R12.2
unnamed: OPT4.4 (A1), R12.1
unnamed: OPT2.1 (A), R4.2
unnamed: CON1.3, R7.1
unnamed: LED4.A, OPT4.2 (C)
unnamed: CON1.4, R10.1
unnamed: CON1.2, R4.1
unnamed: OPT5.6 (A2), R14.1
unnamed: OUT7.2, Q5.T2 (A2), R14.2
unnamed: Q5.G, R15.2
unnamed: OPT5.4 (A1), R15.1
unnamed: CON1.1, R1.1
unnamed: CON2.3, R19.1
unnamed: LED5.A, OPT5.2 (C)
unnamed: B3.+, D1.C, LED9.A
unnamed: OPT6.6 (A2), R17.1
unnamed: OUT8.2, Q6.T2 (A2), R17.2
unnamed: Q6.G, R18.2
unnamed: OPT6.4 (A1), R18.1
unnamed: B3.AC1, R25.1
unnamed: B3.AC2, R26.1
unnamed: LED6.A, OPT6.2 (C)
unnamed: CON2.4, R22.1
unnamed: CON2.2, R16.1
unnamed: OPT7.6 (A2), R20.1
unnamed: OUT9.2, Q7.T2 (A2), R20.2
unnamed: Q7.G, R21.2
unnamed: OPT7.4 (A1), R21.1
unnamed: Q9.G, R38.2
unnamed: B3.-, D1.A, OK1.2 (C)
unnamed: LED7.A, OPT7.2 (C)
unnamed: CON2.1, R13.1
unnamed: CON3.1, R40.1
unnamed: OPT8.6 (A2), R23.1
unnamed: OUT10.2, Q8.T2 (A2), R23.2
unnamed: Q8.G, R24.2
unnamed: OPT8.4 (A1), R24.1
unnamed: CON3.2, R36.1
unnamed: OPT11.4 (A1), R38.1
unnamed: LED8.A, OPT8.2 (C)
unnamed: OPT10.4 (A1), R42.1
unnamed: Q10.G, R42.2
unnamed: LED10.A, OPT11.2 (C)
unnamed: OPT11.6 (A2), R37.1
unnamed: OUT1.2, Q9.T2 (A2), R37.2
unnamed: 230V.2, Q1.T1 (A1), Q2.T1 (A1), Q3.T1 (A1), Q4.T1 (A1), Q5.T1 (A1), Q6.T1 (A1), Q7.T1 (A1), Q8.T1 (A1), Q10.T1 (A1), R25.2
unnamed: OPT10.6 (A2), R41.1
unnamed: LED11.A, OPT10.2 (C)
unnamed: OUT2.2, Q10.T2 (A2), R41.2
unnamed: CON4.1, OK1.4 (COL), R27.2
unnamed: OUT4.2, Q2.T2 (A2), R5.2

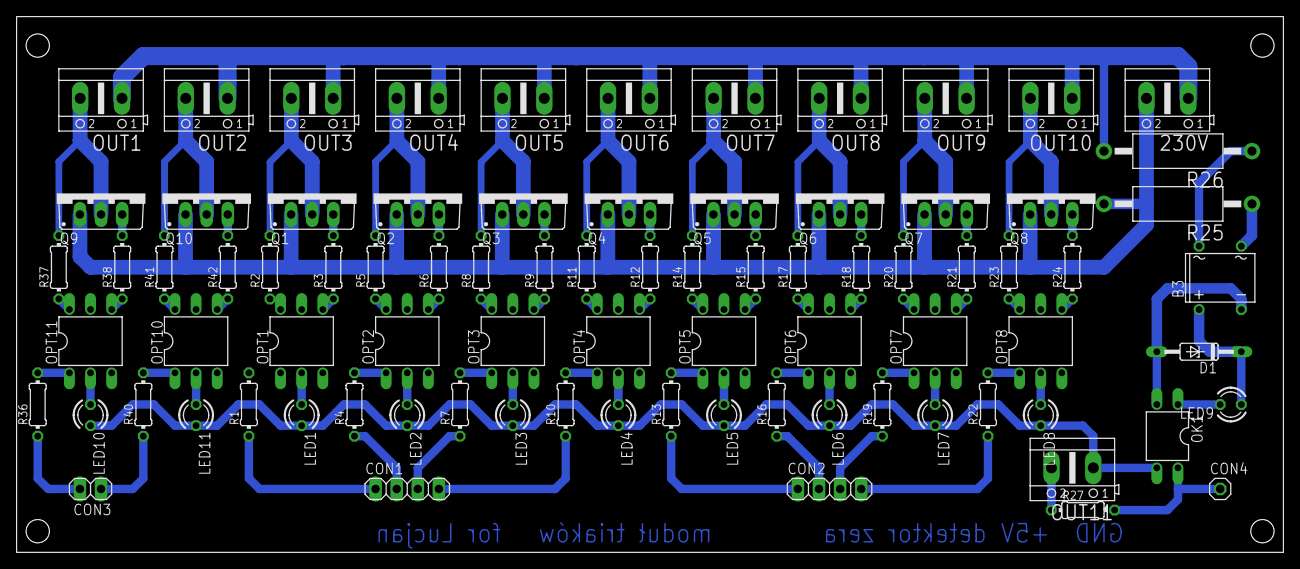
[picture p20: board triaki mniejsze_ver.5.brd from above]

Board: 2 copper layers, 152.4 x 64.4 mm, 83 parts (0 on the bottom side), 78 nets.

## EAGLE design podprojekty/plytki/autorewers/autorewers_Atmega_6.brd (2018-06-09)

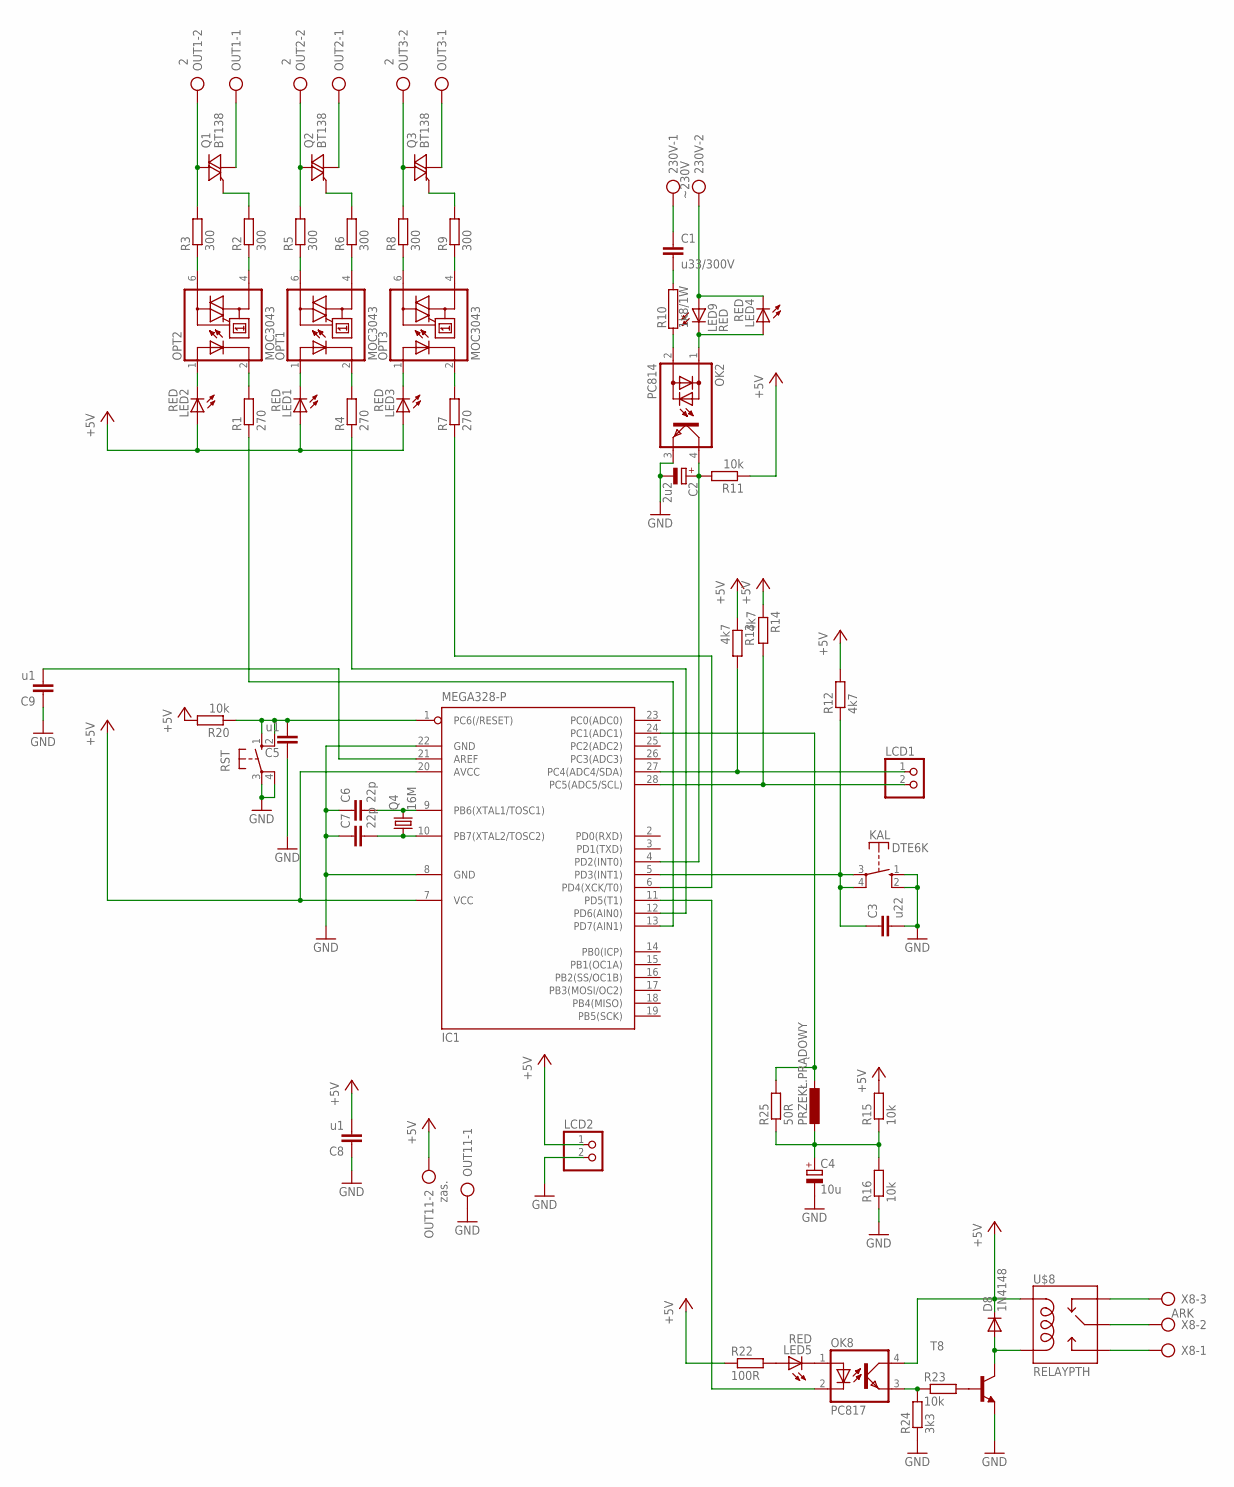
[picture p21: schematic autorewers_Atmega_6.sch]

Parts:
230V: ~230V; AK500/2
C1: u33/300V; C225-087X268
C2: 2u2; B45181A
C3: u22; C050-025X075
C4: 10u; B45181A
C5, C8, C9: u1; C050-025X075
C6, C7: 22p; C050-025X075
D8: 1N4148; DO35-10
IC1: MEGA328-P; DIL28-3
KAL: DTE6K
LCD1, LCD2: PINHD-1X2; 1X02
LED1, LED2, LED3, LED4, LED5, LED9: RED; LED3MM
OK2: PC814; DIL04
OK8: PC817; DIL04
OPT1, OPT2, OPT3: MOC3043; DIL06; MPN MOC3041
OUT1, OUT2, OUT3: 2; AK500/2
OUT11: zas.; AK500/2
PRZEKŁ.PRĄDOWY: L-EU2200-12.7; 2200-12.7
Q1, Q2, Q3: BT138; TO220BV
Q4: 16M; HC49/S
R1: 270; 0204/7
R2, R3, R5, R6, R8, R9: 300; 0204/7
R4: 270; 0204/5
R7: 270; 0617/22
R10: 1k8/1W; AC01
R11: 10k; 0207/10
R12, R13, R14: 4k7; 0204/7
R15, R16: 10k; 0204/7
R20: 10k; 0207/15
R22: 100R; 0207/10
R23: 10k; 0204/5
R24: 3k3; 0204/7
R25: 50R; 0204/7
RST: 10-XX; B3F-10XX
T8: BC237-NPN-TO92-CBE; TO92-CBE
U$8: RELAYPTH; SRD-05VDC-SL-C
X8: ARK; AK300/3

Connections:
+5V: C8.2, D8.C, IC1.7 (VCC), IC1.20 (AVCC), LCD2.1, LED1.A, LED2.A, LED3.A, OK8.4 (COL), OUT11.2, R11.1, R12.2, R13.1, R14.1, R15.2, R20.2, R22.1, U$8.COIL1
GND: C2.-, C3.2, C4.-, C5.1, C6.1, C7.1, C8.1, C9.1, IC1.8 (GND), IC1.22 (GND), KAL.1 (S), KAL.2 (S), LCD2.2, OK2.3 (E), OUT11.1, R16.1, R24.1, RST.3, RST.4 (P1), T8.E
unnamed: OUT1.1, Q1.T1 (A1)
unnamed: C2.+, IC1.4 (PD2(INT0)), OK2.4 (C), R11.2
unnamed: LED2.K (C), OPT2.1 (A)
unnamed: OPT2.2 (C), R1.2
unnamed: OPT1.6 (A2), R5.1
unnamed: Q2.G, R6.2
unnamed: OPT1.4 (A1), R6.1
unnamed: OPT2.6 (A2), R3.1
unnamed: OUT2.2, Q2.T2 (A2), R5.2
unnamed: Q1.G, R2.2
unnamed: OPT2.4 (A1), R2.1
unnamed: LED1.K (C), OPT1.1 (A)
unnamed: OPT1.2 (C), R4.2
unnamed: OPT3.6 (A2), R8.1
unnamed: Q3.G, R9.2
unnamed: OPT3.4 (A1), R9.1
unnamed: OUT3.2, Q3.T2 (A2), R8.2
unnamed: LED3.K (C), OPT3.1 (A)
unnamed: OPT3.2 (C), R7.2
unnamed: 230V.2, LED4.K (C), LED9.A
unnamed: OUT3.1, Q3.T1 (A1)
unnamed: C1.2, R10.2
unnamed: OK2.2 (AC2), R10.1
unnamed: LED4.A, LED9.K (C), OK2.1 (AC1)
unnamed: C3.1, IC1.5 (PD3(INT1)), KAL.3, KAL.4, R12.1
unnamed: 230V.1, C1.1
unnamed: IC1.12 (PD6(AIN0)), R4.1
unnamed: IC1.6 (PD4(XCK/T0)), R7.1
unnamed: IC1.24 (PC1(ADC1)), PRZEKŁ.PRĄDOWY.1, R25.2
unnamed: IC1.13 (PD7(AIN1)), R1.1
unnamed: C6.2, IC1.9 (PB6(XTAL1/TOSC1)), Q4.2
unnamed: C4.+, PRZEKŁ.PRĄDOWY.2, R15.1, R16.2, R25.1
unnamed: U$8.SWOPEN, X8.1
unnamed: U$8.SWCLOSED (SWCLOSE), X8.3
unnamed: LED5.K (C), OK8.1 (A)
unnamed: C5.2, IC1.1 (PC6(/RESET)), R20.1, RST.1 (S), RST.2 (S1)
unnamed: IC1.11 (PD5(T1)), OK8.2 (C)
unnamed: LED5.A, R22.2
unnamed: IC1.27 (PC4(ADC4/SDA)), LCD1.1, R13.2
unnamed: C7.2, IC1.10 (PB7(XTAL2/TOSC2)), Q4.1
unnamed: IC1.28 (PC5(ADC5/SCL)), LCD1.2, R14.2
unnamed: OUT2.1, Q2.T1 (A1)
unnamed: OK8.3 (EMIT), R23.1, R24.2
unnamed: R23.2, T8.B
unnamed: D8.A, T8.C, U$8.COIL0
unnamed: U$8.SWCOMMON, X8.2
unnamed: OUT1.2, Q1.T2 (A2), R3.2
S$1: C9.2, IC1.21 (AREF)

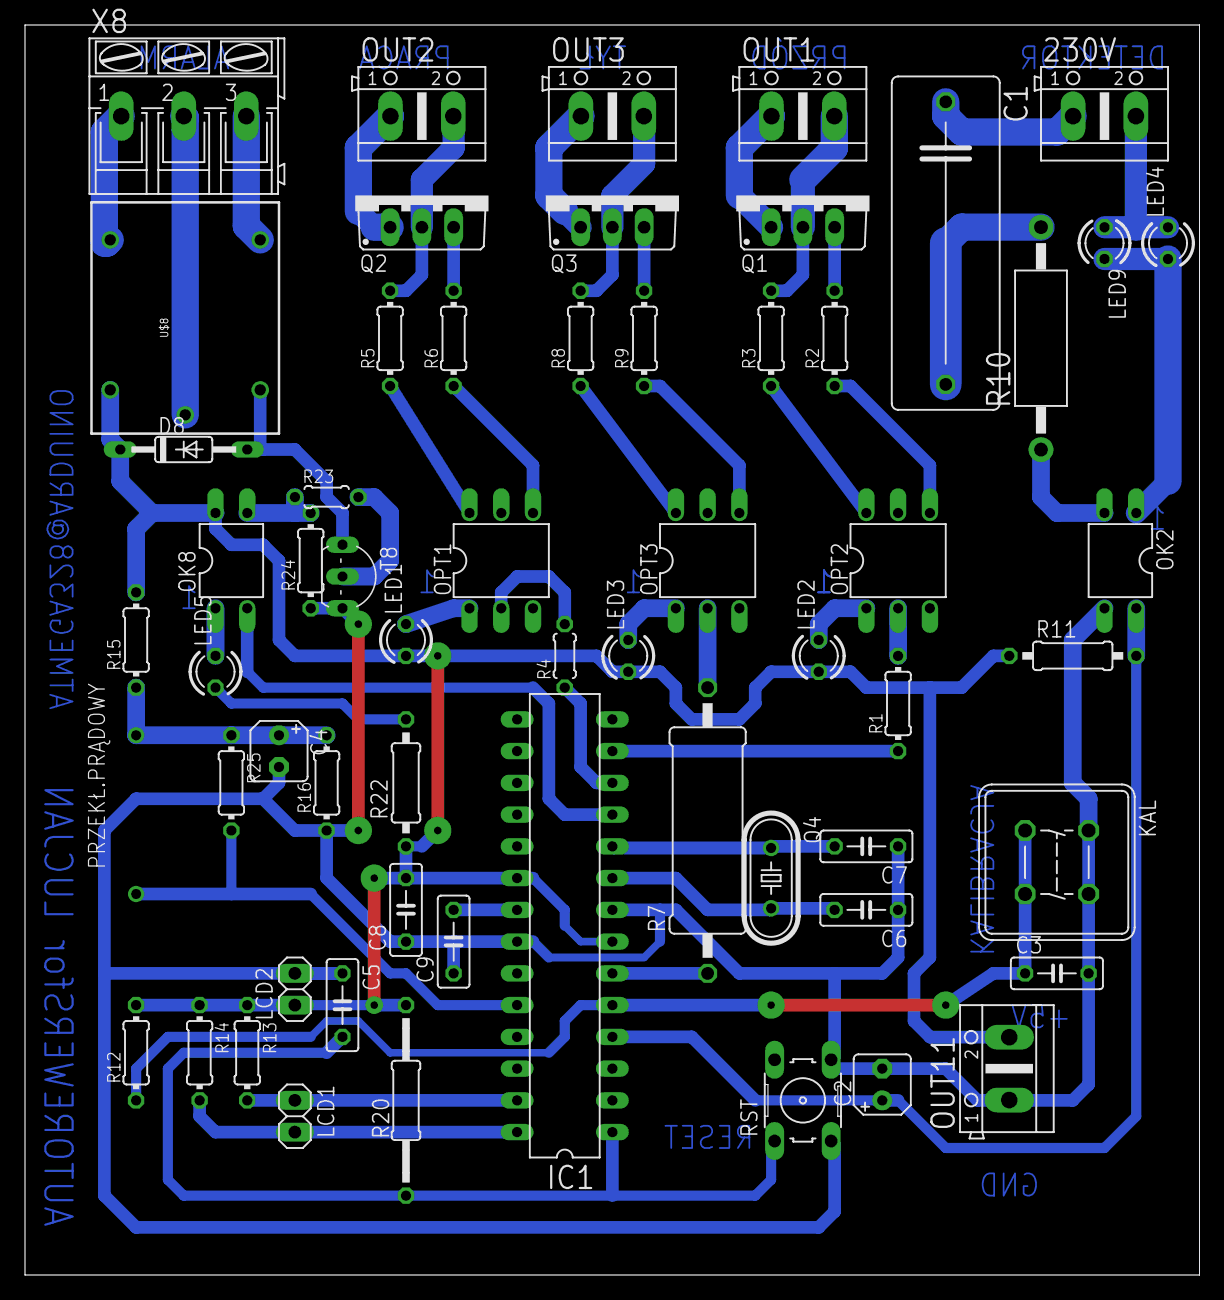
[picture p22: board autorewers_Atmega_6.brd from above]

Board: 2 copper layers, 94.0 x 100.0 mm, 60 parts (0 on the bottom side), 50 nets.

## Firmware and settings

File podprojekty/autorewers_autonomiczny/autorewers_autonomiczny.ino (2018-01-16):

/*
 * Autorewers 2.0 program v0.65 autor Stanislaw Gromowski
 * Program jest wsadem do urządzenia autorewers służącego do nadzorowania pracy podajnika
 * w piecach węglowych z podajnikiem ślimakowym.
 * Kalibracja, nacisnąć przycisk wówczas autorewer uruchomi podajnik na kilka sekund
 * i podczas jego pracy zmierzy płynący prąd przez silnik, zmierzoną wartość zapisze w pamięci eeprom.
 * Program po kalibracji prądem nominalnym podczas pracy podajnika wykrywa przeciążenie
 * silnika podajnika i uruchamia bieg wsteczny na ok 15 sekund,po czym wykonuje ruch testowy do przodu
 * jeśli zakleszczenie ustąpiło przechodzi do nadzoru, jeżeli nie,  uruchamia ponownie bieg wsteczny.
 * Cykl ten zostanie  wykonany trzykrotnie.
 * Jeśli trzy razy z rzędu nie uda mu się wejść do normalnej pracy zatrzymuje się i zgłasza alarm.
 * Wyjście z alarmu polega na odłączeniu zasilania od sterownika i ponownym podłączeniu,
 * skasowane zostaną wszystkie alarmy i autorewers wejdzie ponownie w tryb nadzoru.
 */
#include <Bounce2.h>
#include <LiquidCrystal_I2C.h>
#include <Wire.h> 
#include "EmonLib.h"                   // Include Emon Library
EnergyMonitor emon1;                   // Create an instance
#include <EEPROM.h>
LiquidCrystal_I2C lcd(0x27,2,1,0,4,5,6,7);

int I_nominalny;
int licznik_rewers;
int licznik1=0;
int k=0;
int I_nom;
int czas_cofania=15000;

float korekta_Ik=1.3;
float Irms;
float Ik;
float I_n;
float I_por;

#define BACKLIGHT_PIN 3
#define przek_podajnik 6
#define przek_rewers_t 4
#define przek_rewers_p 7
#define przek_alarm 5

int addr_I_nominalny = 0;
int addr_licznik_rewers = 1;
int wej_podajnik = 2; //konfiguracja pinow dla Bounce
int wej_kalibracja = 3; //konfiguracja pinow dla Bounce

Bounce podajnik = Bounce(wej_podajnik, 50);
Bounce kalibracja = Bounce(wej_kalibracja, 50);
//=================================================================================
void setup()
{  
  digitalWrite(6, HIGH);//wylaczenie podajnika(przekaznik stanu niskiego)
  digitalWrite(4, HIGH);//wylaczenie biegu do tylu(przekaznik stanu niskiego)
  digitalWrite(7, LOW);//wlaczenie biegu do przodu(przekaznik stanu niskiego)
  digitalWrite(5, HIGH);//wylaczenie alarmu(przekaznik stanu niskiego)
  
  pinMode(przek_rewers_t, OUTPUT);//przekaznik SSR obrotow do tylu
  pinMode(przek_rewers_p, OUTPUT);//przekaznik SSR obrotow do przodu
  pinMode(przek_podajnik, OUTPUT);//przekaznik SSR praca podajnika
  pinMode(przek_alarm, OUTPUT);//przekaznik alarmu zewnentrznego
  pinMode(wej_podajnik, INPUT);
  pinMode(wej_kalibracja, INPUT);
  
  Serial.begin(9600);
  
  lcd.begin (16,2);
  lcd.setBacklightPin(BACKLIGHT_PIN, POSITIVE);
  lcd.setBacklight(HIGH);
  
  emon1.current(1,5); // Current:pin wejsciowy, wspolczynnik kalibracji dla CTS.
 
  lcd.clear();
  lcd.setCursor(0,0);
  lcd.print("autorewers v0.65");
  lcd.setCursor(0,1);
  lcd.print("     czekaj     ");
  delay(3000);  
}
//==================================================================================
void loop()         //petla glowna programu
{
podajnik.update(); //aktualizacja stanu wejscia podajnika
int value_podajnik = podajnik.read(); //pobranie stanu wejścia podajnika
if (value_podajnik == HIGH)
{
  pod_stop();
  lcd_stop();
}

if (value_podajnik == LOW)
{
  praca();
}

kalibracja.update();  //aktualizacja stanu wejscia kalibracji
int value_kalibracja = kalibracja.read(); //pobranie stanu wejscia kalibracji
if (value_kalibracja == LOW)
{
    kalibrowanie();
}
//kasowanie_eeprom();
}

//==================================================================================
void praca()          //wykrycie przeciazenia i reakcja
{
  I_n = EEPROM.read(addr_I_nominalny);
  Ik = I_n / 100;
  I_por = Ik * korekta_Ik; //powiekszony prad nominalny
  lcd_praca();  
  pod_start();
  delay(500); //pominiecie pradu rozruchu
  Irms = emon1.calcIrms(740);  // Wyliczenie Irms ; 740:probek
  delay(50);
  if (Irms > I_por && licznik1 <4)
  {
    rewers();
  }

  if (Irms < I_por)
  {
    licznik1=0;
  }
}
//==================================================================================
void kalibrowanie()     //ustalenie pradu pracy podajnika
{
  pod_start();
  lcd.setCursor(0,0);
  lcd.print("KALIBRUJE czekaj");
  lcd.setCursor(0,1);
  lcd.print("                ");
  delay(500);
  I_nom = 0;
  for(int i=0;i<10;i++)
  {
   Irms = emon1.calcIrms(1480)* 100;
   I_nom = I_nom + Irms;
  }
  I_nominalny = (I_nom / 10);
  I_n = I_nominalny;
  Ik = I_n / 100;
  lcd.setCursor(0,1);
  lcd.print("Ik:");
  lcd.setCursor(3,1);
  lcd.print(Ik, 2);
  EEPROM.write(addr_I_nominalny,I_nominalny);
  delay(3000);  
  pod_stop(); 
}
//==================================================================================
void pod_start()    //start podajnika
{
 digitalWrite(przek_podajnik, LOW); 

}
//==================================================================================
void pod_stop()     //zatrzymanie podajnika
{
 digitalWrite(przek_podajnik, HIGH);

}
//==================================================================================
void obr_p()        //podajnik obroty przod
{
 pod_stop();
 delay(50);
 digitalWrite(przek_rewers_t, HIGH);
 delay(50); 
 digitalWrite(przek_rewers_p, HIGH);
 delay(50); 
 digitalWrite(przek_rewers_p, LOW); 
}
//==================================================================================
void obr_t()        //podajnik obroty tyl
{
 pod_stop(); 
 delay(50); 
 digitalWrite(przek_rewers_p, HIGH);
 delay(50);
 digitalWrite(przek_rewers_t, HIGH);
 delay(50);
 digitalWrite(przek_rewers_t, LOW);
}
//==================================================================================
void alarm()
{
  while (licznik1 >= 3)
  {
    pod_stop();
    digitalWrite(przek_alarm, LOW);
    lcd.setCursor(0,0);
    lcd.print(" ALARM- 3x rew. ");
    lcd.setCursor(0,1);
    lcd.print("odlacz zasilanie");
    delay(1);
  }
}
//==================================================================================
void rewers()
{
  pod_stop();
  lcd.setCursor(0,0);
  lcd.print(" UWAGA! - cofam ");
  lcd.setCursor(0,1);
  lcd.print("    czekaj      ");
  delay(1000);
  obr_t();
  delay(1000);
  pod_start();
  delay(czas_cofania);
  pod_stop();
  delay(1000);
  obr_p();
  licznik1++;
  licznik_rewers = EEPROM.read(addr_licznik_rewers)+1;
  EEPROM.write(addr_licznik_rewers,licznik_rewers);
  if (licznik1 > 3)
  {
    alarm();
  }
  else
  {
  ruch_testowy();
  }  
}
//==================================================================================
void ruch_testowy()
{
  obr_p();
  delay(1000);  
  pod_start();
  for(int b=0;b<50;b++)
  {
  delay(300); //pominiecie pradu rozruchu
  I_n = EEPROM.read(addr_I_nominalny);
  Ik = I_n / 100;
  float I_por = Ik * korekta_Ik; //powiekszony prad nominalny
  Irms = emon1.calcIrms(370);  // Wyliczenie Irms ; 740:probek
  if (Irms > I_por)
  {
    rewers();
  }
  lcd_ruch_testowy();
  }
}
//==================================================================================
void kasowanie_eeprom()
{
  while (k < 2)
  {
    EEPROM.write(addr_I_nominalny,0);
    EEPROM.write(1,0);
    k++;
    lcd.setCursor(0,0);
    lcd.print("KASOWANIE EEPROM");
    lcd.setCursor(0,1);
    lcd.print("   WYKONANO!    ");
    delay(3000);
  }

}
//==================================================================================
void lcd_praca()
{
 //I_n = EEPROM.read(addr_I_nominalny);
 //Ik = (I_n / 100)*korekta_Ik;
 lcd.setCursor(0,0);
 lcd.print("  PRACA -czekaj ");
 lcd.setCursor(0,1);
 lcd.print("Ip:");
 lcd.print(Irms, 2);
 lcd.setCursor(7,1);
 lcd.print(" Iz:");
 lcd.print(I_por, 1);  
}
//=================================================================================
void lcd_ruch_testowy()
{
 I_n = EEPROM.read(addr_I_nominalny);
 Ik = (I_n / 100)*korekta_Ik;
 lcd.setCursor(0,0);
 lcd.print("TEST odbl-czekaj");
 lcd.setCursor(0,1);
 lcd.print("Ip:");
 lcd.print(Irms, 2);
 lcd.setCursor(7,1);
 lcd.print(" Iz:");
 lcd.print(Ik, 1);  
}
//=================================================================================
void lcd_stop()
{
 I_n = EEPROM.read(addr_I_nominalny);
 Ik = I_n / 100;
 lcd.setCursor(0,0);
 lcd.print("    OCZEKUJE    ");
 lcd.setCursor(0,1);
 lcd.print("Ik:");
 lcd.print( Ik, 2);  
 lcd.setCursor(7,1);
 lcd.print("  rew:");
 lcd.print(EEPROM.read(addr_licznik_rewers));
}

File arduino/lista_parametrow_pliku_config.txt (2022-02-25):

#Konfiguracja sieci:
#Adres IP (dla automatycznej konfiguracji sieci piszemy: NET_IP=auto):
NET_IP=192.168.2.4
#Adres MAC (w hex):
NET_MAC=1A1B1C1D1E1F
#Adresy pozostale
NET_BRAMA=192.168.2.1
NET_MASKA=255.255.255.0
NET_DNS=192.168.2.1

#po ilu sekundach ma sie wygasic wyswietlacz
# zakres 0-200, gdzie 0 - nie wygaszamy
#LCD_WYGAS = 0

Parametry dmuchawy:
DM_OFFSET = 0
DM_INWERSJA_PWM = 0
DM_MODULACJA = 0
#jesli 0 - brak detektora lub detektor przed bezpiecznikiem od peryferiow
DETEKTOR_TESTUJE_BEZPIECZNIK=1

#algorytm regulacji mocy dmuchawy
# 0 stary, 1 nowy (zakres od 30 do 75% - powyzej blad/spada moc)
#DM_TYP=0

# zmiana czasu na zimowy
#RTC_ZIMA=1

#ustawianie daty/czasu w RTC - uruchamiac jednorazowo
#RTC=2017-04-07 12:13:14
#RTC_DATA=2017-04-07
#RTC_CZAS=12:13:14

# temperatura zewnetrzna auto przejscia CO w tryb lato
AUTOLATO_TEMP = 0
# histereza powrotu CO do trybu zima 1,5deg
AUTOLATO_HISTEREZA = 15
# temperatura dla twew auto przejsca CO w tryb lato
AUTOLATO_TWEW = 0
# dodatkowe tryb pracy autolato 
AUTOLATO_TRYB = 0
# poza przejsciem w tryb lato wylaczamy calkowicie piec
#AUTOLATO_TRYB = WYL_ALGO

Parametry modulacji (gdy DM_MODULACJA = 1):
DM_ROZRUCH_CZAS =
DM_ROZRUCH_MOC =
DM_PLUS_CZAS =
DM_PLUS_MOC =
DM_DOPALANIE_CZAS =
DM_DOPALANIE_MOC =
DM_TLO_MOC =

Parametry trybu zasypowego:
ZASYPOWY_MOC=30

Przypisanie wszystkich czujnikow z ecoal do sterownika
T_MAPUJ_Z_ECOAL=1
lub
T_MAPUJ_Z_BRULI=1

#przyklad mapowania czujnika dallas
# identyfikatory czujnikow dostepne pod adresem
# http://adres_ip_lucjana/dallas
#TPIEC=DALLAS[28FF265C64160379]

# mapowanie czujnika KTY81-210
# dla analogowego wejscia A1
# TPIEC = KTY81[1]

# mapowanie modulu termopary
#TSPALINY = MAX31855[0]
#TSPALINY = MAX6675[0]
# zmapowanie na pinie CS=48 i z wlaczonym filtrowaniem
#TSPALINY = MAX6675[48.1]
# mapowanie czujnika poziomu zasobnika np.:
#T4=SR04T[]

#przyklad dodania offsetu -10.0 deg do T1
#OFFSET_T1=-100

zabezpieczenie przed cofaniem sie zaru
jesli TPODAJNIK wzrosnie powyzej T_MAX, uruchamia sie podajnik 
na czas wyrzutu paliwa z podajnika 5min. i uruchamia sie alarm
PODAJNIK_CZAS_WYRZUTU = 5
PODAJNIK_T_MAX = 60
jesli TPODAJNIK wzrosnie powyzej T_WYSOKA,
uruchamia sie cykle 30s (* max ilosc powtorek jesli ustawiono) podnoszenia zaru
PODAJNIK_CZAS_PODNOSZENIA = 30
PODAJNIK_T_WYSOKA_POWTORKI = 0
PODAJNIK_T_WYSOKA = 50

#parametry podajnika tlokowego
#czasy podawania w ilosci cykli
#PODAJNIK_TLOKOWY=1
#czas pelnego ruchu tloka w sekundach
#TLOK_CZAS_CYKLU=40

# glebokosc pustego zasobnika w cm odczyt z czujnika SR04T
#PODAJNIK_GLEBOKOSC = 0

#czas w sekundach potrzebny do oproznienia pełnego zasobnika
PODAJNIK_CZAS_DO_OPROZNIENIA = 69000
#aktualny czas pozostaly do oproznienia zasobnika w sekundach
#UWAGA! po uruchomieniu zliczamy od tej wartosci
# (domyslnie 50% zasobnika) i tracimy poziom zasobnika!!
# poziom zasobnika ustawiac najlepiej przez WWW
#PODAJNIK_CZAS_PODAJNIKA = 34500
#procent ponizej ktorego ma wystapic alarm pustego zasobnika
#PODAJNIK_ALARM_MIN=15
#stała zalezna od opału w g./min.
PODAJNIK_PREDKOSC_PODAWANIA = 240

zabezpieczenie przed zbyt wysoka temperatura pieca
PIEC_T_MAX = 90

temperatura zalaczenia pomp
PIEC_T_MIN = 40
po spadku temperatury ponizej 45 generowany jest alarm
#PIEC_ALARM_T_MIN = 45

tryb pracy pieca RECZNY,AUTO
PIEC_TRYB = RECZNY
jesli piec ma automatycznie startowac po uruchomieniu - ustawiamy AUTO
w trybie recznym mozna wlaczac (1) lub wylaczac urzadzenia (0)
#OUT_PODAJNIK=1
#OUT_POMPACO=0
#OUT_POMPACWU=0
#OUT_POMPACWU2=0
#OUT_POMPACYRK=0
#moc wentylatora 50%:
#OUT_WENTYLATOR=50

algorytm pracy palnika - ECOAL,RR,RRM,RRM2,ZASYPOWY,WYLACZONY,...
PIEC_ALGORYTM = ECOAL
PIEC_ZADANA = 50
uwaga histereza pieca * 0.1deg
PIEC_HISTEREZA = 0

#zadana dla regulatora pokojowego
#TWEW_ZADANA=22
#histereza dla regulatora pokojowego
#TWEW_HISTEREZA=10

#o ile ma zostac obnizona zadana na piecu 
#gdy osiagniemy TWEW_ZADANA - ponizej o 5.0 deg.
#TWEW_CO_OBNIZONA=50

parametry algorytmu RR, czas podtrzymania w minutach, reszta w sekundach:
RR_PODTRZYMANIE_CZAS = 10
RR_PODTRZYMANIE_PODANIE = 10
RR_PODTRZYMANIE_POSTOJ = 30
RR_PODTRZYMANIE_MOC = 40
# gdy > 0 i sterownik jest w trybie lato korzystamy z czasu lato:
RR_PODTRZYMANIE_CZAS_LATO = 0

RR_PRACA_PODANIE = 10
RR_PRACA_POSTOJ = 30
RR_PRACA_MOC = 40

# 1 - wlaczone tlo, 2 - dopalanie
RRM_TLO_WLACZONE=0
RRM_TLO_MOC=20
RRM_TLO_CZAS_PODANIE=10
# w min.
RRM_TLO_CZAS=15
#jesli tlo podbije TPIEC o 15deg ponad zadana przechodzimy w podtrzymanie i wylaczamy tlo.
#RRM_MAX_PRZEBICIE_TLO=15
#prog t.zew. dla wylaczenia tla np. +2deg.
#RRM_T_WYL_TLO = 2
# dopalanie 150s 30%
RRM_DOPALANIE_MOC=30
RRM_DOPALANIE_CZAS=150

# opcje naweglania - po 5 cyklach podtrzymania wejscie w grzanie
# powoduje podanie paliwa przez 60s. (max 240s)
#RRM_NAWEGLANIE_CYKL = 5
#RRM_NAWEGLANIE = 60
# opcja opoznienia podania paliwa po przejsciu w grzanie 
# podajemy 30s pozniej
#RRM_OPOZNIENIE_PODANIA = 30
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

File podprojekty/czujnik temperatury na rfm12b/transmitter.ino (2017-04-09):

//----------------------------------------------------------------------------------------------------------------------
// TinyTX - An ATtiny84 and RFM12B Wireless Temperature Sensor Node
// By Nathan Chantrell. For hardware design see http://nathan.chantrell.net/tinytx
//
// Using the Dallas DS18B20 temperature sensor
//
// Licenced under the Creative Commons Attribution-ShareAlike 3.0 Unported (CC BY-SA 3.0) licence:
// http://creativecommons.org/licenses/by-sa/3.0/
//
// Requires Arduino IDE with arduino-tiny core: http://code.google.com/p/arduino-tiny/
// and small change to OneWire library, see: http://arduino.cc/forum/index.php/topic,91491.msg687523.html#msg687523
//----------------------------------------------------------------------------------------------------------------------

#include <OneWire.h> // http://www.pjrc.com/teensy/arduino_libraries/OneWire.zip
#include <DallasTemperature.h> // http://download.milesburton.com/Arduino/MaximTemperature/DallasTemperature_LATEST.zip
#include <JeeLib.h> // https://github.com/jcw/jeelib
#include <avr/sleep.h>

ISR(WDT_vect) { Sleepy::watchdogEvent(); } // interrupt handler for JeeLabs Sleepy power saving

#define myNodeID 2        // RF12 node ID in the range 1-30
#define network 212       // RF12 Network group
#define freq RF12_868MHZ  // Frequency of RFM12B module

//#define USE_ACK           // Enable ACKs, comment out to disable
#define RETRY_PERIOD 5    // How soon to retry (in seconds) if ACK didn't come in
#define RETRY_LIMIT 10     // Maximum number of times to retry
#define ACK_TIME 80       // Number of milliseconds to wait for an ack

#define SENSOR_RESOLUTION 10 //rozdzielczosc 10 (0,25 st, 187,5 ms) 
#define ONE_WIRE_BUS 10   // DS18B20 Temperature sensor is connected on D10/ATtiny pin 13
#define ONE_WIRE_POWER 9  // DS18B20 Power pin is connected on D9/ATtiny pin 12

OneWire oneWire(ONE_WIRE_BUS); // Setup a oneWire instance

DallasTemperature sensors(&oneWire); // Pass our oneWire reference to Dallas Temperature
DeviceAddress sensorDeviceAddress;
int  delayInMillis = 0;


//########################################################################################################################
//Data Structure to be sent
//########################################################################################################################

 typedef struct {
  	  int temp;	// Temperature reading
  	  int supplyV;	// Supply voltage
 } Payload;

 Payload tinytx;

// Wait a few milliseconds for proper ACK
 #ifdef USE_ACK
  static byte waitForAck() {
   MilliTimer ackTimer;
   while (!ackTimer.poll(ACK_TIME)) {
     if (rf12_recvDone() && rf12_crc == 0 &&
           rf12_hdr == (RF12_HDR_DST | RF12_HDR_CTL | myNodeID))
        return 1;
      set_sleep_mode(SLEEP_MODE_IDLE);
      sleep_mode();     
   }
   return 0;
  }
 #endif

//--------------------------------------------------------------------------------------------------
// Send payload data via RF
//-------------------------------------------------------------------------------------------------
 static void rfwrite(){
  #ifdef USE_ACK
   for (byte i = 0; i < RETRY_LIMIT; ++i) {  // tx and wait for ack up to RETRY_LIMIT times
     rf12_sleep(-1);              // Wake up RF module
      while (!rf12_canSend())
      rf12_recvDone();
      rf12_sendStart(RF12_HDR_ACK, &tinytx, sizeof tinytx); 
      rf12_sendWait(2);           // Wait for RF to finish sending while in standby mode
      byte acked = waitForAck();  // Wait for ACK
      rf12_sleep(0);              // Put RF module to sleep
      if (acked) { return; }      // Return if ACK received
  
   Sleepy::loseSomeTime(RETRY_PERIOD * 1000);     // If no ack received wait and try again
   }
  #else
     rf12_sleep(-1);              // Wake up RF module
     while (!rf12_canSend())
     rf12_recvDone();
     rf12_sendStart(0, &tinytx, sizeof tinytx); 
     rf12_sendWait(2);           // Wait for RF to finish sending while in standby mode
     rf12_sleep(0);              // Put RF module to sleep
     return;
  #endif
 }



//--------------------------------------------------------------------------------------------------
// Read current supply voltage
//--------------------------------------------------------------------------------------------------
 long readVcc() {
   bitClear(PRR, PRADC); ADCSRA |= bit(ADEN); // Enable the ADC
   long result;






   // Read 1.1V reference against Vcc
   #if defined(__AVR_ATtiny84__) 
    ADMUX = _BV(MUX5) | _BV(MUX0); // For ATtiny84
   #else
    ADMUX = _BV(REFS0) | _BV(MUX3) | _BV(MUX2) | _BV(MUX1);  // For ATmega328
   #endif 
   delay(2); // Wait for Vref to settle
   ADCSRA |= _BV(ADSC); // Convert
   while (bit_is_set(ADCSRA,ADSC));
   result = ADCL;
   result |= ADCH<<8;
   result = 1126400L / result; // Back-calculate Vcc in mV
   ADCSRA &= ~ bit(ADEN); bitSet(PRR, PRADC); // Disable the ADC to save power
   return result;
} 
//########################################################################################################################

void setup() {

  
  rf12_initialize(myNodeID,freq,network); // Initialize RFM12 with settings defined above 
  rf12_sleep(0);                          // Put the RFM12 to sleep

  pinMode(ONE_WIRE_POWER, OUTPUT); // set power pin for DS18B20 to output
  
  PRR = bit(PRTIM1); // only keep timer 0 going
  
  ADCSRA &= ~ bit(ADEN); bitSet(PRR, PRADC); // Disable the ADC to save power

}

void loop() {
  
  digitalWrite(ONE_WIRE_POWER, HIGH); // turn DS18B20 sensor on

  //Sleepy::loseSomeTime(5); // Allow 5ms for the sensor to be ready
  //delay(188); // The above doesn't seem to work for everyone (why?)
  delayInMillis = 750 / (1 << (12 - SENSOR_RESOLUTION)); //ustawia delay
  delay(delayInMillis); //wlacza ustawiony delay
 
  sensors.begin(); //start up temp sensor
  sensors.getAddress(sensorDeviceAddress, 0); //pobiera adres ds-a
  sensors.setResolution(sensorDeviceAddress, SENSOR_RESOLUTION); //ustawia rozdzielczosc
  sensors.requestTemperatures(); // Get the temperature
  tinytx.temp=(sensors.getTempCByIndex(0)*100); // Read first sensor and convert to integer, reversed at receiving end
  
  digitalWrite(ONE_WIRE_POWER, LOW); // turn DS18B20 off
  
  tinytx.supplyV = readVcc(); // Get supply voltage

  rfwrite(); // Send data via RF 

  for (byte i = 0; i < 5; ++i)
     Sleepy::loseSomeTime(60000); //JeeLabs power save function: enter low power mode for 60 seconds (valid range 16-65000 ms)

}

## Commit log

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2015-12-08 - lista parametrów ktore mozna zapisac w pliku config.txt na karcie SD
    [lista_parametrow_pliku_config.txt]
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2016-02-04 - nowe parametry w pliku config.txt - dodanie wylaczania dmuchawy na pin 8 - zmiana opisow wyjsc PWM
    [lista_parametrow_pliku_config.txt]
2016-02-04 - zmieniona predkosc terminala (115200,8N1) - dodane przeszukiwanie magistrali na DS18xx - dodane wywolanie ze strony "/reset" restart arduino przydatne po aktualizacji pliku config.txt
2016-02-06 v 0.1.0.6 - pwm tylko na pin 12 - dodanie parametru inwersji pwm
    [lista_parametrow_pliku_config.txt]
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2016-03-04 v0.1.0.19 test - dodane mapowanie - moga byc bledy, jeszcze nie testowane - zaktualizowana strona www teraz obsluguje wszystkie czujniki
    [lista_parametrow_pliku_config.txt]
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2016-03-08 - skrypt dla rpi do resetowania arduino
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2016-03-16 v0.1.0.30 dodanie algorytmu RR plus wiecej info nizej ... nie forsujemy podajnika i wentylatora jesli nie jest to algorytm ECOAL dodanie algorytmu RR parametry dla RR (opis w pliku tekstowym) funkcja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
    [lista_parametrow_pliku_config.txt]
2016-03-17 v0.1.0.31 dodanie algorytmu RRP oraz poprawki dla RR poprawienie pracy podajnika - brakowalo wylaczania po czasie dodatkowe informacje o stanie RR w terminalu czyszczenie kodu poprawka na pompe co - 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
    [lista_parametrow_pliku_config.txt]
2016-03-18 v0.1.0.32 zmiana nazwy RRP na RRM - Retortowy Reczny Modulowany pompa cwu2 moze pracowac w trybie mieszanie (powyzej zadanej uruchamia pompe) konfiguracja dla cwu2 zabezpieczenie przed max temperatur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
    [lista_parametrow_pliku_config.txt]
2016-03-18 v0.1.0.33 - dodanie pracy w szerszej histerezie dla RR/RRM - histereza w 0.1deg
    [lista_parametrow_pliku_config.txt]
2016-03-27 v0.1.0.40 dodanie czasu oprozniania zasobnika, ograniczenie strony do 1 zapytania nowe parametry w pliku: #czas w sekundach potrzebny do oproznienia pełnego zasobnika PODAJNIK_CZAS_DO_OPROZNIENIA = 6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
    [lista_parametrow_pliku_config.txt]
2016-03-28 v0.1.0.41 dodanie timera zliczajacego do zera dla zasobnika zmiana w parametrach:
    #aktualny czas pozostaly do oproznienia zasobnika w sekundach
    #po uruchomieniu zliczamy od tej wartosci (domyslnie 50% zasobnika)
    PODAJNIK_CZAS_PODAJNIKA = 34500
    [lista_parametrow_pliku_config.txt]
2016-03-29 v0.1.0.42 dodanie alarmu stanu minimalnego zasobnika, domyslna wartosc w procentach: PODAJNIK_ALARM_MIN=15 dodanie alarmow do danych na strone czas podajnika moze byc rowny 0 w konfigu dodanie wywola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
    [lista_parametrow_pliku_config.txt]
2016-04-01 v0.1.0.43 porzadki w konfiguracji sieci - nowe parametry,ster juz nie dzałają - poprawka w odczycie paramtrów podajnika
    #Konfiguracja sieci:
    #Adres IP (dla automatycznej konfiguracji sieci piszemy: NET_IP=auto):
    NET_IP=192.168.2.4
    #Adres MAC (w hex):
    NET_MAC=1A1B1C1D1E1F
    #Adresy pozostale
    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
    [lista_parametrow_pliku_config.txt]
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2016-09-25 v.0.1.0.47: - dodanie do pliku parametrow krzywej grzania i zaworu 4D - dodanie wyjsc odworconych (przekazniki) dla 4D_Otwieranie i 4D_zamykanie - dodanie wyjscia A8/!28 dla pompy cyrkulacji cwu - po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
    [lista_parametrow_pliku_config.txt]
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2016-09-27 v0.1.0.51 - testujemy zawor 4D - zapamietujemy czy uzywamy polaczenia ecoal/bruli czy nie - korzystamy z czujnika zaworu 4D - dodanie parametru czujnika zaworu 4D - wlaczanie i wylaczanie pompy cyrku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
    [lista_parametrow_pliku_config.txt]
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2016-10-17 v0.1.0.59 - dodanie informacji o obnizeniu t.za zaworem na strone - nowy parametr ZAWOR4D-OBNIZONA, przy zwartym wejsciu A6 do masy obniza temperature zadana za zaworem 4D - poprawienie pracy rozruch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
    [lista_parametrow_pliku_config.txt]
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2016-10-20 v0.1.0.61 - przyspieszenie restartu sterownika - dodanie mapowania dla MAX31855 przyklad: TSPALINY = MAX31855[0]
    [lista_parametrow_pliku_config.txt]
2016-10-29 v0.1.0.63 - Pompa CYRKULACJI dziala teraz tylko jesli jest w harmonogramie. - dodanie wczytywania harmonogramu z konfiguracji - dodanie mozliwosci podejrzenia harmonogramu - dodanie obslugi harmonogr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
    [lista_parametrow_pliku_config.txt]
2016-11-03 v0.1.0.65 - RTC: czas zimowy - buzzer na pinie 31, sygnalizuje alarm - www: mozliwosc skasowania bledu ze strony
    [lista_parametrow_pliku_config.txt]
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2016-11-12 v0.1.0.69 - fix warningu kompilatora - LCD: dodanie informacji o temperaturach CO/CWU podczas pracy - LCD: dodanie obslugi LCD - LCD: dodanie monitu o wersji Lucjana podczas uruchamiania - dodanie wy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
2016-11-16 v0.1.0.71 - Z4D: dodanie histerezy - Z4D: dodanie trybu pracy - Z4D: dodanie zadanej jako stałej - KRZYWA: kontrola zakresu danych
    [lista_parametrow_pliku_config.txt]
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2017-01-24 v0.1.0.95 - LCD: poprawne usuniecie problemow z TZEWN na wyswietlaczu - dodanie opcji DETEKTOR_TESTUJE_BEZPIECZNIK=1 dla osob ktorym nie dziala detektor lub nie testuja nim bezpiecznika 0 - wylacza b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
    [lista_parametrow_pliku_config.txt]
2017-01-29 v0.1.0.96 - dodanie mozliwosci przypisania offsetu do czujnika przykład offset -10.0 deg.: OFFSET_T1=-100
    [lista_parametrow_pliku_config.txt]
2017-01-29 v0.1.0.97 - pompa CO - dodanie trybu cyklicznego - NTP odpytujemy co 24h - wstepna wersja testowa pracy RRM z tlem - domyslnie wylaczona
    [lista_parametrow_pliku_config.txt]
2017-01-30 v0.1.0.98 - czesciowe dodanie nowej wersji dopalania - podajnik: dodanie informacji w terminalu o czasie wystapienia wysokiej temperatury wraz z danymi o jej wartosci - podajnik: dodanie wczesnego za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
    [lista_parametrow_pliku_config.txt]
2017-02-07 v0.1.0.110 - dodanie debugu do max31855k - poprawki w statystykach
    - dodanie opisu do nowosci - tlo/dopalanie/wielemocy
    [lista_parametrow_pliku_config.txt]
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2017-02-19 v0.1.0.113 - zmiana zachowania pieca po uruchomieniu - startuje w trybie recznym aby pracowal w auto dodac linijke PIEC_TRYB = AUTO - w trybie recznym: dodanie mozliwosci sterowania wyjsciami z www/t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
    [lista_parametrow_pliku_config.txt]
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2017-03-29 v0.1.0.118 - zwiekszenie ilosci mocy RRW do 10szt. - dodanie mozliwosci wyboru czujnika oraz histerezy dla CWU2
    [lista_parametrow_pliku_config.txt]
2017-04-02 v0.1.0.119 - dodanie algorytmu zasypowego: ZASYP_MOC=30 ustawia moc nadmuchu dla trybu zasypowego
    [lista_parametrow_pliku_config.txt]
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2018-11-26 dodanie schematu dla aktywnego podciagniecia poprawia mozliwosc pomiaru temperatury na dluzszych odleglosciach pod warunkiem ze nie ma problemow z komunikacja
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
